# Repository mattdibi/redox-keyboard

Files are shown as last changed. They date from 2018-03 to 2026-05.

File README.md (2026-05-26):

<p align="center">
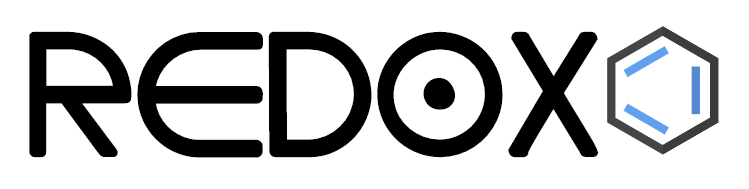
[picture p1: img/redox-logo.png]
Redox logo

QMK

</p>

<h3 align="center">The Redox project repository</h3>

<div align="center">

[]()




</div>

---

The Redox project is an open-source, [QMK (Quantum Mechanical Keyboard Firmware)](https://github.com/qmk/qmk_firmware) powered, ergonomic split mechanical keyboard. This repository will be used to share information about the project and instruction on how to use and assemble the Redox keyboard.

<p align="center">
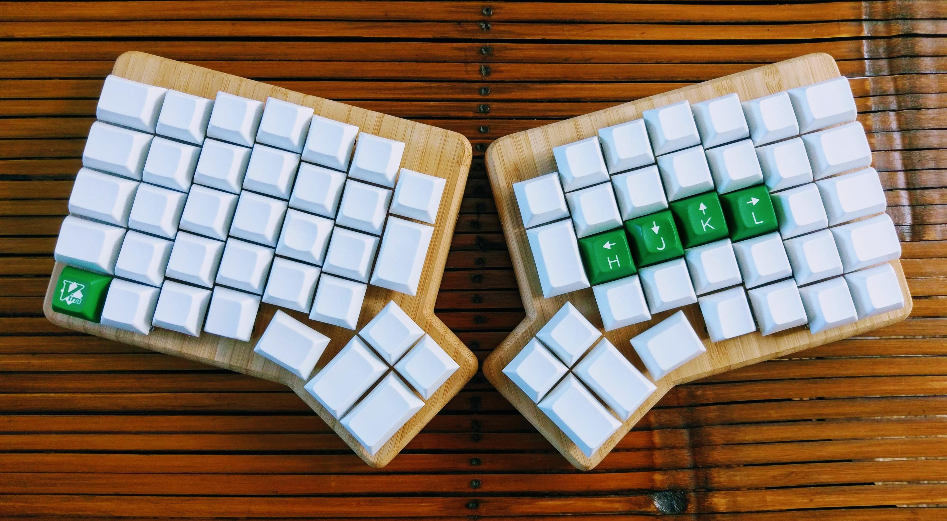
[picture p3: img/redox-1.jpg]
Redox

</p>

**Designer's bio**: [Mattia Dal Ben (aka u/TiaMaT102)](mailto:matthewdibi@gmail.com) obtained a master's degree in Electrical Engineering with a specialization in Computer Science at the University of Udine. Currently works as a Software Engineer in R&D department for a big IoT and Embedded Computers company. Mechanical keyboard enthusiast and maker, the Redox keyboard is the result of all of his passions.

## Rationale

The Redox is a keyboard project designed with ergonomics in mind. It uses Cherry MX style mechanical switches laid out in a 7x5 columnar stagger layout with components that can easily be sourced.

The design was heavily inspired by the [Ergodox keyboard](https://www.ergodox.io/), and its main goal is to reduce the size without sacrificing too many keys, hence the name **Re**duced Ergo**dox**.

As an Ergodox user I couldn't ignore the few flaws of the original design and in a moment of arrogance I tried to fix them, thus the Redox features:
- Easier to reach thumb cluster.
- Additional easy-to-reach rotated 1.25u thumb key.
- Reduced size.
- Reduced costs (the Redox uses Arduino Pro Micro instead of the Teensy 2.0).
- Either half can be plugged in to the PC since each half can act as the master.
- Either half can work as a standalone keyboard to be used as a macropad/gaming keyboard.
- RGB backlighting support.
- 3D-printer friendly case.
- Wireless [see section below](#wireless-implementations)
- [VIA](https://caniusevia.com/) compatible (thanks to [Harshit Goel](https://github.com/harshitgoel96))
- [ZMK firmware](https://zmk.dev/) compatible (thanks to [toddmok](https://github.com/toddmok))
- [KMK firmware](http://kmkfw.io/) compatible

## Related Projects

- [**Redox handwire**](https://www.thingiverse.com/thing:2704567): The first incarnation of the Redox keyboard. It consists of a 3D-printed case and a handwired matrix.
  - [Tilted Redox case](https://www.thingiverse.com/thing:2767216): tilted case for the Redox prototype by jschloer.
    - [Tilted redox case pro micro](https://www.printables.com/model/382413-tilted-redox-case-for-micro-and-usbc): Remix of the tilted case to support pro micro and usb c instead of TRRS. 

  - [couscous-kbd](https://gitlab.com/cschalkwijk/couscous-kbd): Redox-inspired parametric OpenSCAD keyboard design.
  - [Redox tenting kit](https://www.thingiverse.com/make:484843): modified base to support tenting, mini-USB for the interconnect, and a hole for microswitch for reset needed when uploading new firmware by [Lenbok](https://github.com/Lenbok).
  - [Iris-inspired Redox case](https://github.com/Lenbok/scad-redox-case): a case inspired both by the Redox rev1.0 and the Iris designed with OpenSCAD by [Lenbok](https://github.com/Lenbok).
  - [Redodactyl keyboard](https://www.reddit.com/r/MechanicalKeyboards/comments/9j5pw5/enter_the_redodactyl_first_build/): handwired 3D printed Dactyl-inspired Redox variant by u/darknao.
- [**Redox Manuform**](https://www.thingiverse.com/thing:3503380): full rework of the Redox case inspired by the Dactyl Manuform. Designed by [Fosk\_LL](https://www.thingiverse.com/Fosk_LL/about).
- [**Redox rev1.0**](https://github.com/mattdibi/redox-keyboard/tree/master/redox): the Redox rev 1.0 is the first commercially available version of the Redox keyboard.
	- Rev1.0 PCBs: available at [Falbatech's store](https://falbatech.click/products/REDOX-PCB-Electrical-Boards-Set-of-2-p613836203)
    - Firmware sources:
        - [QMK firmware for Redox](https://github.com/mattdibi/qmk_firmware/tree/master/keyboards/redox)
        - [KMK firmware for Redox](https://github.com/KMKfw/kmk_firmware/tree/master/boards/redox)
	- 3D-printable cases:
        - [3D printable case](https://www.thingiverse.com/thing:2886662), freely available.
        - [Redox keyboard case (high profile)](https://www.thingiverse.com/thing:3825752), by [Michele Ferri](https://www.thingiverse.com/sako83/about).
        - [Travel-friendly Redox Keyboard case](https://www.thingiverse.com/thing:3607303), by [Fosk\_LL](https://www.thingiverse.com/Fosk_LL/about).
        - [Redox Neodox case](https://github.com/Pastitas/Redox-neodox-Case), by [Pastitas](https://github.com/Pastitas)
        - [Redox big battery](https://github.com/marco-silvestri/redox-big-battery), by [Marco Silvestri](https://github.com/marco-silvestri).
	- Commercially available cases:
		- [Falbatech's bamboo cases with tilt kit](https://falbatech.click/products/REDOX-Standard-LIFT-Bamboo-Wood-Case-with-oil-finish-p613843480)
		- [Falbatech's fullhand bamboo cases](https://falbatech.click/products/search?keyword=redox%20fullhand%20bamboo)
- [**Redox rev1.0W**](https://github.com/mattdibi/redox-keyboard/tree/master/redox-w): the Redox rev 1.0W is the wireless version of the Redox keyboard.
    - Rev1.0W PCBs: gerbers available in [this repo](https://github.com/mattdibi/redox-keyboard/tree/master/redox-w/rev1.0W).
    - Falbatech's Rev1.0W Hot-swap PCBs: available at [Falbatech's store](https://falbatech.click/products/REDOX-Wireless-PCB-Electrical-Boards-Set-of-2-receiver-PCB-p613839986) (Incompatible with the 3D-printable cases down below)
    - Firmware sources:
        - [QMK firmware for Redox wireless](https://github.com/mattdibi/qmk_firmware/tree/master/keyboards/redox_w)
        - [Nordic MCUs firmware for Redox wireless](https://github.com/mattdibi/redox-w-firmware)
	- 3D-printable cases:
        - [3D printed case](https://github.com/mattdibi/redox-keyboard/tree/master/redox-w/case), freely available.
        - [Redox Neodox case](https://github.com/Pastitas/Redox-neodox-Case), by [Pastitas](https://github.com/Pastitas)
    - Commercially available cases (only compatible with the Falbatech's store PCBs):
        - [Falbatech's bamboo cases with tilt kit](https://falbatech.click/products/REDOX-Wireless-Standard-LIFT-Bamboo-Wood-Case-with-oil-finish-ver-1-p613842405)
		- [Falbatech's fullhand bamboo cases](https://falbatech.click/products/search?keyword=redox%20wireless%20bamboo%20fullhand)
- [**Redox rev2.0WHS**](https://github.com/mattdibi/redox-keyboard/tree/master/redox-w): the Redox rev 2.0WHS is the wireless hot-swappable version of the Redox keyboard.
    - Rev2.0WHS PCBs: gerber files available [here](https://github.com/mattdibi/redox-keyboard/tree/master/redox-w/rev2.0WHS/pcb)
    - Firmware sources:
        - [QMK firmware for Redox wireless](https://github.com/mattdibi/qmk_firmware/tree/master/keyboards/redox_w)
        - [Nordic MCUs firmware for Redox wireless](https://github.com/mattdibi/redox-w-firmware)
	- 3D-printable case:
        - [3D printed case](https://github.com/mattdibi/redox-keyboard/tree/master/redox-w/rev2.0WHS/case), freely available.

## Wireless Implementations

The Redox keyboard uses three different wireless implementations, differentiated by firmware:
 - *QMK based*: Leveraging the [Gazel protocol](https://developer.nordicsemi.com/nRF5_SDK/nRF51_SDK_v5.x.x/doc/5.2.0/html/a00140.html). It needs its own PCB and a receiver dongle (see [Redox Wireless](https://github.com/mattdibi/redox-keyboard/tree/master/redox-w) for details) and needs three YJ-14015 MCUs + a Pro Micro compatible controller.
 - *ZMK based*: Leveraging the Bluetooth protocol. It is based on the [Redox wired PCB](https://github.com/mattdibi/redox-keyboard/tree/master/redox) and the [nice!nano](https://nicekeyboards.com/nice-nano/) controller.
 - *KMK based*: Adding [Bluetooth Split](http://kmkfw.io/docs/split_keyboards#bluetooth-split-aka-no-trrs-currently-in-testing) code to `boards/redox/main.py`. Combined with a [compatible](http://kmkfw.io/docs/Officially_Supported_Microcontrollers) wireless controller completes wireless configuration. Would advice adding [Bluetooth keycodes](http://kmkfw.io/docs/keycodes#bluetooth-keys) in keymap; `keyboard.keymap` element in `main.py`.

 The notable differences for the three implementations are as follows:
 - _Battery life_: QMK Redox Wireless uses two CR2032 coin cell batteries which last [approximately one year (YMMV)](https://github.com/mattdibi/redox-keyboard/tree/master/redox-w#battery-usage), while the nice!nano support LiPo rechargable batteries (you can choose the capacity you want but expect them to last for a [few weeks on a single charge](https://zmk.dev/power-profiler)).
 - _Flexibility_: The receiver dongle limits the flexibility of QMK Redox Wireless.
 - _Cost_: The 3x YJ-14015 + Pro Micro combo is cheaper than two wireless controllers required for ZMK and wireless KMK.
 - _Range_: Bluetooth implementations, of ZMK and KMK, should be more capable than what can be achieved with the QMK Redox Wireless (At this point in time, I lack the evidence to support these claims though).

## Physical Key Layout

<p align="center">
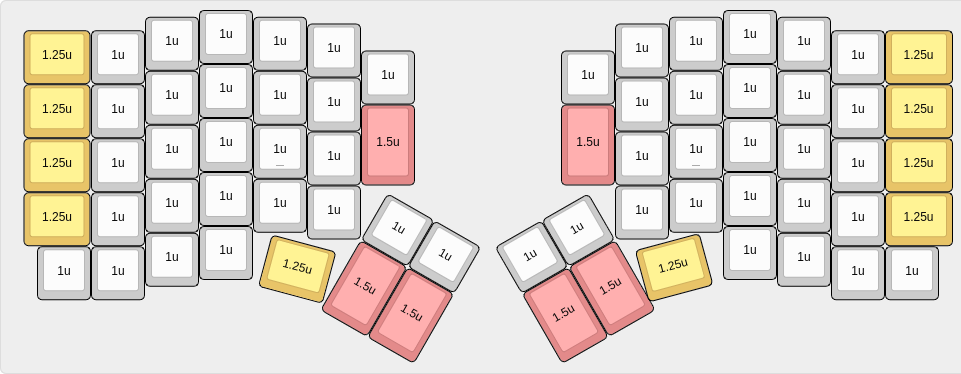
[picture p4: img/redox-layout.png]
Redox layout

</p>

### Keycaps

| Size  | Qty | Notes |
|---|:---:|:---:|
| 1.5u  | 6 | |
| 1.25u |  10 | You can get away with 8 if you use two 1u keycaps for the 1.25u rotated keys |
| 1u |  54 | |

> :information_source: On [pimpmykeyboard.com](https://pimpmykeyboard.com/sa-1976-keyset-two-shot/) site you can find a SA 1976 keyset kit specifically made for the Redox keyboard: the "Ergo Redox kit (12 keys)".

## Affiliations

In partnership with Falbatech you can now use the code "**mattdibi05**" on Falbatech's store for a 5% OFF special discount.

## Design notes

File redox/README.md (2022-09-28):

# Redox rev 1.0

The Redox rev 1.0 is the first commercially available version of the Redox keyboard.

Hardware availability:
  - [Falbatech](https://falba.tech/)

## Summary

  - [Bill of materials](#bill-of-materials)
  - [Other assembly guides](#other-assembly-guides)
  - [Assembly guide](#assembly-guide)
  - [Firmware](#firmware)
  - [Hot swappable mod](#hot-swappable-mod)
  - [RGB Underglow](#rgb-underglow)

## Bill of materials

| Qty | Item | Notes |
|----:|---|---|
|  70 | Cherry MX compatible switches | |
| 2 | Redox PCBs | [Available here](https://falba.tech/product/redox-pcb-electrical-boards-set-of-2/)|
|  70 | 1N4148 diodes | SMD diodes can also be used |
| 2 | PJ-320A 4 poles 3.5 mm TRRS connectors | |
| 2 | 4.7 kOhm resistors | Need to be soldered on one half only |
| 2 | Through hole momentary switch | Dimensions 6mm x 6mm x 4.3mm |
| 2 | Arduino Pro Micro compatible microcontrollers | Beware of the infamous Green Pro Micro, see note below. |
| 1 | TRRS cable | |
| 1 | USB micro cable | |
|  70 | Cherry MX compatible keycaps | 10x 1.25u keycaps, 6x 1.5u keycaps, 54x 1u keycaps  |
|  14 | WS2812/WS2812B leds | Optional RGB-underglow |

> :warning: Pay attention to the Pro Micro you use in this project. Online you can find the infamous **Green Pro Micros** which have the same pinout of the normal Pro Micro but use a different power circuitry. Being the Redox a split keyboard that relies on detecting which side is directly powered to find which side is the master, these clones are not suited for the task. A more detailed explanation [here](http://www.40percent.club/2017/09/green-pro-micro.html). Please note that they can come in different colors, not necessarily green.

> :warning: Before you start, flash the [Firmware](#firmware) to the ProMicros to make sure they are alright.

## Other assembly guides

External links to some other guides to building the Redox keyboard:

- ["*Build your own keyboard*"](https://medium.com/@costask/build-your-own-keyboard-5df65cb68839) by @costask.
- [Imgur build log](https://imgur.com/a/a6ck2Nc) (3D printed case).
- ["*First Homebrew Keyboard -redox Build Log-*"](https://x1.inkenkun.com/archives/6007) by [インケンch](https://www.youtube.com/channel/UCXJZdip7JmW74HQHCtfYzFw) (Japanese only)
- ["*Split Keyboard Build*"](https://kubami.com/articles/split-keyboard-build/) by Kuba Misiorny @kubami.
- [Wooden case build with hand tools](https://www.instructables.com/Redox-Keyboard-With-Wooden-Case/) by Cédric Bosdonnat

### Video guides

Two great video guides by [インケンch](https://www.youtube.com/channel/UCXJZdip7JmW74HQHCtfYzFw) (Japanese only).

<p align="center">
<a href="http://www.youtube.com/watch?v=EVRlU_eR9j4">Redox hardware assembly</a>
<a href="http://www.youtube.com/watch?v=jRIRdfIIa1Q">Redox firmware</a>
</p>

Another great guide by [Antonio Raptors](https://www.youtube.com/channel/UCNYbiq6AH8AdYTKMokKaviQ) (Spanish only).

<p align="center">
<a href="https://www.youtube.com/watch?v=wRvfs1tUpZ4">Como hacer un teclado mecánico para diseño / gaming - REDOX ESPAÑOL</a>
</p>

## Assembly guide

<p align="center">
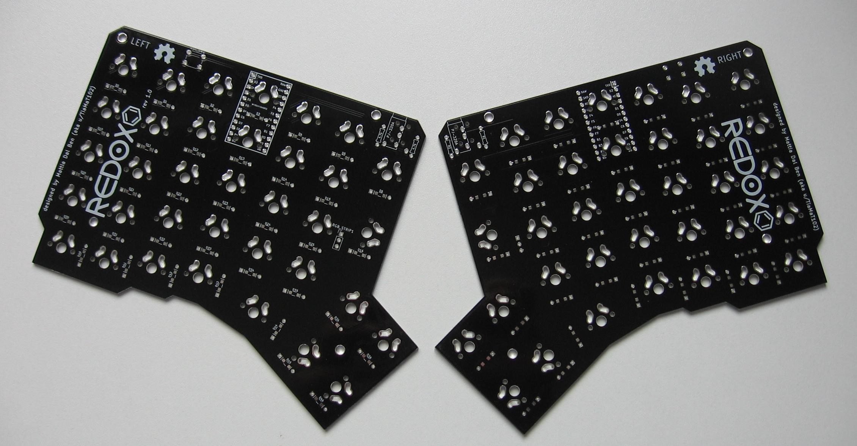
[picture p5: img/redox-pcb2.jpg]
Redox PCBs

</p>

Installation steps:

- Solder components:
  1. Solder 1N4148 diodes. Keep the diode legs for the right hand controller installation.
  2. Solder PJ-320A connectors.
  3. Solder momentary switches.
  4. Solder 4.7k Ohm resistors **on one half only**. If you are going for the RGB-underglow ignore this step.
  5. Solder the Pro Micro header pins (**do not solder the Pro Micro controllers yet**). This step may differ depending on which case you're using. Refer to the following:
    * See 3D-Printed case [right hand controller installation detail](#3d-printed-case-assembly).
    * See Falbatech's [bamboo case](#falbatechs-bamboo-case-assembly).
    * See [socketed Pro Micro installation guide](#pro-micro-sockets).
  6. Optional see [RGB-underglow instructions](#rgb-underglow).
- Flip the PCBs.
- Solder switches to the PCB.
  * If you want hot swappable switches, see
    [the hot swappable switch instructions](#hot-swappable-switches).
- Flip the PCBs again.
- Solder Pro Micros to the header pins **following the PCB labeling**. The Pro Micro on the right half should be installed with the bottom facing the Redox PCB, the Pro Micro on the left half should be installed with the bottom facing away from the PCB. See [pictures](#left-hand-back-side-1) for details.

##### Right hand back side:
<p align="center">
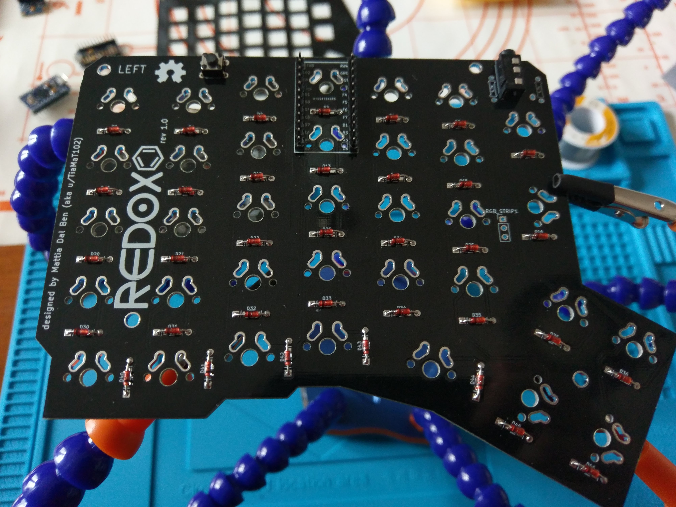
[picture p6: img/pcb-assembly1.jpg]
Right hand back side

</p>

##### Left hand back side:
<p align="center">
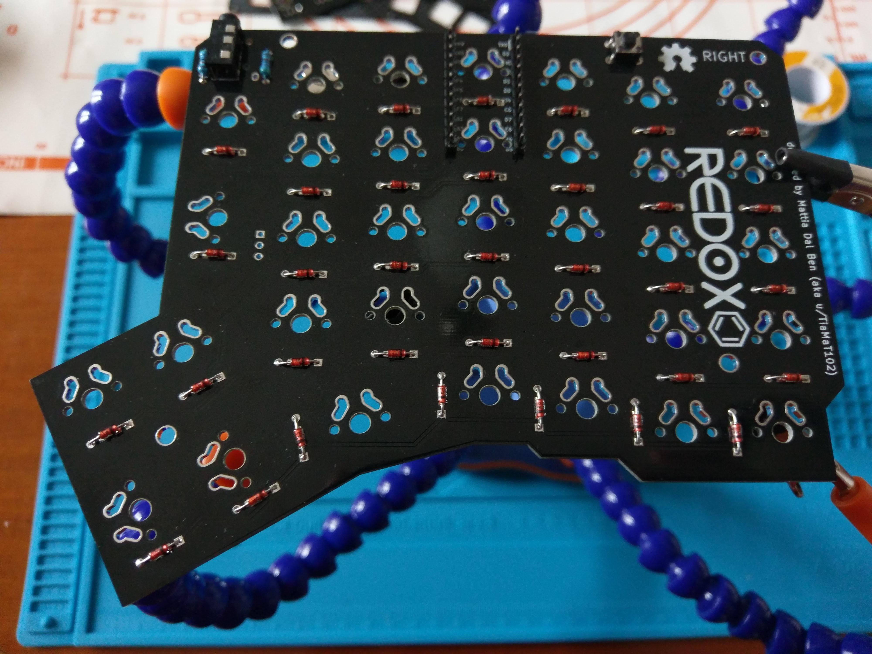
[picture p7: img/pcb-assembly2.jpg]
Left hand back side

</p>

##### Diode installation detail:
<p align="center">
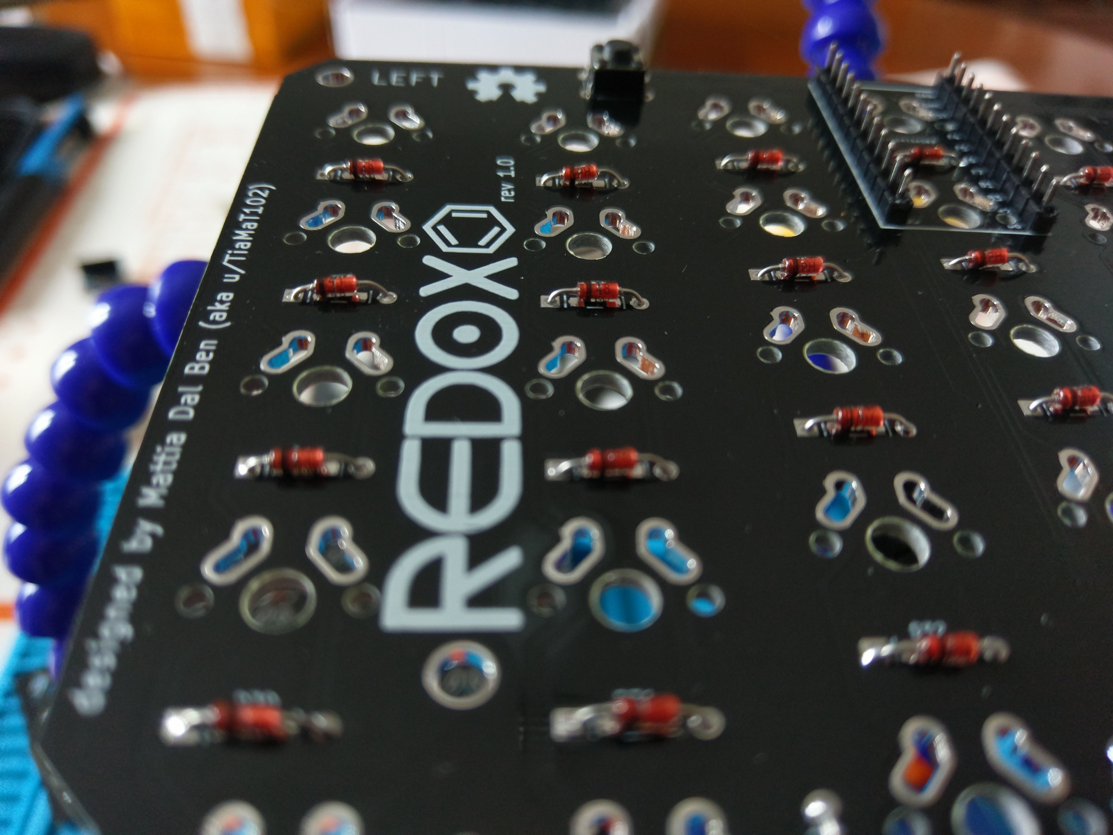
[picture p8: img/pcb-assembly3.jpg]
Diode installation detail

</p>

### 3D Printed case assembly

To lower the build costs I designed a 3D printable case which you can find in this repository or on [thingiverse](https://www.thingiverse.com/thing:2886662), feel free to modify it to best suit your needs.

<p align="center">
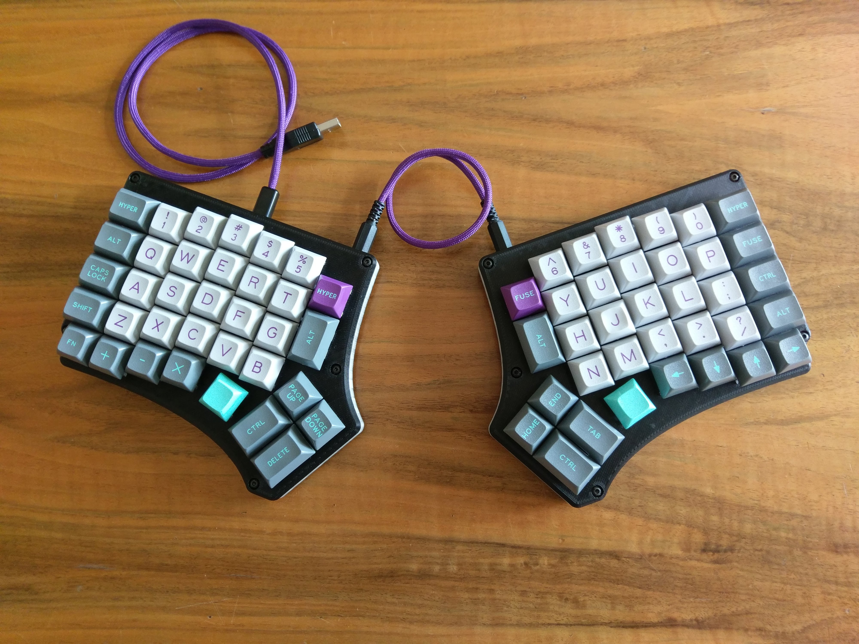
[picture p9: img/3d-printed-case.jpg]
3D printed case

</p>

Parts:

| Qty | Item | Notes |
|----:|---|---|
| 1 | Left top plate | [RedoxRev1TopLeft.STL](https://github.com/mattdibi/redox-keyboard/blob/master/redox/case/RedoxRev1TopLeft.STL)|
| 1 | Left bottom | [RedoxRev1BottomLeft.STL](https://github.com/mattdibi/redox-keyboard/blob/master/redox/case/RedoxRev1BottomLeft.STL)|
| 1 | Right top plate | [RedoxRev1TopRight.STL](https://github.com/mattdibi/redox-keyboard/blob/master/redox/case/RedoxRev1TopRight.STL)|
| 1 | Right bottom | [RedoxRev1BottomRight.STL](https://github.com/mattdibi/redox-keyboard/blob/master/redox/case/RedoxRev1BottomRight.STL)|
|  10 | M3 x 8mm (or 5mm) screws | |

For the Pro Micro installation on the right hand use the diodes legs leftover from previous steps as this will make the controller's USB port much closer to the PCB, this is needed for the USB connector to fit in the 3D printed case. If you're using Falbatech's bamboo case this is not needed and you can use standard header pins. Right hand controller installation detail:

1. Use a breadboard to keep the diode's legs from falling.
2. Solder the diode's legs in place. You want to have the Pro Micro as close to the Redox's PCB as possible.
3. Cut the excess.
4. Apply some electrical tape under the controller to prevent shorts.
5. Install your preferred switches (**remember: the controller installation is the last step**).
6. Solder the controllers in place.

<p align="center">
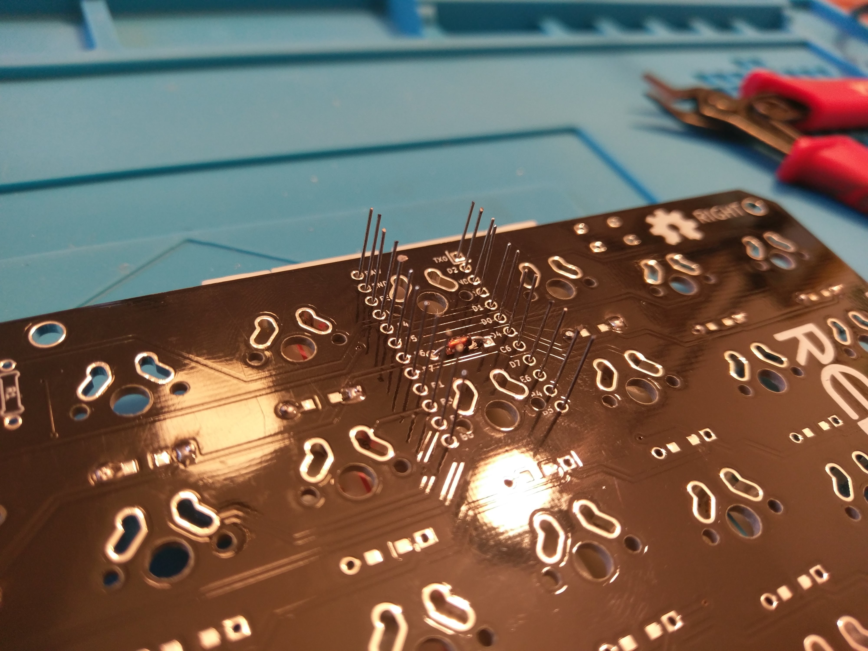
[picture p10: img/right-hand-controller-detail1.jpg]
Right hand controller installation detail

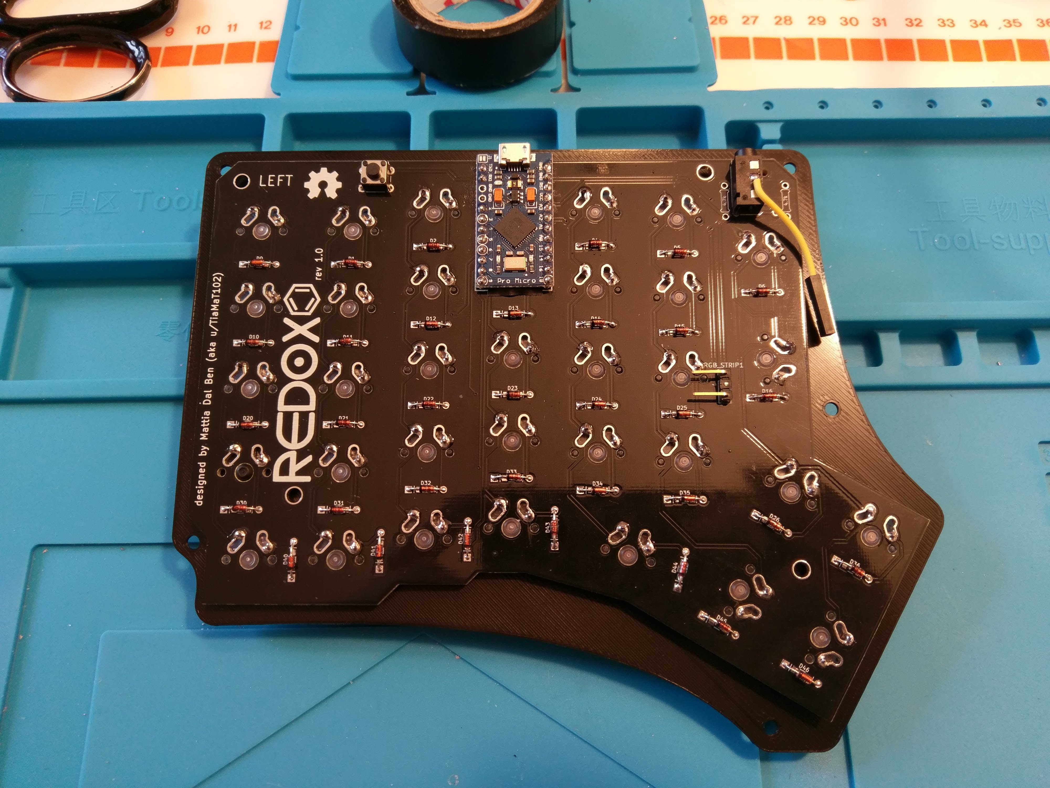
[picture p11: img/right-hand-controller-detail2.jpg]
Right hand controller installation detail

</p>

Here's some measurements of the Pro Micro installation:

<p align="center">
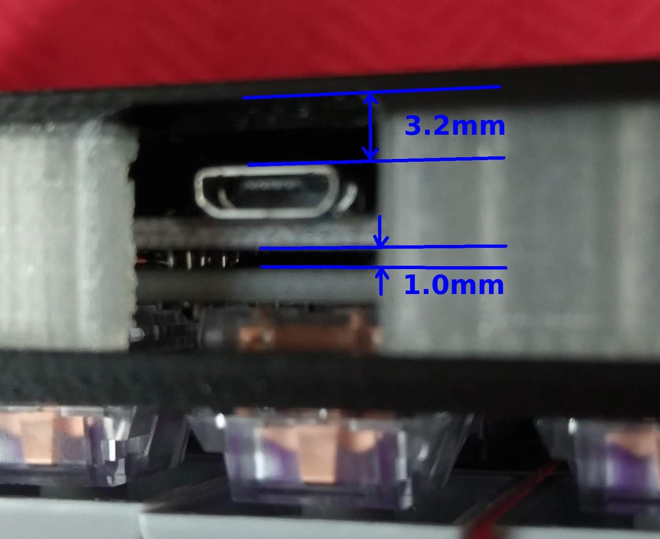
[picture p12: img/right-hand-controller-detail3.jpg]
Right hand controller installation detail

</p>

### Falbatech's bamboo case assembly

If you're using Falbatech's bamboo case the use of the diode's legs is not needed and you can use standard header pins

<p align="center">
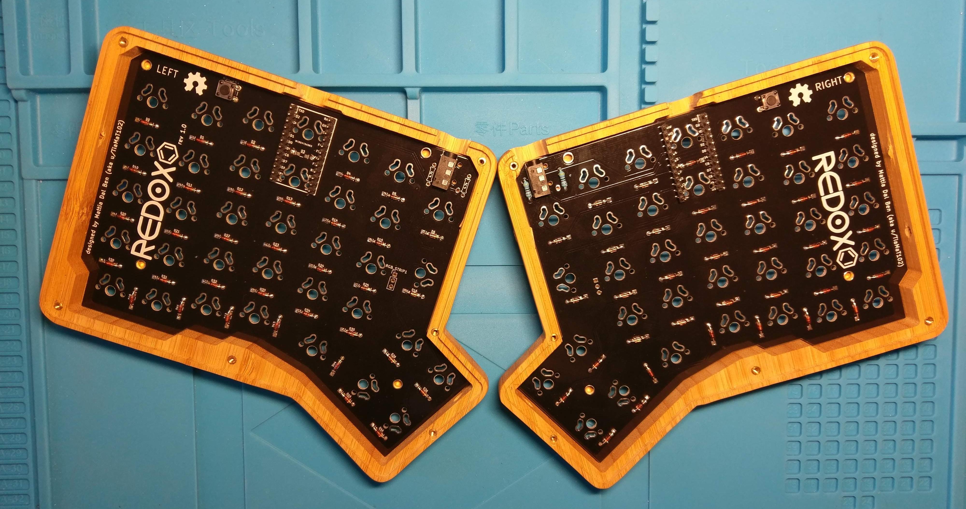
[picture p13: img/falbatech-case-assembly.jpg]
Falbatech's case assembly

</p>

## Firmware

> :warning: If you have a Redox with RGB backlight installed you **MUST** use the serial connection. For details see [the RGB underglow firmware instructions.](#rgb-underglow)

The Redox uses QMK for its firmware, follow the QMK installation instructions [here](https://docs.qmk.fm/#/getting_started_build_tools), then compile and burn the firmware on both halves as follows:

```sh
$ cd path/to/qmk_firmware
$ make redox/rev1:default:avrdude
```

After issuing this command you should see the following output:

```sh
Detecting USB port, reset your controller now.....
```

Now you should reset the Pro Micros using the reset button as seen in the following picture:

<p align="center">
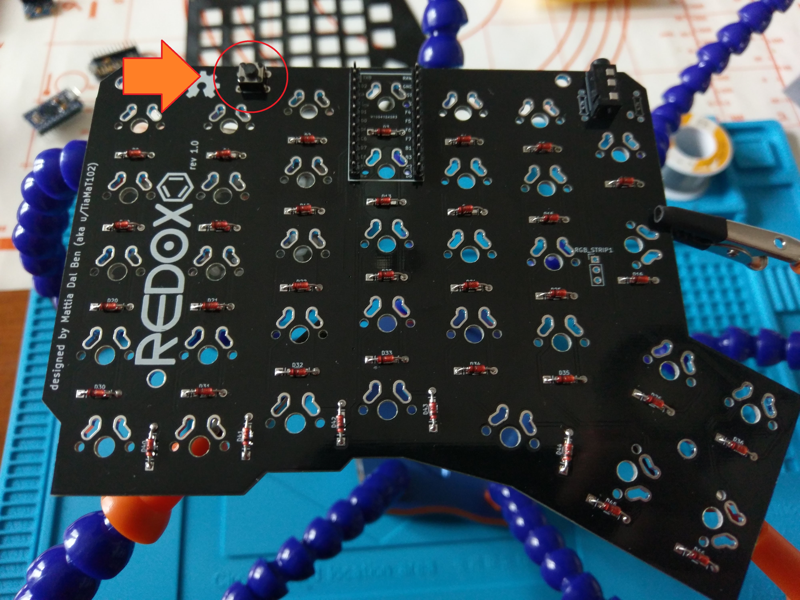
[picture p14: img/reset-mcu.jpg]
Reset button

</p>

> :warning: You always need to burn the firmware on **BOTH** halves of the keyboard.

> :warning: Failing to upload Redox Firmware on Linux. Please refer to [issue #8060](https://github.com/qmk/qmk_firmware/issues/8060) of QMK firmware.

You can find the code for the Redox here: [QMK - Redox keyboard](https://github.com/qmk/qmk_firmware/tree/master/keyboards/redox).

In the [firmware/](https://github.com/mattdibi/redox-keyboard/tree/master/redox/firmware) folder I added some pre-built hex files with the default keymap for testing purpose. You can upload the firmware binaries directly using the command below:

```sh
avrdude -p atmega32u4 -P $(COM_PORT) -c avr109 -U flash:w:redox_rev1_default.hex
```

### Setting EE_hands to use either hands as master
If you define `EE_HANDS` in your `config.h`, you will need to set the EEPROM for the left and right halves.

The EEPROM is used to store whether the half is left handed or right handed. This makes it so that the same firmware file will run on both hands instead of having to flash left and right handed versions of the firmware to each half. To flash the EEPROM file for the left half run:
```
$ cd path/to/qmk/folder
avrdude -p atmega32u4 -P $(COM_PORT) -c avr109 -U eeprom:w:"./quantum/split_common/eeprom-lefthand.eep"
// or the equivalent in dfu-programmer
```
and similarly for right half
```
avrdude -p atmega32u4 -P $(COM_PORT) -c avr109 -U eeprom:w:"./quantum/split_common/eeprom-righthand.eep"
// or the equivalent in dfu-programmer
```

> :warning: Replace `$(COM_PORT)` with the port of your device (e.g. `/dev/ttyACM0`)

After you have flashed the EEPROM, you then need to set `EE_HANDS` in `keyboard/redox/keymaps/default/config.h` like so:

```c++
// ...
/* Use I2C or Serial, not both */

// #define USE_SERIAL
#define USE_I2C

/* Select hand configuration */

// #define MASTER_LEFT
// #define MASTER_RIGHT
#define EE_HANDS

#undef RGBLED_NUM
#define RGBLIGHT_ANIMATIONS
// ...
```

Then rebuild the hex files and reflash.

Note that you need to program both halves, but you have the option of using different keymaps for each half. You could program the left half with a QWERTY layout and the right half with a Colemak layout using bootmagic's default layout option. Then if you connect the left half to a computer by USB the keyboard will use QWERTY and Colemak when the right half is connected.

## Hot swappable mod

With a few modifications to the original design, it is possible to make a
Redox with hot swappable switches and socketed Pro Micros. This was tested
with Falbatech's PCBs and PVC cases. The switch hotswap mod should work with
any case with a top plate that the switches snap into, with about a millimeter
of extra clearance between the top plate and the PCB, and another extra half
millimeter or so between the PCB and case bottom. If your (non-Falba) PCBs
have particularly small diameter thru-holes for switch pins, check the
Mill-Max 7305 spec sheet to ensure the receptacles will fit.

### Extended bill of materials

| Qty | Item | Notes |
|----:|---|---|
| 1 | Peel-A-Way Sockets (82 pin strip) | Available from [keeb.io](https://keeb.io/collections/frontpage/products/peel-a-way-sockets-for-pro-micros?variant=12972145344606)|
| 140 | Mill-Max 7305 Pin Receptacles | Available from [Digi-Key](https://www.digikey.com/product-detail/en/mill-max-manufacturing-corp/7305-0-15-15-47-27-10-0/ED1039-ND/1765737) or [Mouser](https://www.mouser.com/ProductDetail/Mill-Max/7305-0-15-15-47-27-10-0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)|
| 1 | Roll of Kapton tape | |

Some extra Mill-Max receptacles may come in handy, in case of soldering
mistakes or manufacturing defects.

### Pro Micro Sockets

<p align="center">
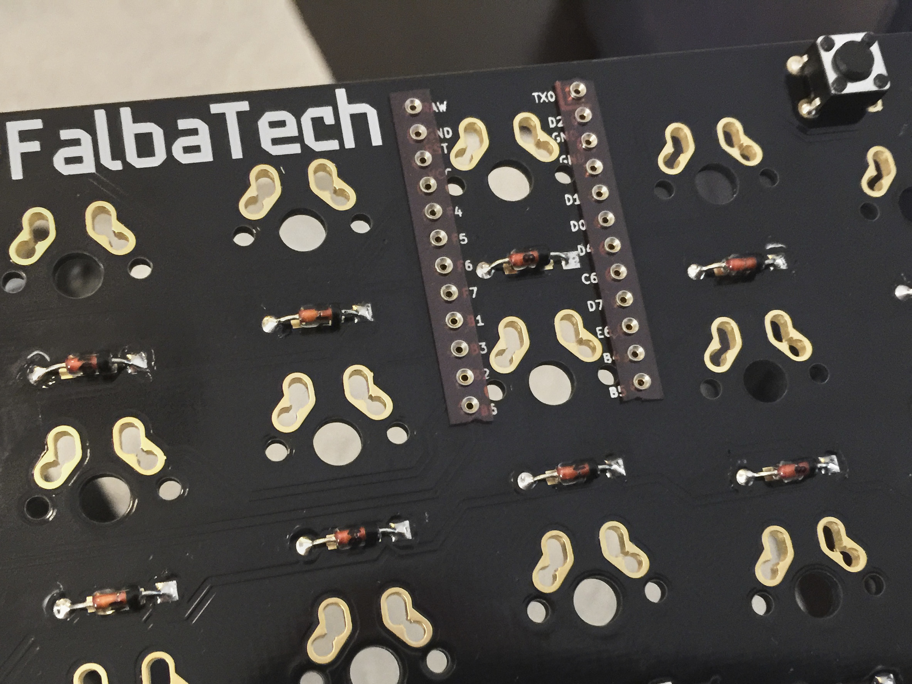
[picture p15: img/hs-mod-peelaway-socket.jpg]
Pro Micro Peel-A-Way socket top detail

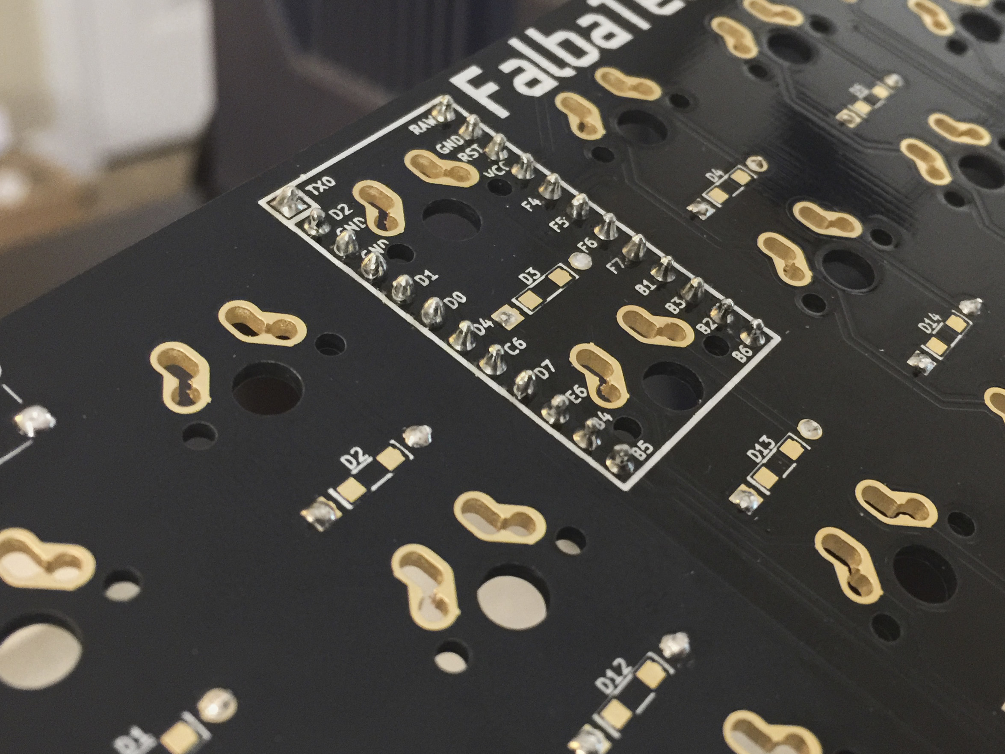
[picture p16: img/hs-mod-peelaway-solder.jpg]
Pro Micro Peel-A-Way socket solder detail

</p>

Socketing your microcontrollers will allow you to swap out broken Pro Micros,
or swap any Pro Micro pin-compatible microcontroller (with, for example, USB-C)
into a finished build. Before you begin, you'll want to follow the
[standard assembly guide steps](#assembly-guide)
for soldering 1N4148 diodes, PJ-320A connectors,
momentary switches, and any resistors you'll be using. Remember to
**trim the legs off your diodes and keep them**, as we'll be using the legs to
make pins for each Pro Micro.

Installation steps, after initial soldering:

1. Using scissors or flush cutters, cut out two 12-pin strips of Peel-A-Way
   sockets.
2. With the bottom side of the PCB (the side with the diodes, momentary
   switch, and TRRS connector visible) facing up, place the cut Peel-A-Way
   socket strips into the thru-holes where the Pro Micro headers would
   usually go.
3. Temporarily fasten the Peel-A-Way sockets to the PCB with Kapton tape.
4. Flip over the PCB.
5. Solder the sockets into the thru-holes.
6. Install your switches. This step differs depending on whether you plan
   on making your switches hotswappable:
   * For fixed, non-hotswap switches, follow [the standard assembly guide](#assembly-guide).
   * Hotswap switch builds should follow [the hot swappable switch install guide](#hot-swappable-switches).
7. Flip and orient your Pro Micro so that its labels match the labels on your
   PCB, then cover the bottom of the Pro Micro in electrical or Kapton tape
   to prevent shorts.
8. Thread the least bent of your trimmed diode legs through the thru-holes
   in your Pro Micro and into the corresponding sockets on the PCB.
9. Keeping the Pro Micro as level as possible, solder the diode legs to the
   Pro Micro. It may help to keep a USB cable attached to the Pro Micro, to
   help ensure the port ends up in a usable orientation.
10. Trim the excess length of the diode legs off of the top of the Pro Micro.
11. Repeat these steps for the other half of your Redox.

### Hot Swappable Switches

> :warning: A few things to keep in mind:
> - Some switch pins (so far, Kailh Box Royals) may be slighly too wide to
>   fit the Mill-Max receptacle. When in doubt, try it with spare receptacles.
> - The only thing keeping the PCB attached to the top plate is the switches;
>   if you remove too many (more than half per side), the PCB will detach and
>   fall into the case. Try to swap only a few switches at once.

<p align="center">
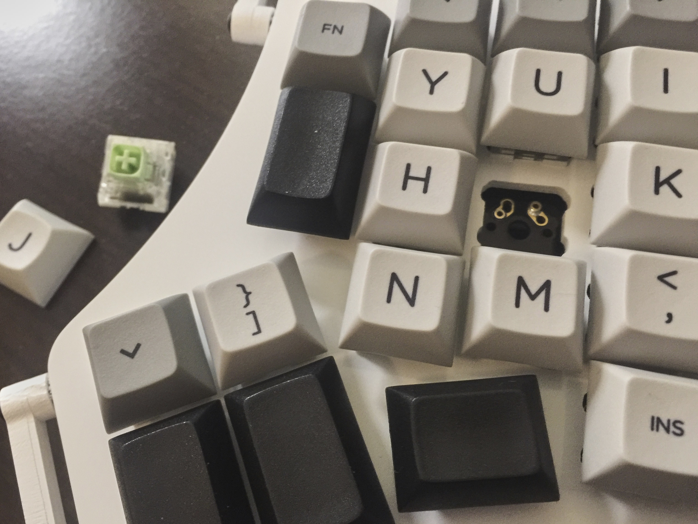
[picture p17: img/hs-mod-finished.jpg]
Finished Redox with hotswap switches

</p>

To build a Redox with hot swappable switches, follow these steps instead of
the switch installation instructions in the standard build guide. Soldering
Mill-Max receptacles is trickier than soldering bare switch pins; a small
iron tip, small diameter solder, and relatively low temperatures are
recommended.

1. Take each of your switches and push a Mill-Max receptacle fully onto each
   pin. One end of the receptacle has a small ring around it that makes it
   wider than the other end; the receptacle should be oriented so that the
   wide end is touching the switch housing (and will end up on the top,
   plate-facing side of the PCB in the assembled keyboard).
2. Snap switches into each of the four corners of your top plate, and two
   more into the mounting holes that will be directly above the Pro Micro
   in the assembled keyboard.
3. Flip over the top plate and install the PCB.
   - The receptacles might be a tight fit for the PCB thru-holes; if so,
     press the PCB into the switches to make sure the PCB is fully mounted
     and level.
4. Install the rest of the switches, starting from the outside edges of the
   plate and moving inward.
   - Initially, installing switches will likely shift the surrounding unsoldered
     switches and the PCB out of position, so pinch any jostled switches and
     the PCB back together as you go.
   - Be careful not to apply too much pressure to the stem of the switch, as
     this could damage it.
5. Solder your switches, starting from the corners then going from the outside
   edges to the inner switches in roughly the same order as the previous step.
   - Before soldering each switch, apply pressure to the top of the switch
     and the bottom of the PCB a final time to ensure the switch, plate, and
     PCB are all properly seated.
   - Apply heat to the pin receptacle and pad, then melt your solder onto
     the pad. You will want a "volcano" shaped solder joint which fully
     encircles the bottom of the receptacle, but doesn't fill its inner
     surface.
   - If you need to test that you haven't accidentally soldered a pin
     permanently into its receptacle by allowing solder to spill into the
     inner surface of the receptacle, you can try and temporarily remove
     the switch as you would during a hot swap. Use a switch puller to depress
     the tabs on the top and bottom of the switch (or the left and right for
     the flipped 1.5u key switches), and gently pull up on the switch until
     it is free of the keyboard. Note that if the switch and receptacles are
     still hot, it might take some extra effort to pull out the switch.
     Next, snap the switch back into its socket, and fix any unsoldered
     switches that were knocked out of place during this process.
6. Repeat these steps for the other side of the keyboard.

##### Installing Mill-Max receptacles onto switch pins:
<p align="center">
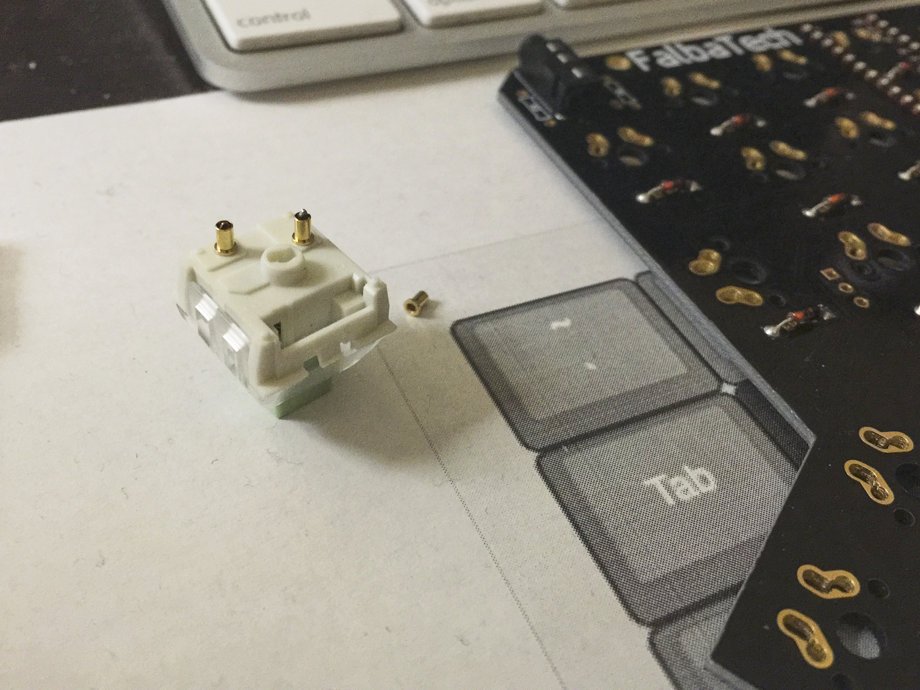
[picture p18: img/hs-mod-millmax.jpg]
Mill-Max receptacle installation

</p>

##### Pins, receptacles, and PCB in proper alignment:
<p align="center">
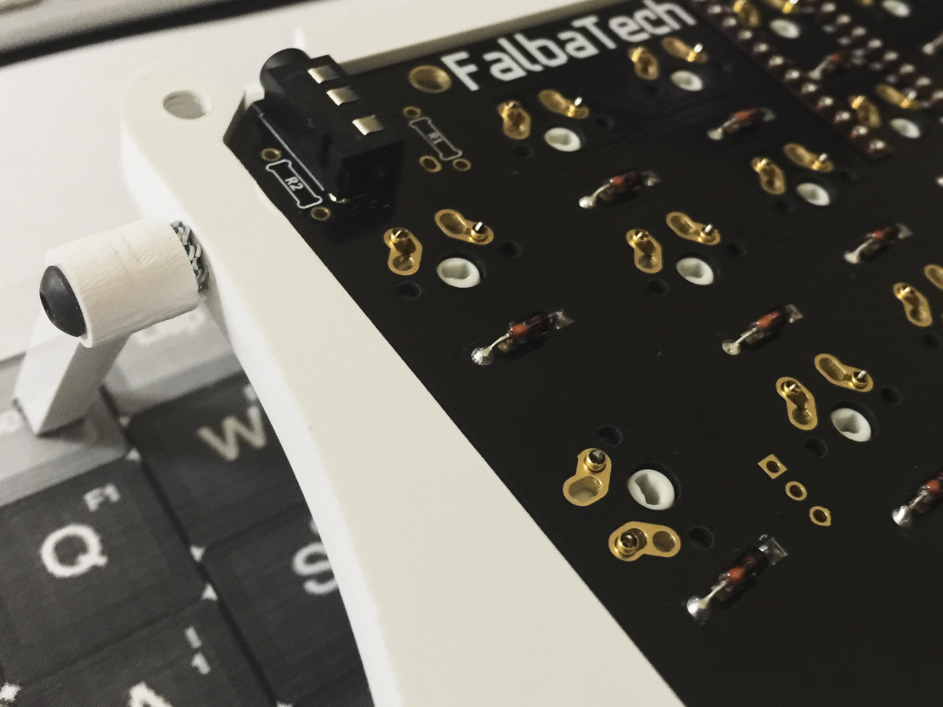
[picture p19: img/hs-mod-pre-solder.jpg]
Proper alignment of receptacles, pins, and PCB

</p>

##### Soldered hot swap receptacles:
<p align="center">
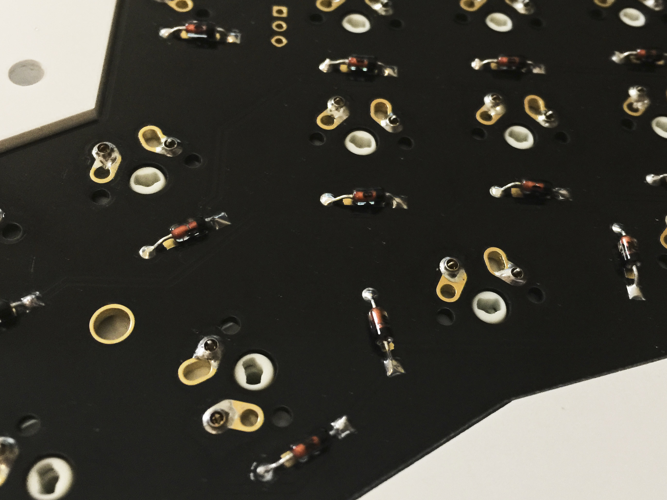
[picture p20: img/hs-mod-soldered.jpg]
Soldered hot swap receptacles

</p>

## RGB Underglow

> :warning: With this configuration:
> - You don't need to solder the 4.7k resistors since the I2C connection won't be used.
> - You can use only one hand as master.

Parts:
- [ ] WS2812/WS2812B LED strip
- [ ] 24 AWG (or smaller) stranded wire (white, red, black are good choices)

Data connection:

```
Led strip Headers -> DIN -> DO -> TRRS pad -> (TRRS to other side) -> TRRS pad -> DIN
```

### Assembly: LEFT hand as master (usually plugged in to the PC)
- On the LEFT hand:
  1. Solder the LED Strip headers as seen in the pictures below.
  2. Solder the DO Pin of the RGB strip to the TRRS pad as seen in the figures below.
- On the RIGHT hand:
  1. Solder VCC and GND of the RGB strip to the LED Strip headers.
  2. Solder the DIN Pin of the RGB strip to the TRRS pad as seen in the figures below.
- Flash the firmware with the serial and RGB Backlight options on, specifying the number of LEDs installed (see instruction [here](#rgb-underglow-firmware)).

##### Left hand back side:
<p align="center">
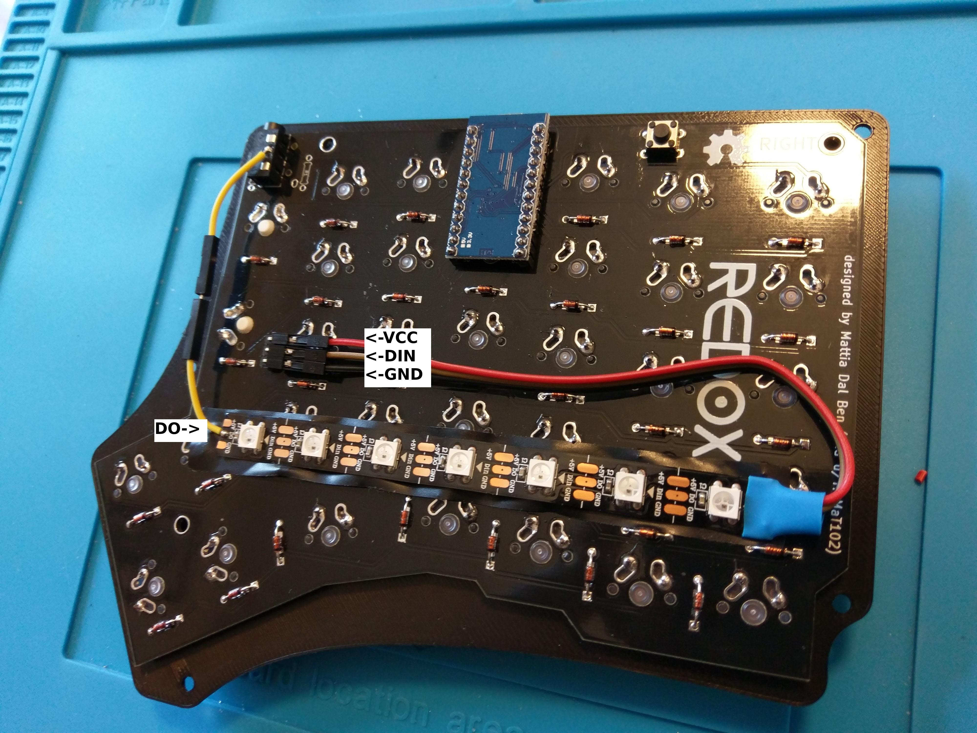
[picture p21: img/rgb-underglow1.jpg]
RGB underglow left hand backside

</p>

##### Right hand back side:

<p align="center">
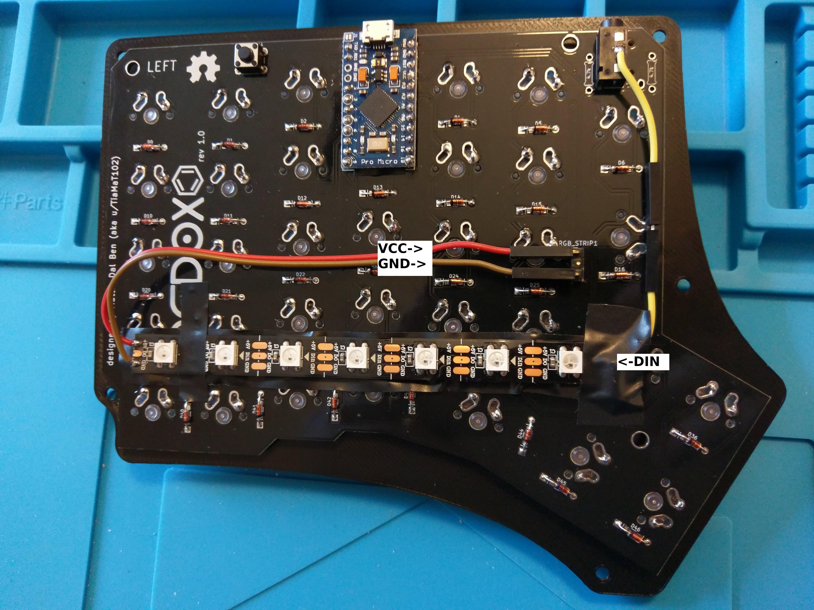
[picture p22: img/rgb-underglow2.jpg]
RGB underglow left hand backside

</p>

### Assembly: RIGHT hand as master
- On the RIGHT hand:
  1. Solder the LED Strip headers to the RGB strip.
  2. Solder the DO Pin of the RGB strip to the TRRS pad.
- On the LEFT hand:
  1. Solder VCC and GND of the RGB strip to the LED Strip headers.
  2. Solder the DIN Pin of the RGB strip to the TRRS pad.

### RGB Underglow firmware

To enable RGB backlighting you need to modify the default firmware as follows:
- Use serial communication instead of I2C.
- Set the master hand.
- Set the number of LED you installed.

To do this, modify `qmk_firmware/keyboards/redox/keymaps/default/config.h` as follows:

```c++
// ...

/* You need to use the sarial communication since we
used a cable to carry the data signal for the LED strip */
#define USE_SERIAL

/* Select hand configuration: you need to use as master
the hand that drives the LED strip */
#define MASTER_LEFT
// #define MASTER_RIGHT

/* Put the total number of led used here */
#undef RGBLED_NUM
#define RGBLIGHT_ANIMATIONS
#define RGBLED_NUM 14
#define RGBLIGHT_HUE_STEP 8
#define RGBLIGHT_SAT_STEP 8
#define RGBLIGHT_VAL_STEP 8

// ...
```

Then compile and burn the firmware on both controllers:

```sh
$ cd path/to/qmk_firmware
$ make redox/rev1:default:avrdude
```

## Layout

<p align="center">
Redox rev1.0 layout
</p>

[KLE Layout permalink](http://www.keyboard-layout-editor.com/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(%0A9%3B&@_y:-0.875&x:5.5%3B&=%25%0A5&_x:6.5%3B&=%5E%0A6%3B&@_y:-0.875&x:0.25&a:5&w:1.25%3B&=%60%0A%0A%0A%0A%0A%0ALayer%202&_a:4%3B&=!%0A1&_x:14.5%3B&=)%0A0&_a:5&w:1.25%3B&=-%0A%0A%0A%0A%0A%0ALayer%202%3B&@_y:-0.625&x:6.5%3B&=Layer%201&_x:4.5%3B&=Layer%201%3B&@_y:-0.75&x:3.5&a:4%3B&=E&_x:10.5%3B&=I%3B&@_y:-0.875&x:2.5%3B&=W&_x:1%3B&=R&_x:8.5%3B&=U&_x:1%3B&=O%3B&@_y:-0.875&x:5.5%3B&=T&_x:6.5%3B&=Y%3B&@_y:-0.875&x:0.25&a:5&w:1.25%3B&=TAB&_a:4%3B&=Q&_x:14.5%3B&=P&_a:5&w:1.25%3B&=%2F=%3B&@_y:-0.625&x:6.5&a:7&h:1.5%3B&=%5B&_x:4.5&h:1.5%3B&=%5D%3B&@_y:-0.75&x:3.5&a:4%3B&=D&_x:10.5%3B&=K%3B&@_y:-0.875&x:2.5%3B&=S&_x:1&n:true%3B&=F&_x:8.5&n:true%3B&=J&_x:1%3B&=L%3B&@_y:-0.875&x:5.5%3B&=G&_x:6.5%3B&=H%3B&@_y:-0.875&x:0.25&a:5&w:1.25%3B&=ESC&_a:4%3B&=A&_x:14.5%3B&=%2F:%0A%2F%3B&_a:5&w:1.25%3B&='%3B&@_y:-0.375&x:3.5&a:4%3B&=C&_x:10.5%3B&=%3C%0A,%3B&@_y:-0.875&x:2.5%3B&=X&_x:1%3B&=V&_x:8.5%3B&=M&_x:1%3B&=%3E%0A.%3B&@_y:-0.875&x:5.5%3B&=B&_x:6.5%3B&=N%3B&@_y:-0.875&x:0.25&a:5&w:1.25%3B&=SHIFT&_a:4%3B&=Z&_x:14.5%3B&=%3F%0A%2F%2F&_a:5&w:1.25%3B&=SHIFT%3B&@_y:-0.375&x:3.5%3B&=*%0A%0A%0A%0A%0A%0AALT&_x:10.5%3B&=Left%3B&@_y:-0.875&x:2.5%3B&=-&_x:12.5%3B&=Down%3B&@_y:-0.75&x:0.5%3B&=GUI&=+&_x:14.5%3B&=Up&=Right%3B&@_r:15&y:-2.625&x:5.75&w:1.25%3B&=%5C%0A%0A%0A%0A%0A%0ACTRL%3B&@_r:30&rx:6.5&ry:4.25&y:-1%3B&=PgUp&=PgDn%3B&@_h:1.5%3B&=Back%0A%0A%0A%0A%0A%0Aspace&_h:1.5%3B&=Del%3B&@_r:-30&rx:13&y:-1&x:-2%3B&=Home&=End%3B&@_x:-2&h:1.5%3B&=Enter&_h:1.5%3B&=Space%3B&@_r:-15&rx:0&ry:0&y:7.75&x:11.75&w:1.25%3B&=ALT)

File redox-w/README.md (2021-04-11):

## Redox-W (Wireless)

The Redox-W is the wireless version of the Redox keyboard, it comes in two flavours:

- **Rev 1.0W**: The first revision of the Redox Wireless.
- **Rev 2.0WHS**: Hot-swappable version of the Redox Wireless. It comes with some range improvements and limited compatibility with Rev1.0W cases (more on that in the [dedicated section](#case-compatibility)).

The two hardware revision share the firmware and the receiver dongle. In this page you'll find assembly instructions for both versions of the keyboard.

## Summary

  - [Bill of materials](#bill-of-materials)
  - [Receiver Assembly](#receiver-assembly)
  - [Transmitters Assembly](#transmitters-assembly)
    - [Rev 1.0W transmitters assembly](#rev-10w-transmitters-assembly)
    - [Rev 2.0WHS transmitters assembly](#rev-20whs-transmitters-assembly)
  - [Firmware](#firmware)
  - [Battery usage](#battery-usage)
  - [Case compatibility](#case-compatibility)

## Bill of materials

#### Transmitters

| Qty | Item | Notes |
|----:|---|---|
| 2 | Redox Wireless Transmitters PCB | Available versions: [Rev.1.0W](https://falba.tech/), [Rev.2.0WHS](https://www.pcbway.com/project/shareproject/Redox_Wireless_rev2_0WHS.html) |
|  70 | Cherry MX compatible switches | |
|  70 | Kailh PCB sockets CPG151101S11 | Rev.2.0WHS **only** |
| 2 | YJ-14015 modules (Core51822B clones) | [aliexpress](https://www.aliexpress.com/item/NRF51822-Core51822-BLE-4-0-Bluetooth-2-4G-Wireless-Module-Antenna-Board-For-ULP-SPI-I2C/32842154172.html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,searchweb201602_1_10065_10068_10843_10059_10884_10887_10696_100031_10084_10083_10103_10618_10304_10307_10820_10821_10302,searchweb201603_60,ppcSwitch_5&algo_expid=1dded059-5054-4890-bcc4-6face1150a21-1&algo_pvid=1dded059-5054-4890-bcc4-6face1150a21&priceBeautifyAB=0)
|  70 | SOD-123 1N4148/1N4148W diodes | 1N4148 THT diodes can also be used |
| 2 | Keystone 3034 SMT battery holders | [digikey](https://www.digikey.com/product-detail/en/keystone-electronics/3034/36-3034-ND/4499289)|
| 2 | JS102011SAQN SMT slide switch | [digikey](https://www.digikey.com/product-detail/en/c-k/JS102011SAQN/401-1999-1-ND/1640114)|
| 2 | Right angle 0.1" header (1x4pin) | |

#### Receiver

| Qty | Item | Notes |
|----:|---|---|
| 1 | Redox receiver PCB | [PCB manufacturing link](https://www.pcbway.com/project/shareproject/Redox_Wireless_Receiver.html) |
| 1 | YJ-14015 module (Core51822B clone) | [aliexpress](https://www.aliexpress.com/item/NRF51822-Core51822-BLE-4-0-Bluetooth-2-4G-Wireless-Module-Antenna-Board-For-ULP-SPI-I2C/32842154172.html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,searchweb201602_1_10065_10068_10843_10059_10884_10887_10696_100031_10084_10083_10103_10618_10304_10307_10820_10821_10302,searchweb201603_60,ppcSwitch_5&algo_expid=1dded059-5054-4890-bcc4-6face1150a21-1&algo_pvid=1dded059-5054-4890-bcc4-6face1150a21&priceBeautifyAB=0) |
| 1 | Arduino Pro Micro compatible microcontroller  | |
| 1 | 1117 3.3v regulator in SOT223 | [digikey](https://www.digikey.com/product-detail/en/diodes-incorporated/AZ1117IH-3.3TRG1/AZ1117IH-3.3TRG1DICT-ND/5699682)|
| 2 | 330 Ohm 0805(2012 metric) SMD resistors | Default configuration. Values depends on LED color, see [below](#resistor-values)|
| 2 | 220 Ohm 0805(2012 metric) SMD resistors | Default configuration. Values depends on LED color, see [below](#resistor-values)|
| 3 | 1.5k Ohm 0805(2012 metric) SMD resistors | Default configuration. See [below](#resistor-values)|
| 1 | Red 0805(2012 metric) SMD standard LED | Default configuration. |
| 1 | Blue 0805(2012 metric) SMD standard LED | Default configuration. |
| 1 | Green 0805(2012 metric) SMD standard LED | Default configuration. |
| 1 | White 0805(2012 metric) SMD standard LED | Default configuration. |
| 1 | Through hole momentary switch | Dimensions 6mm x 6mm x 4.3mm |
| 1 | Right angle 0.1" header (1x4pin) | |
| 2 | Straight 0.1" header (1x6pin) | |

> :information_source: You can also use the [Mitosis receiver](https://github.com/reversebias/mitosis-hardware/blob/master/bom/README.md) since it's almost identical, or you can build a receiver on your own.

> :warning: To program the YJ-14015 MCUs you need an ST-Link v2 programmer, these can be found on eBay or Aliexpress for as little as 2$ shipped. See [picture below](#nordic-mcus-firmware).

##### Resistor values

If you want to customize your LEDs color or save a few bucks by ordering the LED all the same color you can refer to this section for choosing the correct resistor values. Otherwise you can refer to the [default configuration](#default-configuration).

There are two sets of resistor that you need for the receiver.

- The voltage divider resistors (`R1`, `R2` and `R3`): anything between 1.5k Ohm and 4.7k Ohm is good.
- The LEDs resistors (`R4`,`R6`,`R7` and `R8`): see the following table.

| LED color | Vf | Suggested resistor value |
|---|---|---|
| Red | 1.7V | 330 Ohm |
| Yellow | 2.1V | 330 Ohm |
| Blue | 3.2V | 220 Ohm |
| Green | 2.2V | 330 Ohm |
| White | 3.6V | 220 Ohm |

Depending on the color you choose to use you should use the resistor listed above.

#### Default configuration

Here you can find the default configuration for the receiver assembly.

| Label | Component |
|---|---|
| D1 | Red LED |
| D2 | Blue LED |
| D3 | Green LED |
| D4 | White LED |
| R4 |  330 Ohm resistor |
| R6 |  220 Ohm resistor |
| R7 |  330 Ohm resistor |
| R8 |  220 Ohm resistor |
| R1 | 1.5k Ohm resistor |
| R2 | 1.5k Ohm resistor |
| R3 | 1.5k Ohm resistor |

## Receiver Assembly

The receiver assembly is pretty straightforward, you can install the components in any order you like with the exception of the YJ-14015: it should be installed **after** the right angled header (PROGR_HEADER1). Suggested assembly order:

1. Solder D1, D2, D3 and D4 LEDs. See [image](#leds-installation-detail) for orientation.
2. Solder R4, R6, R7 and R8 resistors.
3. Solder R1, R2 and R3 resistors.
4. Solder the AMS1117.
5. Solder the Arduino Pro Micro headers.
6. Solder the programming headers. I suggest you to cut the excess of the header **before** soldering the headers. You should stay as flush to the PCB surface as possible since the controller will be soldered above the headers. Use some masking tape to help you keep the header in place while soldering.
7. Solder the YJ-14015. I suggest you to glue it in place or use some masking tape to help you during soldering.
8. Upload the firmware and you're done.

##### Assembled PCB, front

<p align="center">
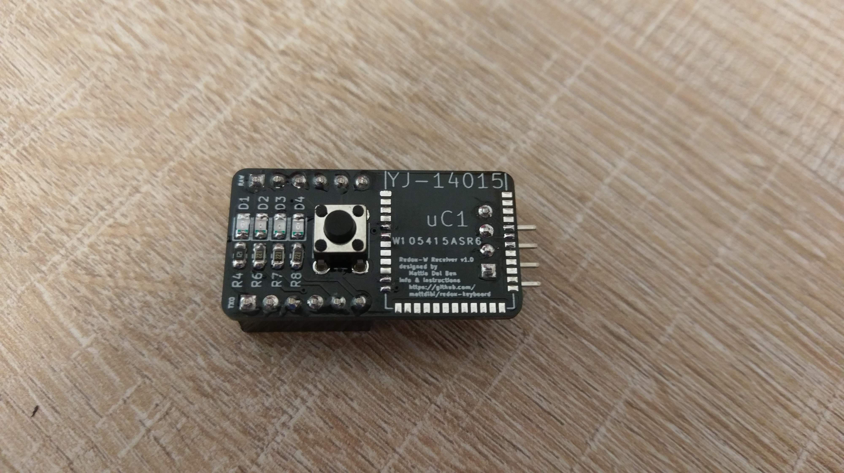
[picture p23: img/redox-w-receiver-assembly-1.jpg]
Assembled receiver PCB, front.

</p>

##### Assembled PCB, back

<p align="center">
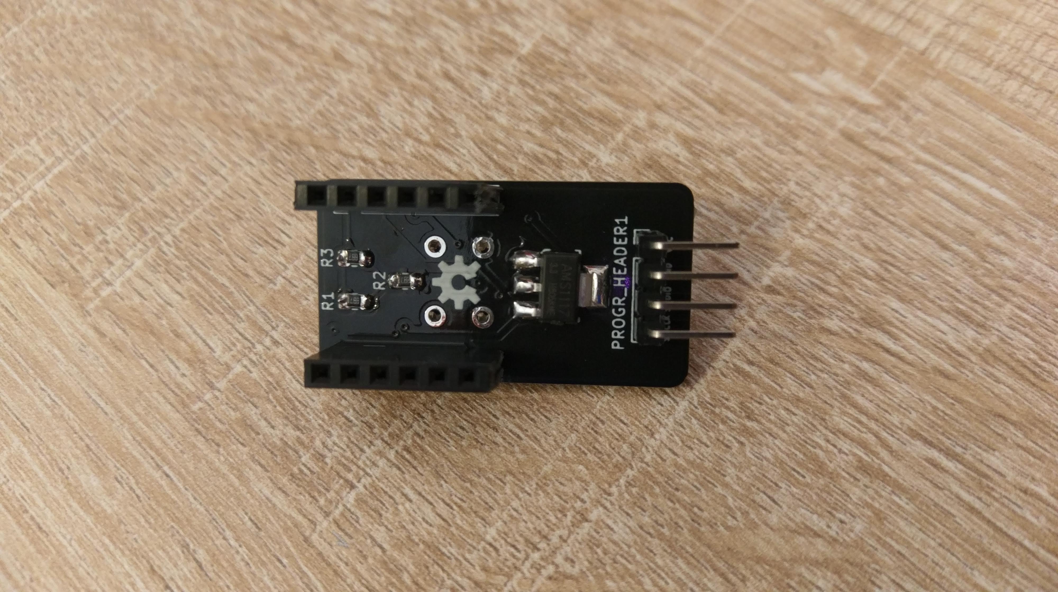
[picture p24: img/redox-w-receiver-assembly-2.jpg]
Assembled receiver PCB, back.

</p>

##### LEDs installation detail

<p align="center">
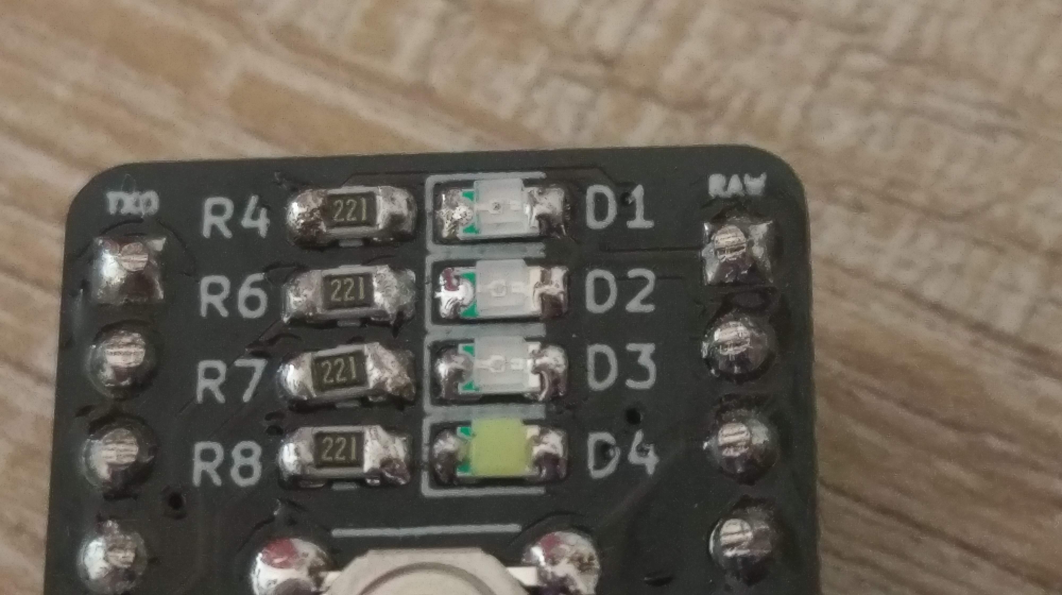
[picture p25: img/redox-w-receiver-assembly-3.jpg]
Assembled receiver PCB, LEDs installation detail.

</p>

> :information_source: Please note that here I installed 220 Ohm resistors because I used only blue and white LEDs as I only had those laying around. You should use the resistor values suggested [here](#resistor-values) or follow the [default configuration](#default-configuration).

## Transmitters Assembly

### Rev 1.0W transmitters assembly

<p align="center">
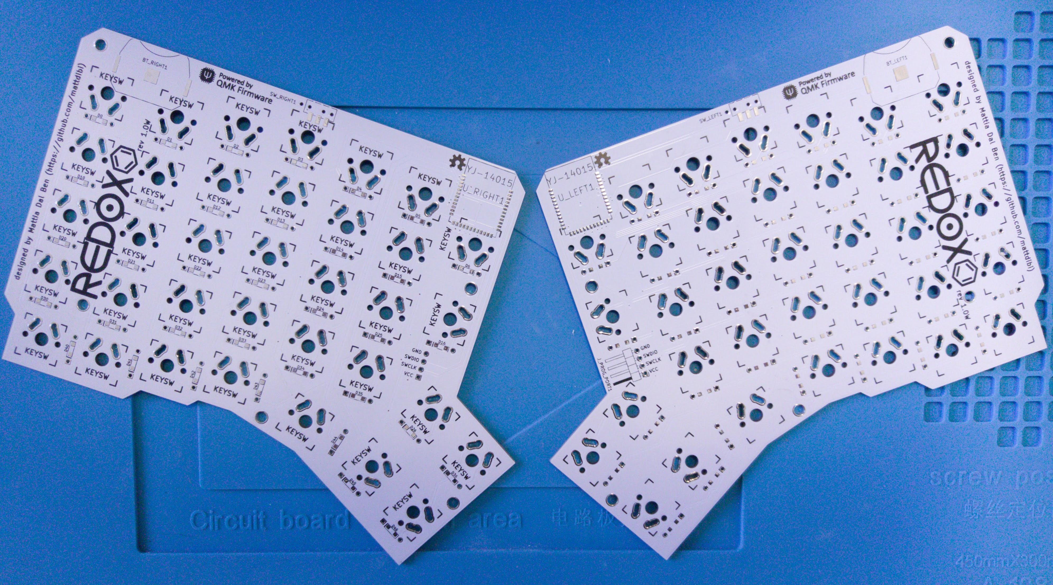
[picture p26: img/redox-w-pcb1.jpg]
Wireless redox PCBs

</p>

Assembly steps:

- Solder components to PCBs (you can proceed in no particular order):
  1. Solder the YJ-14015.
  2. Solder 1N4148 diodes.
  3. Solder slider switches.
  4. Solder the battery holders. *Note*: Some solder is needed on the ground pad to contact properly with the battery. See [picture below](#battery-holder-installation-detail).
  5. Solder the programming headers.
- Fit the PCBs inside their cases.
- Add the switches to the plate.
- Solder switches to the PCB.
- Add the CR2032 batteries.
- Program the MCUs.
- Close the case.

##### Programming headers detail

<p align="center">
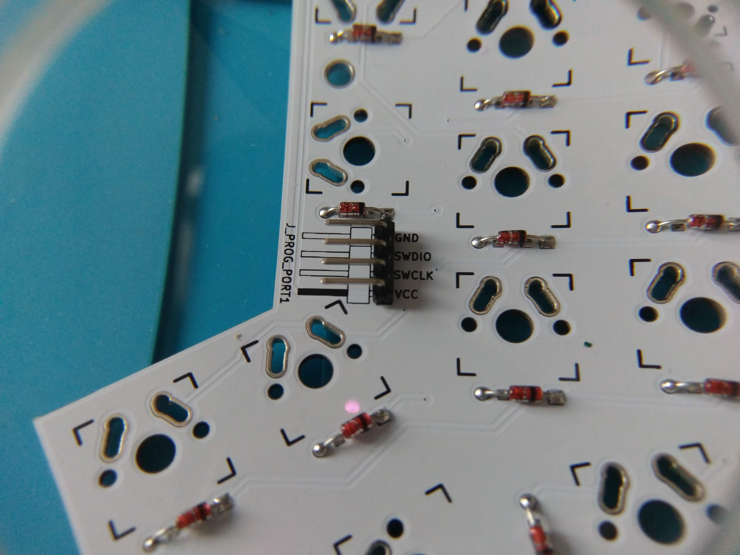
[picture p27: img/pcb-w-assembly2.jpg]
Programming headers detail

</p>

##### MCUs detail

<p align="center">
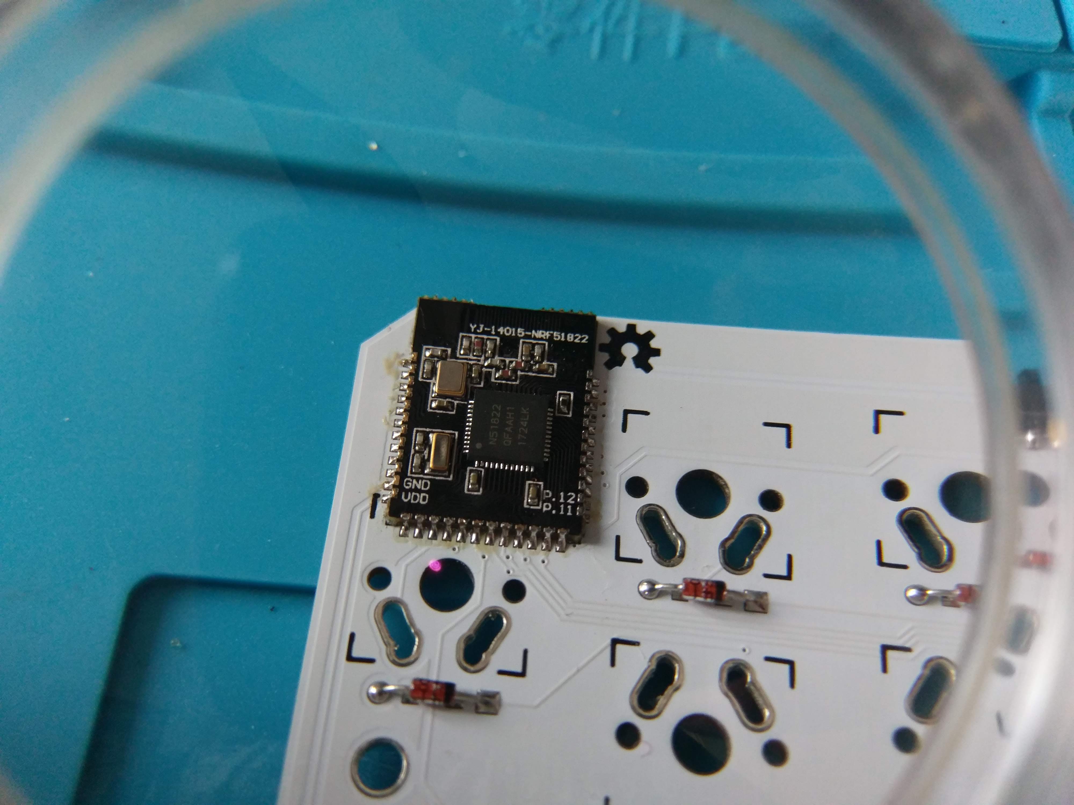
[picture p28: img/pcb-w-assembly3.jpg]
MCUs detail

</p>

##### Slider switch detail

<p align="center">
Slider switch detail
</p>

##### Diodes installation detail

<p align="center">
Diode installation detail
</p>

##### Battery holder installation detail

<p align="center">
Battery holder installation detail. Ground pad.
Battery holder installation detail. Assembled.
</p>

##### Left and right hand completed assembly

<p align="center">
Left and right hand completed assembly
</p>

##### Assembled PCB

<p align="center">
Wireless Redox assembled PCB
</p>

### Rev 2.0WHS transmitters assembly

<p align="center">
Redox 2.0WHS PCBs, unassembled.
</p>

Suggested assembly order (there's no wrong way of doing this because all parts can be soldered in any order):
1. Solder the YJ-14015.
2. Solder the right angle 0.1" header. To test the solder job try uploading the firmware as described in the dedicated section.
3. Solder the diodes taking into account the right orientation. The cathode side (denoted by the vertical line on the packaging) should face the squared hole on the PCB. See the [pictures](#diodes-and-hot-swap-socket-detail) for reference. If you have already assembled the Redox receiver, you can now test if the PCB is working properly by connecting the STLinkV2 debugger for supplying power to the transmitter and using a pair of pliers to short the Kailh socket pins.
4. Solder the Kailh hot-swap sockets.
5. Solder the battery holders.
6. Solder the slide switch.

##### MCUs detail

<p align="center">
MCUs detail 1
MCUs detail 2
</p>

##### Diodes and hot-swap socket detail

<p align="center">
Diode and hot-swap socket detail 1
Diode and hot-swap socket detail 2
</p>

##### Assembled PCB

<p align="center">
Wireless Redox assembled PCB
</p>

##### Rev 2.0WHS 3D printed case

<p align="center">
3D printed case
</p>

[Here](https://github.com/mattdibi/redox-keyboard/tree/master/redox-w/rev2.0WHS/case) you can find the newly designed case for the Redox 2.0 WHS. Features:
- Easy to print
- Sturdy feeling
- Minimal footprint
- Integrated sound dampening

I printed it with my Prusa Mini with 0.2 mm layer height. The STLs are for the left hand keyboard only, you'll need to mirror them along the X axis in your slicer for the right hand keyboard.

Hardware required for assembly:
- 10x M3 8 mm screws
- 10x M3 nuts

> :warning: The 3D printed case requires the use of SMD diodes. Through hole diodes will interfer witht the front plate.

> :warning: The closed back design (file: `BackplateL.stl`) was not tested at the time of this writing.

## Firmware

**Basics**: The Redox keyboard works similarly to the [Mitosis keyboard](https://github.com/qmk/qmk_firmware/tree/master/keyboards/mitosis): we have two transmitters responsible for scanning the two matrices, which then transmit the matrix status through the [Gazel protocol](https://developer.nordicsemi.com/nRF5_SDK/nRF51_SDK_v5.x.x/doc/5.2.0/html/a00140.html) to the receiver. The receiver is another YJ-14015 which receives the two matrix scans and send it through serial to the Arduino Pro Micro. The Pro Micro is responsible for running QMK and converting the bytes received by the YJ-14015 into actual keystrokes.

Firmware sources available here: [https://github.com/mattdibi/redox-w-firmware](https://github.com/mattdibi/redox-w-firmware).

You'll need to upload the firmware to the corresponding MCUs as per the following diagram:

<p align="center">
Redox-W firmware diagram.
</p>

Note that you'll need to upload the firmware for the YJ-14015 only once. Everything related to the keymap is handled by the Arduino Pro Micro and QMK Firmware, that's what you will need to modify to update the keymap.

### Step-by-step firmware upload guide

#### Arduino Pro Micro Firmware upload

Let's start by uploading the QMK firmware on the Arduino, this will help us in diagnosing problems early on. The Redox Wireless uses QMK for its firmware, follow the QMK installation instructions [here](https://docs.qmk.fm/#/getting_started_build_tools), then compile and burn the firmware as follows:

```sh
$ cd path/to/qmk_firmware
$ make redox_w:default:avrdude
```

You can find the code for the Redox here: [QMK - Redox Wireless keyboard](https://github.com/mattdibi/qmk_firmware/tree/redox_wireless/keyboards/redox_w).

In the [Redox Wireless Keyboard firmware repository](https://github.com/mattdibi/redox-w-firmware/tree/master/precompiled) I added some pre-built hex files with the default keymap for testing purposes.

#### Nordic MCUs Firmware upload using Docker

To flash the firmware files to the corresponding MCUs, you'll need an STLinkV2 debugger.

<p align="center">
ST-Link v2 programmer
</p>

##### Setup

###### Requirements

- Linux-based distro (macOS should work too but wasn't tested)
- [Docker](https://docs.docker.com/get-docker/)
- [Docker-compose](https://docs.docker.com/compose/install/)
- Download the [redox-w-firmware](https://github.com/mattdibi/redox-w-firmware) repository.

###### Download the repository

Open a terminal and download the Redox Wireless firmware repository wherever you want.

```
$ git clone https://github.com/mattdibi/redox-w-firmware.git
```

or

```
$ wget https://github.com/mattdibi/redox-w-firmware/archive/refs/heads/master.zip
```

###### Install the udev rules

Install the udev rules for the STLinkV2 programmer contained inside the repository.

```
$ cd path/to/repository/redox-w-firmare/
$ sudo cp 49-stlinkv2.rules /etc/udev/rules.d/
$ udevadm control --reload-rules && udevadm trigger
```

Plug in, or replug in the programmer after this.

###### Build the two container images

From inside the `redox-w-firmware` folder run:

```
$ docker-compose build
```

After the process completes you should see three new images:

```
$ docker images
REPOSITORY           TAG       IMAGE ID       CREATED          SIZE
redox-fw-toolchain   latest    810de995238e   16 minutes ago   896MB
redox-fw-openocd     latest    173d86d1409c   18 minutes ago   168MB
ubuntu               16.04     8185511cd5ad   4 weeks ago      132MB
```

##### Programming the receiver

###### Hook up the receiver

Hook up the ST-Link debugger to the receiver board you assembled without the Arduino. You need to connect only the `VCC`, `GND`, `SWDIO` and `SWCLK` pins of the receiver board like this:

| ST-Link Debugger | Receiver board |
|---|---|
| 3.3V | VCC |
| GND | GND |
| SWCLK | SWCLK |
| SWDIO | SWDIO |

<p align="center">
ST-Link debugger wiring.
</p>

Then plug in the ST-Link debugger into your PC.

###### Run the two images using docker compose

After connecting the STLinkV2 debugger, from inside the `redox-w-firmware` folder run:

```
$ docker-compose up
Creating redox-w-firmware_openocd_1 ... done
Creating redox-w-firmware_toolchain_1 ... done
Attaching to redox-w-firmware_openocd_1, redox-w-firmware_toolchain_1
openocd_1    | Open On-Chip Debugger 0.9.0 (2018-01-24-01:05)
openocd_1    | Licensed under GNU GPL v2
openocd_1    | For bug reports, read
openocd_1    | 	http://openocd.org/doc/doxygen/bugs.html
openocd_1    | WARNING: target/nrf51_stlink.cfg is deprecated, please switch to target/nrf51.cfg
openocd_1    | Info : auto-selecting first available session transport "hla_swd". To override use 'transport select <transport>'.
openocd_1    | Info : The selected transport took over low-level target control. The results might differ compared to plain JTAG/SWD
openocd_1    | adapter speed: 1000 kHz
openocd_1    | Info : Unable to match requested speed 1000 kHz, using 950 kHz
openocd_1    | Info : Unable to match requested speed 1000 kHz, using 950 kHz
openocd_1    | Info : clock speed 950 kHz
openocd_1    | Info : STLINK v2 JTAG v17 API v2 SWIM v4 VID 0x0483 PID 0x3748
openocd_1    | Info : using stlink api v2
openocd_1    | Info : Target voltage: 3.274320
openocd_1    | Info : nrf51.cpu: hardware has 4 breakpoints, 2 watchpoints
```

From another terminal window, you should see the two containers running with the following command:

```
$ docker ps
CONTAINER ID   IMAGE                       COMMAND                  CREATED         STATUS         PORTS     NAMES
84f606ad7e25   redox-fw-toolchain:latest   "tail -f /dev/null"      4 seconds ago   Up 3 seconds             redox-w-firmware_toolchain_1
8d0d6b5da95a   redox-fw-openocd:latest     "/bin/sh -c 'openocd…"   4 seconds ago   Up 3 seconds             redox-w-firmware_openocd_1
```

###### Build and upload the firmware

We can now build and upload the firmware by issuing the following from the `redox-w-firmware` root directory:

```
$ docker exec -it redox-w-firmware_toolchain_1 ./redox-w-firmware/redox-w-receiver-basic/program.sh
```

if everything goes well we should see the following output:

```
============================= PROGRAMMING =============================
Trying 127.0.0.1...
Connected to localhost.
Escape character is '^]'.
Open On-Chip Debugger
> reset halt
target state: halted
target halted due to debug-request, current mode: Thread 
xPSR: 0xc1000000 pc: 0x00000ba8 msp: 0x20004000
> flash write_image erase /usr/src/nRF5_SDK_11/redox-w-firmware/redox-w-receiver-basic/custom/armgcc/_build/nrf51822_xxac-receiver.hex
auto erase enabled
Unknown device (HWID 0x000000d1)
using fast async flash loader. This is currently supported
only with ST-Link and CMSIS-DAP. If you have issues, add
"set WORKAREASIZE 0" before sourcing nrf51.cfg to disable it
target state: halted
target halted due to breakpoint, current mode: Thread 
xPSR: 0x61000000 pc: 0x2000001e msp: 0x20004000
wrote 16384 bytes from file /usr/src/nRF5_SDK_11/redox-w-firmware/redox-w-keyboard-basic/custom/armgcc/_build/nrf51822_xxac-receiver.hex in 0.782274s (20.453 KiB/s)
> reset
> Connection closed by foreign host.

============================== FINISHED ===============================
```

while in the docker compose terminal we should see the following:

```
openocd_1    | Info : accepting 'telnet' connection on tcp/4444
openocd_1    | target state: halted
openocd_1    | target halted due to debug-request, current mode: Thread 
openocd_1    | xPSR: 0xc1000000 pc: 0x00000ba8 msp: 0x20004000
openocd_1    | auto erase enabled
openocd_1    | Warn : Unknown device (HWID 0x000000d1)
openocd_1    | Warn : using fast async flash loader. This is currently supported
openocd_1    | Warn : only with ST-Link and CMSIS-DAP. If you have issues, add
openocd_1    | Warn : "set WORKAREASIZE 0" before sourcing nrf51.cfg to disable it
openocd_1    | target state: halted
openocd_1    | target halted due to breakpoint, current mode: Thread 
openocd_1    | xPSR: 0x61000000 pc: 0x2000001e msp: 0x20004000
openocd_1    | wrote 16384 bytes from file /usr/src/nRF5_SDK_11/redox-w-firmware/redox-w-keyboard-basic/custom/armgcc/_build/nrf51822_xxac-receiver.hex in 0.782274s (20.453 KiB/s)
openocd_1    | Info : dropped 'telnet' connection
```

###### Shutdown the container and disconnect the programmer

We can now shutdown the containers by issuing a `Ctrl-C` inside the docker-compose terminal. After the command completes we can disconnect the STLinkV2 programmer and proceed to program the rest of the MCUs.

```
^CGracefully stopping... (press Ctrl+C again to force)
Stopping redox-w-firmware_toolchain_1 ... done
Stopping redox-w-firmware_openocd_1   ... done
```

##### Programming the two halves

###### Hook up the transmitter

Hook up the ST-Link programmer with the transmitters using the programming pins, and plug the debugger in you PC.

<p align="center">
Transmitters programming pins.
</p>

Start a OpenOCD session as seen [above](#run-the-two-images-using-docker-compose) using docker-compose and start flashing the firmware.

###### Left hand firmware flashing

From another terminal window issue the following command:

```
$ docker exec -it redox-w-firmware_toolchain_1 ./redox-w-firmware/redox-w-keyboard-basic/program_left.sh
```

You should see a similar output as above. You can now shutdown the two containers, disconnect the programmer and proceed with the next MCU.

###### Right hand firmware flashing

After having hooked up the right hand to the ST-Link debugger and started a new OpenOCD session we can upload the right hand firmware.

```
$ docker exec -it redox-w-firmware_toolchain_1 ./redox-w-firmware/redox-w-keyboard-basic/program_right.sh
```

Congratulations! You flashed the Redox-W firmware.

## Battery usage

I got the current consumption for the transmitters using a shunt resistor (10 Ohm) and an oscilloscope during transmission.

<p align="center">
Current draw for Redox-W transmitters
</p>

Data:
- Current peak of 5mA (I<sub>run</sub>) and 50us duration (t<sub>run</sub>)
- Idle consumption of 2.7uA (I<sub>idle</sub>) between peaks, that is 950us duration (t<sub>idle</sub>).

We can then calculate the average current consumption during typing (I<sub>avg</sub>) using the following:

<a href="https://www.codecogs.com/eqnedit.php?latex=I_{avg}&space;=&space;\frac{I_{run}t_{run}&plus;&space;I_{idle}t_{idle}}{t_{run}&plus;t_{idle}}&space;=&space;\frac{5{mA}*50{\mu&space;A}&plus;2.7{\mu&space;A}*950{\mu&space;s}}{1ms}&space;\simeq&space;250&space;\mu&space;A" target="_blank">I_{avg} = \frac{I_{run}t_{run}+ I_{idle}t_{idle}}{t_{run}+t_{idle}} = \frac{5{mA}*50{\mu s}+2.7{\mu A}*950{\mu s}}{1ms} \simeq 250 \mu A</a>

Knowing that the CR2032 battery is rated for 220mAh we get:

<a href="https://www.codecogs.com/eqnedit.php?latex=t_{batt}&space;=&space;\frac{C_{batt}}{I_{avg}}&space;=&space;\frac{220{mAh}}{250{\mu&space;A}}&space;\simeq&space;880h" target="_blank">t_{batt} = \frac{C_{batt}}{I_{avg}} = \frac{220{mAh}}{250{\mu A}} \simeq 880h</a>

**TLDR**: We can expect **at least 880 hours** of continuous typing on the keyboard before needing to change the batteries. Keep in mind that when you're not typing (500ms without key presses is the time interval needed for the keyboard) the transmitters go into deep sleep mode and draw only 2.7uA. So for an everyday use (4 hours a day of continuous typing) you can expect a battery life of at least a year. Obviously your mileage may vary.

> :information_source: After using my keyboard for a few years I can confirm that battery usage matches the above computations. Please note that a metallic case can greatly impact user experience and battery usage.

## Case compatibility

Revision 1.0W and 2.0WHS share a lot of similarities with the exception of a single mounting hole.

<p align="center">
Redox-W revisions compatibility.
</p>

As you can see from the above image, the mounting hole was moved a little lower in the rev 2.0WHS. This shouldn't compromise usability and fitment but take this into account if you want to fit a 2.0WHS PCB into a 1.0W case or vice-versa.

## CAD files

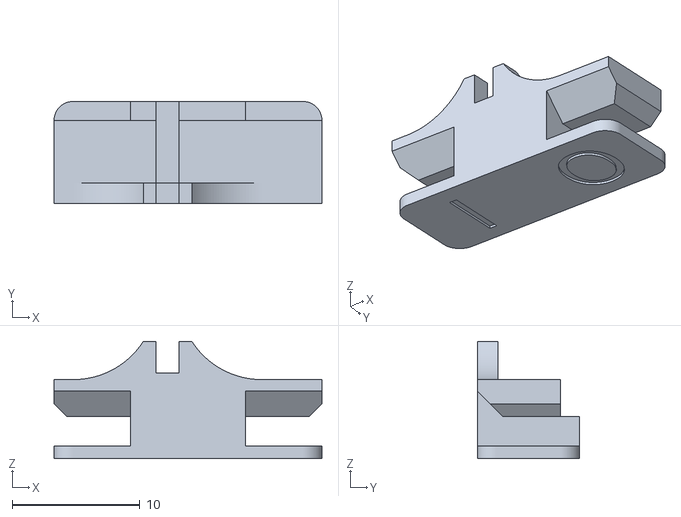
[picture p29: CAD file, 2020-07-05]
redox-w/rev1.0W/case/RedoxWirelessSwitch.stl
21.0 x 8.00 x 9.20

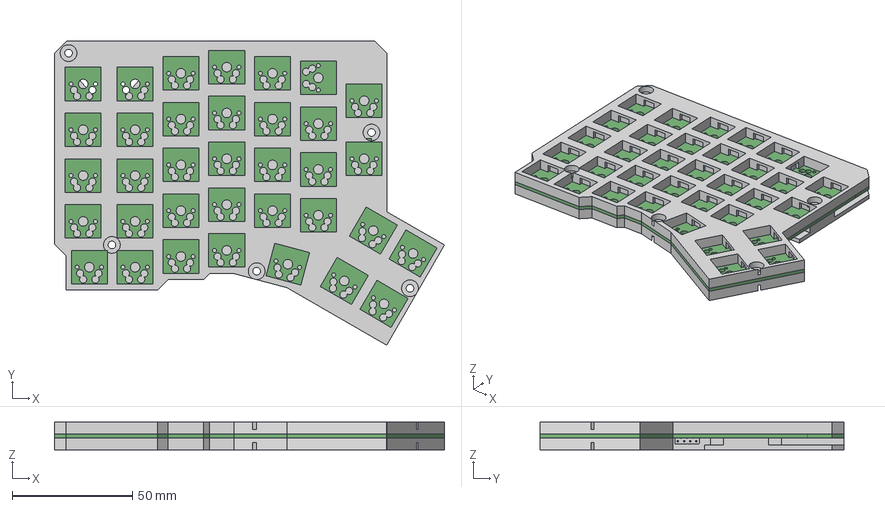
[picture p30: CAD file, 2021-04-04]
redox-w/rev2.0WHS/case/RedoxRev2.0WHSCasev15.step
162.2 x 126.5 x 11.6 mm
Backplate
Frontplate

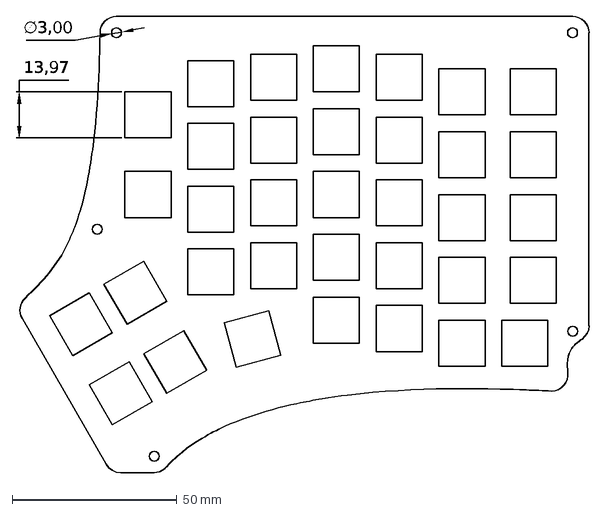
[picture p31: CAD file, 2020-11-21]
redox/case/RedoxRev2Top_2d.dxf
13,97
∅3,00

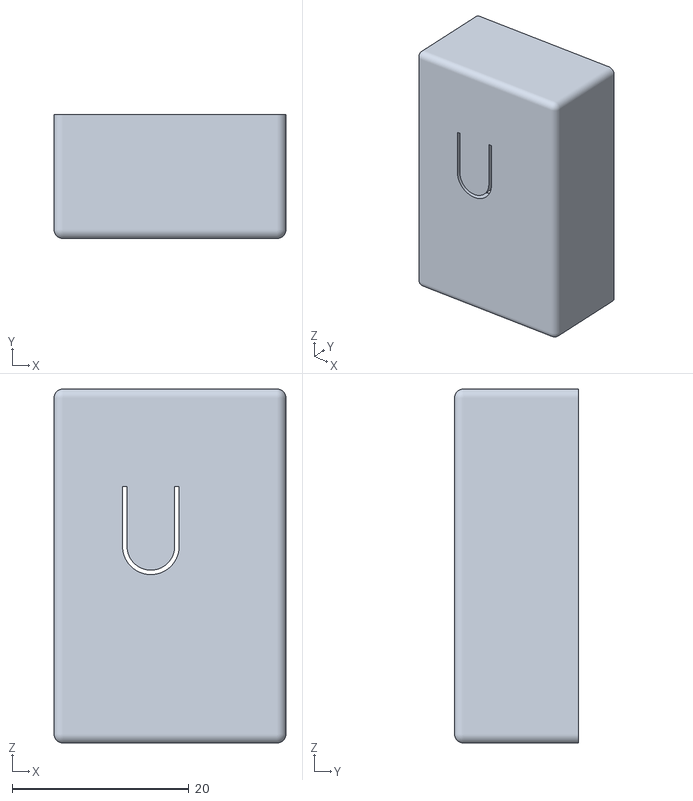
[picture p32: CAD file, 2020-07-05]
redox-w/rev1.0W/case/RedoxWirelessRev1ReceiverBottom.stl
26.2 x 14.0 x 40.0

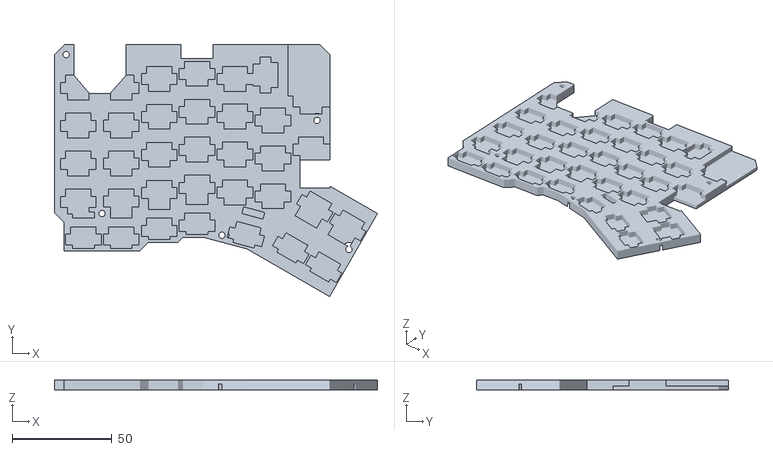
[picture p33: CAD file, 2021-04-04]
redox-w/rev2.0WHS/case/BackplateL.stl
162.2 x 126.5 x 5.00

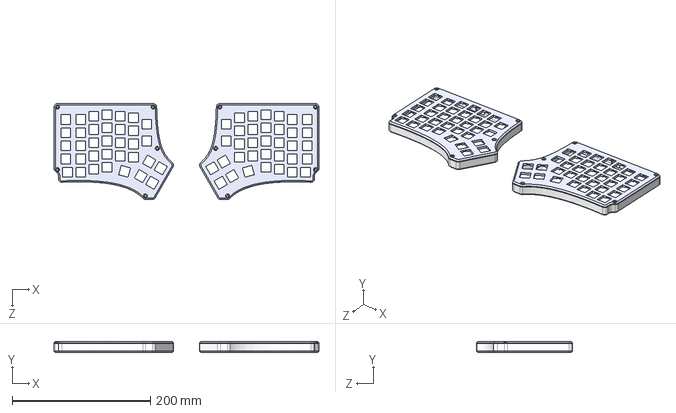
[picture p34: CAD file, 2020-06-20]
redox/case/RedoxRev2.step
382.8 x 16.0 x 138.4 mm

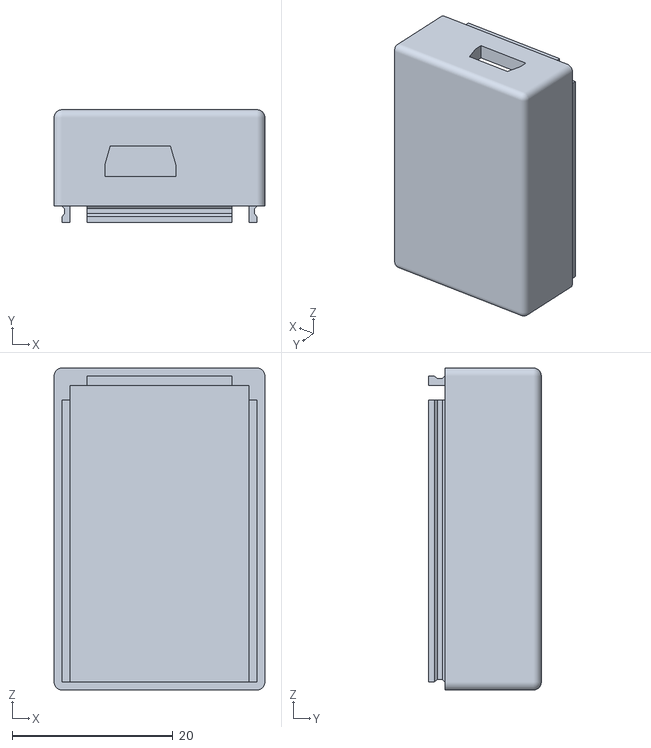
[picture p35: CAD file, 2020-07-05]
redox-w/rev1.0W/case/RedoxWirelessRev1ReceiverTop.stl
26.2 x 14.0 x 40.0

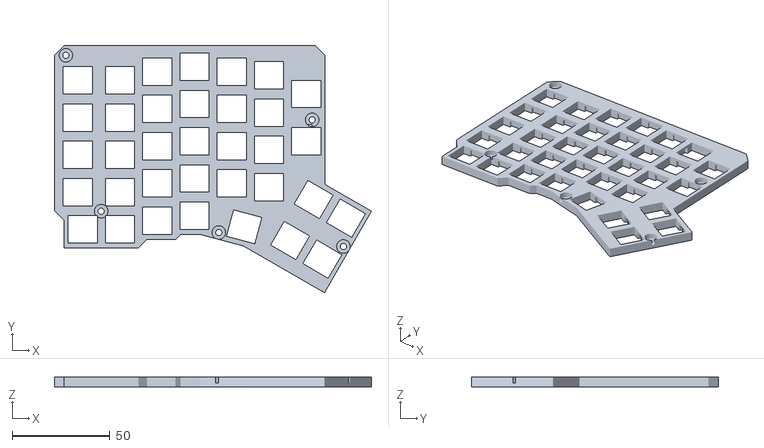
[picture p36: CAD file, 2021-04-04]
redox-w/rev2.0WHS/case/FrontplateL.stl
162.2 x 126.5 x 5.00

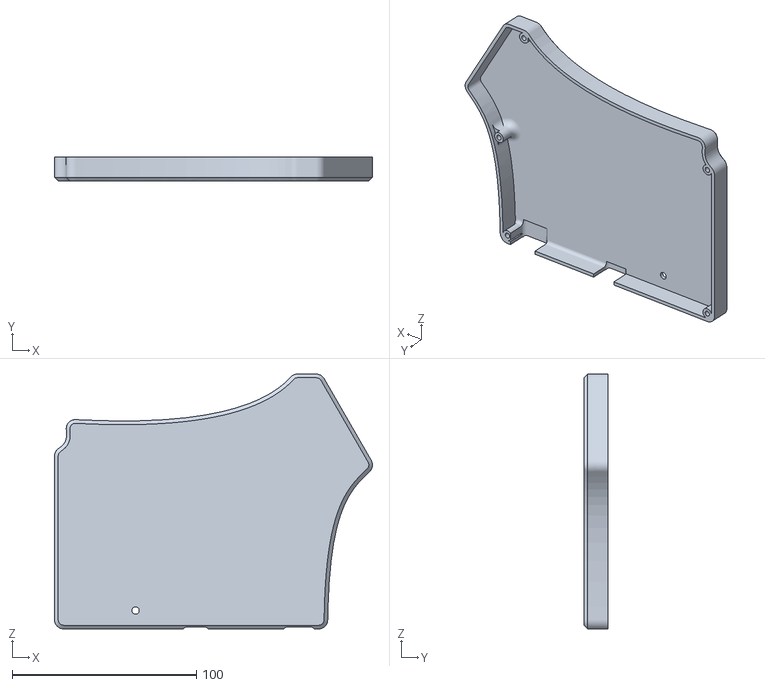
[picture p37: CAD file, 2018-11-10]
redox/case/RedoxRev1BottomLeft.STL
172.6 x 13.0 x 138.4

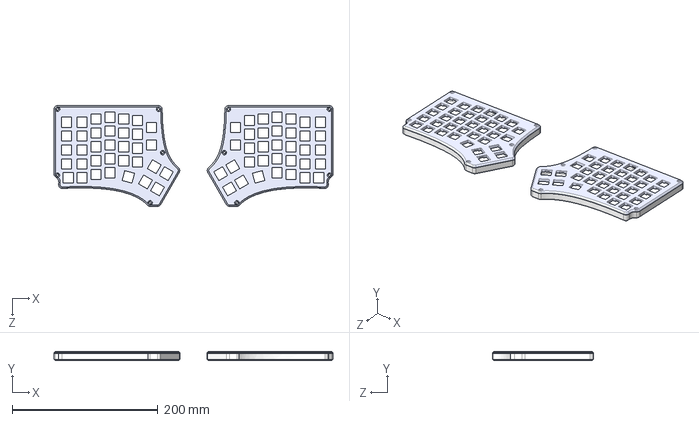
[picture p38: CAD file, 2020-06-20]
redox-w/rev1.0W/case/RedoxWirelessRev1.0Test.step
382.8 x 13.0 x 138.4 mm

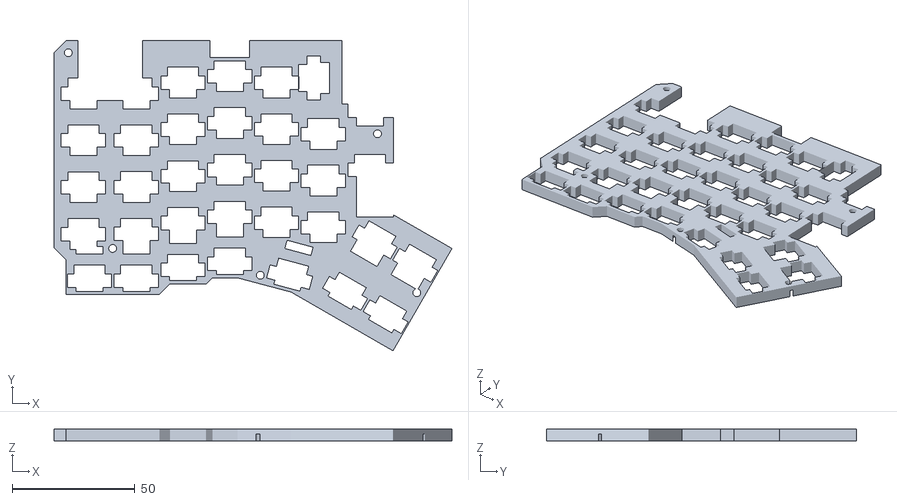
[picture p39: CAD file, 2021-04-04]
redox-w/rev2.0WHS/case/OpenBackplateL.stl
162.2 x 126.5 x 5.00

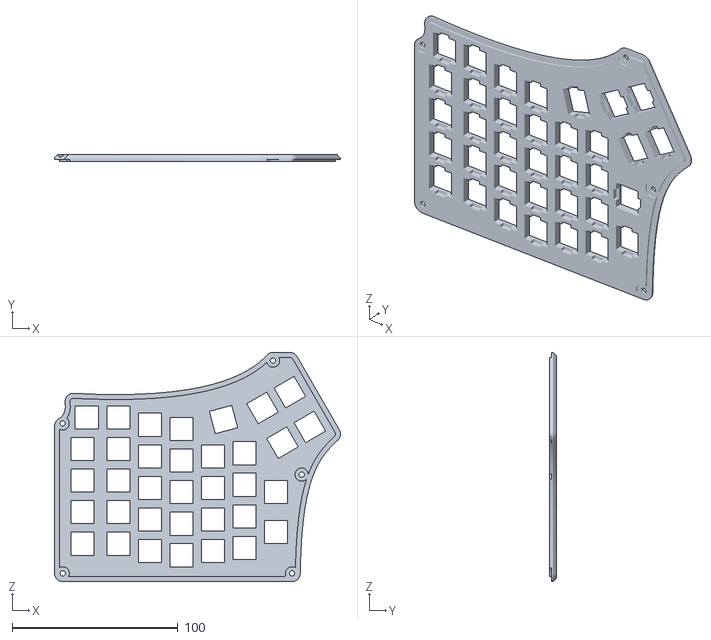
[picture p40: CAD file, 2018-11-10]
redox-w/rev1.0W/case/RedoxWirelessRev1TopLeft.STL
172.6 x 4.00 x 138.4

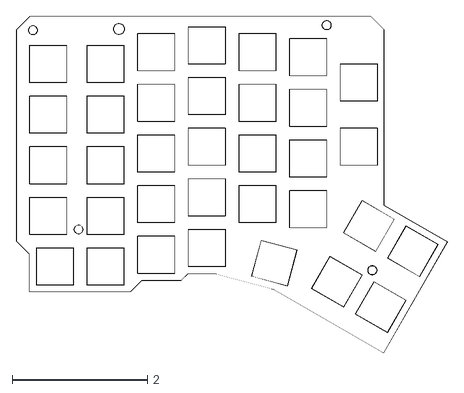
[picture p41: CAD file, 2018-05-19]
redox/case/redox_rev1-brd.dxf
6.39 x 4.98

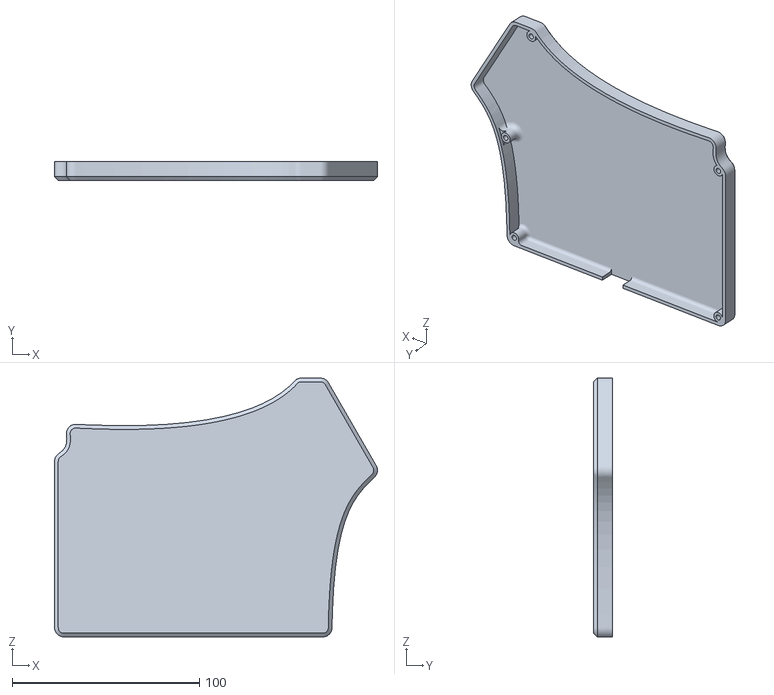
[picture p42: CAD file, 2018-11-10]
redox-w/rev1.0W/case/RedoxWirelessRev1BottomLeft.STL
172.6 x 10.0 x 138.4

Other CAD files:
redox/case/RedoxRev1BottomRight.STL
redox-w/rev1.0W/case/RedoxWirelessRev1TopRight.STL
redox-w/rev1.0W/case/RedoxWirelessRev1BottomRight.STL
redox-w/rev2.0WHS/case/RedoxRev2.0WHSCasev15.f3d

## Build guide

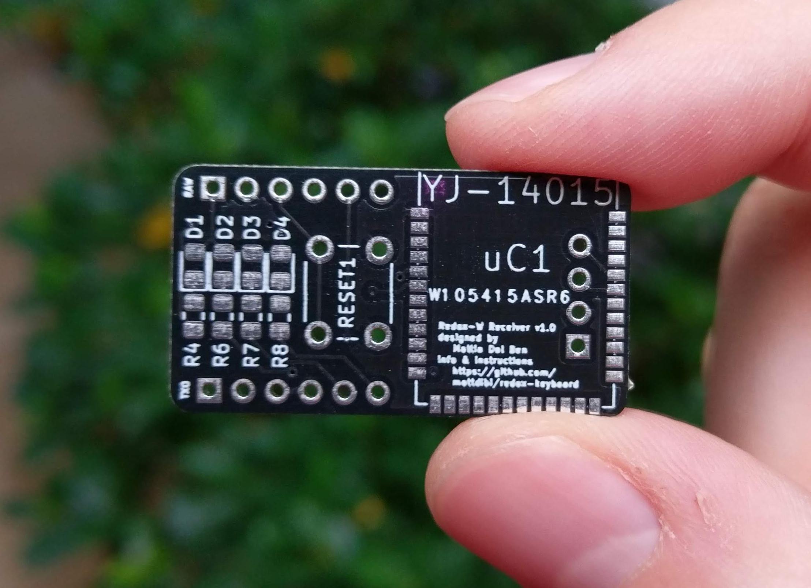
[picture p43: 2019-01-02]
img/receiver-assembly-1.jpg

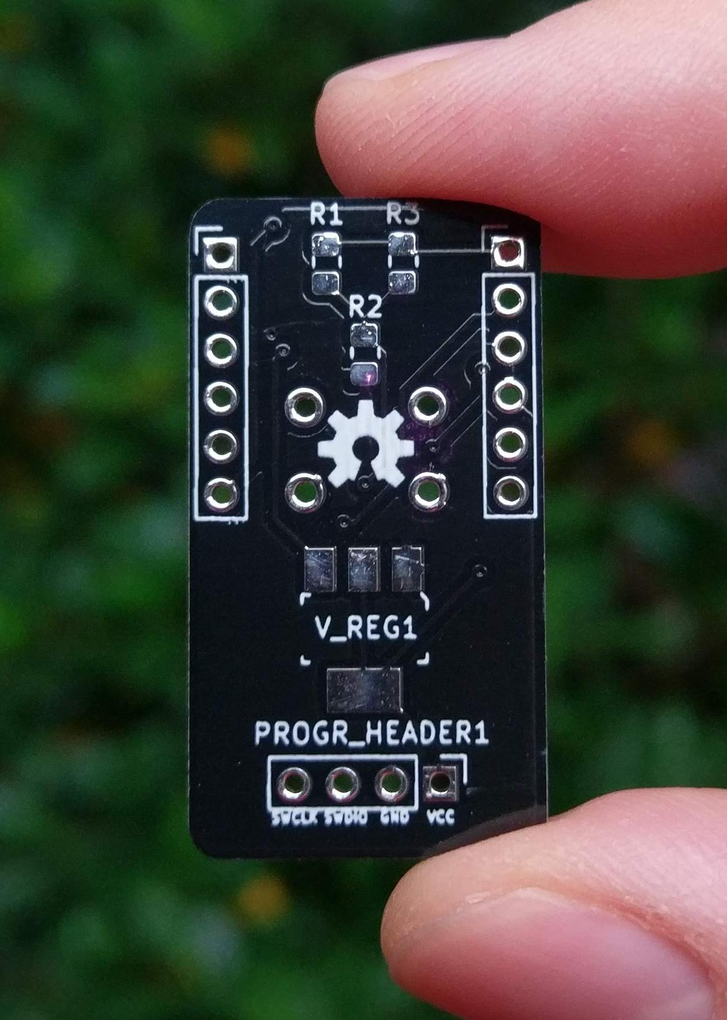
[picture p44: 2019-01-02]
img/receiver-assembly-2.jpg

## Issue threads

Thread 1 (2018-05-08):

Could this design be modified to allow swapable switches?

dmgm, 2018-05-08:
I have another keyboard (an Input Club K-Type) which allows you to replace switches. As a result I have a couple of sets of plate mounted rather than pcb mount switches. I'd like to try making my own keyboard, but this feature is missing from all current kit designs. I note the Ergodox EZ has this feature.

https://ergodox-ez.com/pages/change-it-yourself

mattdibi, 2018-05-08:
Hi,
it is possible. The current switch footprints must be replaced with a footprint that supports Kailh PCB sockets and is dual-sided. Save for mechanical interferences it might work.
I could consider it for a future revision.

tstumm, 2018-08-20:
Is there any update on this? Especially if it is possible to use the Kailh sockets with the cases from Falbatech!

mattdibi, 2018-08-20:
No update. The current PCB revision doesn't support Kalih sockets.

Closed 2018-05-08.

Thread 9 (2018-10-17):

Redox Wireless info

matthewsimo, 2018-10-17:
Hi, planning on a build soon. Entertaining the idea of the wireless but had a few questions. Where'd you source the wireless pcb? How's the battery life so far? Thanks!

Closed 2018-10-17.

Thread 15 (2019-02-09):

Add Mill-Max and Peel-A-Way hotswap details to rev 1 README.md

unjordy, 2019-02-09:
I've successfully assembled a fully hot-swappable Redox with Falba's PCBs and cases, Mill-Max 7305 sockets for the switches, and Peel-A-Way sockets for each microcontroller. The process is fairly simple, but it involves a couple of changes to how one would normally assemble the keyboard. I've taken several photos detailing how the sockets should fit. If you're interested adding the steps to the Redox rev 1 README, would you prefer a pull request, or a separate document you could edit into the existing README?

mattdibi, 2019-02-09:
That's awesome! I would be really happy to add your instructions to the repo.

I think a pull request would be great, this way you will be credited for your work. :D

You can add your instructions in the rev1 README adding a new section under the name of "Hot swappable mod". At the start of the section add the bill of materials for the mod with a link to a store. Put all the images in the `img/` folder with a recognizable prefix (like `hs-mod-blablabla.png`).

I think that's all. :)

unjordy, 2019-02-18:
All set! Check out PR #17 and let me know how it looks. And thank you by the way for the excellent keyboard design! This was my first build, and it's been excellent so far. Next up, I want to figure out how to adhere the RGB underglow strips to the PCB in such a way that they won't interfere with the hot swap sockets.

mattdibi, 2019-02-18:
Merged.

Thank you for your contribution. It looks great! :)

unjordy, 2019-02-22:
Glad to help! Writing this commit was an excellent excuse to use my Redox and tune in its layout. I'm always a bit surprised how quick I can already type on it.

ArunJ98, 2021-03-15:
@unjordy Hey! I was just wondering if you were able to figure out a way to make the RGB underglow work with the hot swappable setup? Thanks!

unjordy, 2021-03-15:
@ArunJ98 Hey! I haven’t had the chance to try yet — my Redox became my daily driver, so there’s been no opportunity to open it up since I assembled it. Zero downtime is definitely good news for the longevity of Falba’s parts and the hot swap mod though!

Closed 2019-02-22.

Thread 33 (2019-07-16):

How to check TRSSS continuity ?

toindev, 2019-07-16:
Hello,

First of all, thanks for this project, even if my keyboard isn't fully functional yet, it is still looking good (Falba bamboo) :)

Now, my issue is very similar to #25, but I can't seem to find where the problem is from:
- I've flashed the QMK redox default (use serial, master left) on both sides, using QMK Toolbox
- Both sides work when plugged (although with left hand mapping)
- The leds on both sides light up in purple when everything is plugged, but the slave half keys don't work.
- I've tried several TRRS cables, and checked the cables themselves (they're OK)
- I've not soldered the resistors, as instructed in your build guide

I'm OK with code, but only so-so with electronics. Could you maybe make some kind of checklist on what to check to find what's wrong ? I'd be happy to contribute to the troubleshooting guide :D

mattdibi, 2019-07-16:
Hi,

thank you :D

If you have a multimeter around you should check the continuity between the two halves while the TRRS cable is plugged in. There are 4 contacts inside the TRRS connector, check that the four pads on the left side connects to the 4 pads to the right side.

If everything is in order you can check if there's continuity between the two pro micros D0 pins. Then if they receive power.

toindev, 2019-07-23:
Hi,

Here is the followup:

- TRRS continuity seems OK (I used the ground pin of the resistors next to the jack to check for ground continuity)
- Power is OK everywhere (when fully connected, controller and led strips light up)
- **D0 continuity does not seem OK**

Just to make sure, I checked for the top left pin of the controller on the right hand backside, et top right pin on the left hand backside.

So, some more questions:

- Is there a way to check for continuity from D0 to the board, to identify which side has a problem?
- I have just noticed that on your build picture of the right backside, not all ground pins are soldered. Could that be a problem?
- What should I check next? 😄

mattdibi, 2019-07-23:
Hi,
ok if D0 is not connected the two halves cannot talk to each other. This is the issue you're experiencing.

> Is there a way to check for continuity from D0 to the board, to identify which side has a problem?

The D0 is connected directly to the TRRS connector. Check the pads, at least one of the TRRS connector pad should be connected to D0 (I can't remember which one of them).

> I have just noticed that on your build picture of the right backside, not all ground pins are soldered. Could that be a problem?

What pins are you talking about? Could you provide me with a link to the picture you're referring to?

> What should I check next?

See above :smile:

toindev, 2019-07-24:
> > I have just noticed that on your build picture of the right backside, not all ground pins are soldered. Could that be a problem?
>
> What pins are you talking about? Could you provide me with a link to the picture you're referring to?

[The two ground pins on the left side of the controller](https://github.com/mattdibi/redox-keyboard/blob/master/img/rgb-underglow2.jpg)

mattdibi, 2019-07-24:
Ah yes. Don't  worry about them. They're all connected togheter to the other GND pin. I used only one GND pin in that build because I desoldered that arduino from another project and couldn't remove the solder from that pins.

In your build you should connect all the pins of the arduino to the PCB.

toindev, 2019-08-02:
Hi,

I have spent some time properly testing, using the schematics, and am still puzzled at why the right hand can't send any key press:

* TRRS continuity is OK for all pins
* VCC to VCC has continuity
* SDA to SDA has continuity
* SCL to SCL has continuity
* Underglow, and underglow keys (from left hand) work
* Both half work when plugged directly

**The weirdest thing is that we are three people with a group order, and we all encounter the same problem.** I have tried mix and matching the halves and still could not manage to have any right half working over TRRS.

I'm not sure what I should try next, here are some of my ideas, if you have some suggestions, that would be really nice:
* A software problem: unlikely, since I used the version in this repository for tests, flashing the same on both sides.
* Remove the leds, solder the resistors and try ICC comm
* Change the soldering of the led data, and switch the master hand
* I've used pro micros ordered from an other vendor, they don't seem to have any problem, but maybe someone is aware of something that could explain our problem

Thanks in advance for any input you could have :)

mattdibi, 2019-08-04:
Hi,

This is really strange. Regarding the Pro Micro I'll copy-paste the warning I have in the BOM for the Redox.

>  :warning: Pay attention to the Pro Micro you use in this project. Online you can find the infamous Green Pro Micros which have the same pinout of the normal Pro Micro but use a different power circuitry. Being the Redox a split keyboard that relies on detecting which side is directly powered to find which side is the master, these clones are not suited for the task. A more detailed explaination [here](http://www.40percent.club/2017/09/green-pro-micro.html). Please note that they can come in different colors, not necessarily green.

Did you check this?

Another thing, are you using serial communication right? (If you're using the pre-compiled hex files you are.) Maybe double check that too. [Here](https://github.com/mattdibi/redox-keyboard/tree/master/redox#rgb-underglow-firmware)'s the firmware instructions.

toindev, 2019-08-08:
Hi,

Well, my pro-micros are blue, and seemed honest, but they may not be. I have tested all of them and all seem to have continuity between VCC and USB VCC, just has if their J1 was bridged. I have checked that this was the case using the TRRS and USB-A part of the cables plugged in every half I had on hand (5 of them).

I think this is **NOT** what we want.

So two questions for you:

* Am I right when I understand VCC and USB VCC should not be bridged?
* Is is possible to flash a custom firmware on each half as a workaround to force recognition of the slave half, or would we run into other problems? (Please say yes, we are not afraid of software, but it would really suck to have to unsolder 6 controllers 😢 )

mattdibi, 2019-08-08:
Hi,

could you send me a pic of those controllers?

Anyway during the weekend I'll try to come up with a solution. ;)

mattdibi, 2019-08-10:
Hi,

- You're right. VCC and USB VCC should not be shorted.
- A custom firmware will do just fine,  you'll need to change the `has_usb()` function to return always true for the plugged in half and always false for the other.

toindev, 2019-08-15:
Great news! I was starting to turn crazy with those :smile:

I'll send you a pic of the controller and will try a custom firmware next week and let you know how it goes.

Thanks a lot!

toindev, 2019-08-21:
Did not think about simply sending you the link, which has the best pictures you'll get:

https://www.amazon.fr/gp/product/B07FQBQ4Z6/ref=ppx_yo_dt_b_asin_title_o01_s00?ie=UTF8&psc=1

toindev, 2019-08-21:
Regarding the hardcoded firmware, I've had no luck yet:

Tried to flash with the following modifications:

```
bool is_keyboard_master(void)
{
  return true;
}
```

```
bool is_keyboard_master(void)
{
  return false;
}
```
 The master works, but not the slave, just the same.
The slave half works as a left hand when flashed with the master firware as well.

I will try with the other keyboard to make sure, and then maybe have a look at how to live debug (this could be interesting).

If you have other ideas, I'm open, else I'll follow up here.

mattdibi, 2019-08-22:
@toindev This is getting weird.

I took a look at the link you sent me: the Arduinos looks good, the power circuitry is correct. This means a software fix shouldn't be needed. Maybe J1 is shorted? (it shouldn't for the split SW to work)

Regarding the software you modified: could you list  the commands you used to compile and upload the firmware to the keyboard?

For live debugging take a look [here](https://beta.docs.qmk.fm/newbs/newbs_testing_debugging).

toindev, 2019-08-22:
https://github.com/toindev/qmk_firmware/tree/hardcoded_master_slave

There's only the last commit with my modifications:

- copied the default keymap as a slave keymap
- modified the dockerfile to build both keymaps
- modified split_common to return true or false depending on a macro being set in config.h

Commands for build (powershell syntax for the Docker volume):

```
docker build --rm -f "Dockerfile" -t redox-builder .
mkdir output
cd output
docker run -i --rm -v ${PWD}:/artifacts redox-builder
```

yoution, 2019-12-14:
Hi, I have the same problem If I use two usb cables, they work well, but If I use one trss cable and one usb cable, the slave half not work, I want to test the D0, but how to test D0?can you tell me how to test D0?

mattdibi, 2019-12-14:
Hi @yoution,

First thing first, I have to tell you that the soldering job on the Arduino Pro Micro is really poor. Don't worry, it's easy to fix. I suggest you to take a look at [this](https://www.youtube.com/watch?v=fYz5nIHH0iY) tutorial and just do a new pass on all those pins (you don't need flux, just look at his final result for reference). That can be enough to fix the problem.

Another check I suggest you to do is the continuity on the cable. Put the multimeter in continuity mode and check that every ring of the 1.5mm jack is connected with the other 1.5mm jack.

Then check the continuity on Pro Micros. While the TRRS cable is connected check that PD0 on the master side is connected to PD0 of the slave side. Arduino Pro Micro pinout:
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

yoution, 2019-12-14:
@mattdibi  thank you.It's ok now, I just resoldered some pins  of Pro Micros

toindev, 2020-04-13:
Hello! It's been a while. Just for reference, my initial issue really was all about defective controllers. I finally got the time to dive into it, and mercilessly cut the controller out with a Dremel (Just the slave one). BTW, you should insist a lot more on the advantages of socketed controllers!

Thanks again for your design and your help!

-- Written with my Redox :D

Closed 2019-12-14.

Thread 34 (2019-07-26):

proton-c compatibility?

danielo515, 2019-07-26:
Hello and congratulations for this great project.
I was looking for a wireless alternative to my ergodox, and this looks quite awesome.
However, now that I'm going to make an "upgrade" I would love to get rid of space limitations I currently have. Proton-c is an arduino pro micro alternative that has way more space for the firmware, and it should be a drop-in replacement.
I think it still has some problems with split keyboards, but since here we only have one keyboard maybe it is not that "split" at the end.
Do you think it will be compatible?

mattdibi, 2019-07-26:
Hi,
I assume you're talking about the Redox Wireless.
Footprint-wise for sure. The code doesn't use the split functionalities so I think it should work.
I don't know of anybody who actually tried this though. You'll be the lucky beta tester if you proceed with this experiment :D

danielo515, 2019-07-27:
Yes, I was talking about the redox wireless 😄
So physically it should fit. I don't see a reason why it should not work on the software level. I mean, I'm not an expert but proton-c uses the same firmware with probably just some tweaks on the settings.

By the way, do you have any picture where I can see the receiver with the arduino attached? All the pictures I found are only showing the wireless part

mattdibi, 2019-07-27:
Here's some pics. Usually I add some female header pins to the receiver to be able to remove the Arduino in case I need it.
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

In case you're wondering without those female header pins the arduino + receiver assembly should look somethink like this.

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

Maybe a little thicker because there's the voltage regulator on the back of the receiver board.

Hope this helps.

danielo515, 2019-07-27:
Wow, that is quite a big receiver! But I like the idea of the female pins.
Thank you very much for the pics, they helped me to get an idea about how it looks like.

Closed 2019-09-07.

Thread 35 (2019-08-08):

No key presses working

termhn, 2019-08-08:
Hi!
I've (in theory) just finished soldering and flashing firmware for my Redox, however no keys are working on either side. I believe my flashing went well since when I plug in either side now, it is displayed as a Generic Keyboard device in windows Device Manager rather than as an Arduino Pro Micro as it had before. However, like I said, none of the keys work on either side, neither when connected individually or together with the TRRS.

I don't see any obvious soldering issues. Any ideas? Here's a couple pictures of the backs of the boards, dunno how much good that will do :p https://imgur.com/a/Duoo4bg

termhn, 2019-08-08:
Okay, I'm very perplexed. I further was debugging this issue and went thru with my multimeter and was getting the proper voltage on both sides of the switch both when open and close when they were plugged in.

Long story short, after a reboot of my computer... it magically works :)

mattdibi, 2019-08-08:
Maybe it was a driver issue? Anyway glad you fixed it!

Closed 2019-08-08.

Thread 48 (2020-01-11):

Single row on left hand not working, how to troubleshoot?

harshitgoel96, 2020-01-11:
Hello.

The entire keyboard is working fine except one single row. I do not see any issue on MCU soldering as all pins are visible joined. Please let me know how can I trouble shoot this issue.

mattdibi, 2020-01-12:
Hello.

Double check soldering. Visual inspection is not sufficient to determine good soldering. Use a multimeter in continuity mode.

Double check PCB trace for an interrupted line (highly unlikely).

harshitgoel96, 2020-01-12:
@mattdibi i was able to get the work with reflowing the solder. it has resolved the issue for me. however i have some issue with  the dongle range. does the board to be in line of site? i some times see the issue with slow/dropped key registers. moving the keyboard a bit solves  the issue.

mattdibi, 2020-01-12:
@harshitgoel96 Happy to hear that!

Range depends heavily on environmental factors: an environment with crowded 2.4GHz band (a lot of wireless devices) can be a contributor. Aluminium case can negatively impact the range. Ensure you're using the latest version of the Redox firmware for the [latest range/stability fixes](https://github.com/mattdibi/redox-w-firmware/pull/7).

Closed 2020-01-12.

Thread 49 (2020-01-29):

right RGB lights not working

solidgriever, 2020-01-29:
Hi, I build a rev1 redox with RGB and right side RGB does not work.
It is already soldered and it will be a pain to desolder the micros and the switches. Hope someone has solved this issue.
(all switches work OK see 3) and all RGB leds turn on see 2) )
what I tried:
1) flashed redox_rev1_default_RGB.hex(precompiled mattdibi/redox-keyboard):
       -left side: OK both keystroke detection and RGB
       -right side: no keystroke detection no RGB
2) flashed redox_rev1_default.hex (precompiled  mattdibi/redox-keyboard)
       -left side: OK detecting heystrokes and OK RGB
       -right side: no keystroke detection but OK RGB
3) compiled and flashed from source default keymap(make redox/rev1:default)
        -left side: OK keystroke detection & OK RGB
        -right side: OK keystork detection & no RGB   (sometimes i get the 1st led on set to green)

if i try to set comunication to I2C i get very slow reaction on both RGB and keystorkes

mattdibi, 2020-01-30:
Hi,

I would double check the wiring of the RGB strip, is it correctly wired as seen [here](https://github.com/mattdibi/redox-keyboard/tree/master/redox#rgb-underglow)?

solidgriever, 2020-01-30:
thx for the replay. I think the wiering is ok because if i flash your precompiled default.hex the rgb strips behave as I expect: I can toggle both and
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
change mode from the left side.

mattdibi, 2020-02-01:
Hi,

I've noticed you soldered the 4.7k resistors near the PJ-320A connectors, which is wrong. The resistors are needed for the I2C connection. The RGB underglow works by occupying one wire of the TRRS connection for transmitting the data between the two halves, thus preventing us to use the I2C connection (which uses two wires).

So:
- Remove the two resistors.
- Be sure to use the **serial** communication instead of I2C (see [here](https://github.com/mattdibi/redox-keyboard/tree/master/redox#rgb-underglow-firmware))
- Be sure to define the correct **master hand** (see [here](https://github.com/mattdibi/redox-keyboard/tree/master/redox#rgb-underglow-firmware)) .

Hope this helps.

solidgriever, 2020-02-01:
Yes i soldered the resistors as a test just before i took the picture and it did make no difference.
Anyway, i managed to make it run as intended.
I think the problem is the right PJ-320A jack.
What i did was insert the cable only ~80% in the jack.

Closed 2020-02-01.

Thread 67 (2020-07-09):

test the Arduino

DickThomas, 2020-07-09:
Hello,

I'm looking to build this keyboard for my birthday later on this month.
I keep reading the section regarding the 5v Arduino and to be honest it has me worried.
I'm not quite a total n00b to soldering, but I am at de soldering as it's something I've never done before.

Is there anyway I can test them preinstallation?

sorry for asking such a noobish question I know it's possibly not the right forum for this type of Q.

mattdibi, 2020-07-12:
Hi,

I think you're referring to the Pro Micro used in the Redox wired version. **Usually a simple visual inspection is sufficient to find out if the Pro Micro doesn't use the correct power cirtcuitry** (for example the wrong pro micro misses the J1 jumper).

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

More info [here](http://www.40percent.club/2017/09/green-pro-micro.html).

If you're referring to the 3.3V/5V, [you just need to change the CPU frequency parameter](https://github.com/qmk/qmk_firmware/tree/master/keyboards/lets_split#notes-on-using-pro-micro-33v).

DickThomas, 2020-07-16:
thank you so much
mine has a open J1 not a closed j1 as pictured, I was also worried about 3.3V/5V :+1:

I've also found this supplier for this https://mechboards.co.uk/shop/components/24-pin-pro-micro-sockets/  that should solve the issue incase of a faulty board.

it's similar to the part you list but I was able to get it shipped to the UK for a reasonable price.

Closed 2020-07-16.

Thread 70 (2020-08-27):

Problem with CAD files

TheWeirdDodo, 2020-08-27:
Hi,

I'm right now in the process of building a redox keyboard and I wanted to model my own case and print it myself. It was very useful to have all the CAD files including the drawing of the PCB and the witch positions before hand to start modeling the case.
So after designing a model I was happy with I printed it and put it together to see if it works out. Now after recieving my redox PCBs from falba I was very dissapointed when seeing that the holes for the switches on the top of the Keyboard don't align with the position on the PCB. Looking at my model and tryiung to find my error i found that the Error sits actualy within the dxf file found under the redox/case section. Sadly the dimensions of this drawing doesnt match the actual PCB from falba.
I am really dissapointed by this after investing so much time into the design to find it isn't fitting. I dont know how to fix this problem, since i dont know the exact dimensions and offsets of the parts. I hope I can get some help here.

You can see what my problem is in the Image posted below. Marked in red you can see the position of the contacts where the switch will be soldered and in orange you can see the mounting position of the switches. Toward he left you can see that the position of both, the connections and the mounting holes align nicely centered, but toward the right you can see the position is shifted away from the center. I am 100% certain this error doesn't originate from bad 3D modelling but from wrong dimensions of the drawing and the actual PCB since i directly used the files from this repository to design this case.

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

I am hoping for a quick response, since this is changing my whole plan of building a nice keyboard using these PCBs.

mattdibi, 2020-08-29:
Hi,

sorry to hear you encountered these problems.

Unfortunately I haven't much to say about this. The method I recommend for designing new cases, and that worked until now for a lot of people, is to extract the position of the switches from the PCB in the .dxf format using KiCAD and starting from there with the design. Is this how you proceeded?

mattdibi, 2020-08-29:
Furthermore, did you try and install the switches (without soldering) to see if there's enough mechanical clearance for the case to work anyway? From the pic you posted the align doesn't seem to be as dramatic as you say. Might be a parallax error though.

TheWeirdDodo, 2020-09-03:
Hi,

sorry for the long wait. So i worked it out and it all fits, a little bit tight on the top right side of the board but it fits. I’m not completely sure what caused the problem. I just printed the same file again and now it works.

Thanks for the help tho!

Closed 2020-09-04.

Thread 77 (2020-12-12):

Arduino turns off when TRRS cable is connected

nicola-sorace, 2020-12-12:
Hello

I've assembled a non-rgb keyboard according to the instructions, and flashed the firmware on each half. Each individual keyboard half works perfectly on its own, but when I connect them with the TRRS cable the Arduino LEDs turn off and nothing happens when I type. This happens even if I plug in a cable into only one side and **leave the other end unconnected**.

I've tried a different cable, double-checked all connections are as they should be, but nothing seems to work. If I pull out one side of the cable ever so slightly, the LEDs on both Arduinos turn on, but only the side that's connected actually works. If I use two separate micro USB cables to connect both sides independently, everything works great.

Any ideas what has gone wrong?

mattdibi, 2020-12-12:
Hi,
this sounds like a short to ground or a faulty connection caused by the TRRS connector. Double check with a multimeter in continuity mode that the TRRS connector does what it should and there's no shorts in its pins.

nicola-sorace, 2020-12-12:
Hi, thank you very much for the fast reply!

I've checked everything I can think of with a multimeter. The TRRS connector seems to be wired up like this:

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

If that looks right then it seems like everything is wired up like in the PCB schematic (I'm no expert though). Only weird thing is that the resistance across the resistors is about 4.56kOhms instead of 4.7kOhms? Other than that everything seems in order. When I connect the cable the matching TRRS pins on both keyboard halves are fully connected.

Just tried connecting the TRRS cable before plugging in the micro USB. No keys do anything. As soon as I unplug the TRRS the half that's plugged in works fine.

nicola-sorace, 2020-12-12:
ok so, it looks like when a jack is plugged into a socket, the pins I labelled "ground" and "VCC" in the image are shorted. I tested this on a loose socket and the same thing happened.

Did I buy the wrong type of connector? It's this one here: https://www.amazon.co.uk/sourcing-Connector-Female-Socket-PJ-320A-Black/dp/B07KYCC7RN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

Surely the circuit board can't be wrong, and I don't see how I could have soldered in a way that switches pins around (and in the same way on both sides)! What's going on?

nicola-sorace, 2020-12-13:
...so it turns out I was using a T**R**S cable instead of a T**RR**S cable. The other cable I have *is* a TRRS cable, but for some reason *one* of its sides has this same effect of shorting out VCC and ground.

So it looks like my problem might have been *two* faulty cables! 🤦
I'll order a new one and see if that solves the problem

mattdibi, 2020-12-13:
My next move would have been to suggest you to check the cable, nice catch!

Closing this. Feel free to re-open this if changing the cable doesn't solve the problem.

nicola-sorace, 2020-12-15:
Confirming that was the problem, new cable works great.
Thanks for the help! This keyboard is awesome!

Closed 2020-12-13.

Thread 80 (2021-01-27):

Question about RGB and i2c

renkam, 2021-01-27:
If I understand everything correctly when LED underglow is not used, then both sides communicate over i2c. If underglow is used then serial connection is used instead i2c.

On schematic pdf (https://github.com/mattdibi/redox-keyboard/blob/master/redox/pcb/Redox-schematic.pdf) there is rgb_data output. Is this output uses i2c? Is it possible to use oled display with rgb underglow in this configuration?

mattdibi, 2021-01-30:
Hi,

A clarification. QMK [allows for two type](https://beta.docs.qmk.fm/using-qmk/hardware-features/feature_split_keyboard) of communication for split keyboards: serial and I2C. I2C needs **two** data wires (SDA, SCL) to work while serial only **one**. To drive the LEDs we need that extra wire and thus if you use the I2C communication you can't connect the LED underglow.

The `rgb_data` output is a single data output and thus cannot be configured to drive I2C-based OLED displays (because again they need 2 data lines).

Hope this helps.

renkam, 2021-01-31:
This helps.
If I understand correctly (again :smile:), I can [use RX1/PD2 for serial](https://user-images.githubusercontent.com/2170248/92296490-2d15cb00-ef70-11ea-801f-5ace313013e6.JPG) and then I have 2/PD1 and 3/PD0 free to use for OLED display. Also I have still free 5/PC6 and A3/PF4 for rotary encoder.

Please correct me if I am wrong.

mattdibi, 2021-01-31:
Technically yes. But you would need to modify the Redox PCBs as these pins are already used (PD1 and PD0 are routed to the TRRS connector).

renkam, 2021-02-02:
Understood. Thanks!

Closed 2021-02-02.

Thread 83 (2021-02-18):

weird random key combinations

MrPelucaa, 2021-02-18:
So just finished the wirign, everything is ok but when flashing my board, in seems in sends random combinations of keyes. After re checking everything now it seems it has some keys stuck. Im pretty sure the problem is in the flashing process but I dont really understand it.

Platform: windows
Board: Pro Micro Clone

 Connecting to programmer: .
    Found programmer: Id = "CATERIN"; type = S
        Software Version = 1.0; No Hardware Version given.
    Programmer supports auto addr increment.
    Programmer supports buffered memory access with buffersize=128 bytes.

    Programmer supports the following devices:
        Device code: 0x44

    avrdude.exe: AVR device initialized and ready to accept instructions

    Reading | ################################################## | 100% 0.00s

    avrdude.exe: Device signature = 0x1e9587 (probably m32u4)
    avrdude.exe: NOTE: "flash" memory has been specified, an erase cycle will be performed
                 To disable this feature, specify the -D option.
    avrdude.exe: erasing chip
    avrdude.exe: reading input file "C:\Users\diego\Downloads\redox_rev1_default_4ac56f60.hex"
    avrdude.exe: writing flash (24400 bytes):

    Writing | ################################################## | 100% 1.80s

    avrdude.exe: 24400 bytes of flash written
    avrdude.exe: verifying flash memory against C:\Users\diego\Downloads\redox_rev1_default_4ac56f60.hex:
    avrdude.exe: load data flash data from input file C:\Users\diego\Downloads\redox_rev1_default_4ac56f60.hex:
    avrdude.exe: input file C:\Users\diego\Downloads\redox_rev1_default_4ac56f60.hex contains 24400 bytes
    avrdude.exe: reading on-chip flash data:

    Reading | ################################################## | 100% 0.17s

    avrdude.exe: verifying ...
    avrdude.exe: 24400 bytes of flash verified

    avrdude.exe done.  Thank you.

mattdibi, 2021-02-19:
Hi,

from experience I can tell you that these kind of problem almost always come from some hardware issues. Double check soldering for shorts and whatnot. Double check diodes orientation.

The stuck keys are all on the same column? All on the same row? That can be a hint on where the problem can lie.

I don't see any problem in the firmware upload process.

MrPelucaa, 2021-02-19:
After checking the connections it seems the arduino has continuity (?) between the pins a2 and 3. Also im not sure it means continuity, the multimeter shows numbers over 1000 and no beep, like when testing a diode. That has to be the problem, because when I tested in the keyboard that means a full column is constantly being pressed. Not sure if the arduino is faulty or my soldering. Is there a way to remap the pins in QMK ?

MrPelucaa, 2021-02-19:
just switched to another arduino, works fine. Guess it was bad luck with that board.

Closed 2021-02-19.

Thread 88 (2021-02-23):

Falba PCB rev 13-01-2021: pad overlap question

raymaclabs, 2021-02-23:
I recently received my boards from Falbatech and noticed an issue with an overlap of a hotswap pad, a diode smd pad and the associated diode through hole.  It looks like it was scratched through the copper layer on the "left" side to try and correct the issue.  Has anyone that has built with this board had any issues?  I am doing through hole and not hot swap, so I am not overly concerned but wanted to validate.  Looking at the other post here with this board revision I can see the same scratch mark.  Attached are photos of both boards with the same scratch on the "left" as well as the flip side of the board with properly spaced pads on the "right" side of the board.

Thanks for a great design and offering the PCBs at a reasonable cost compared to a lot of other kits.

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

mattdibi, 2021-02-23:
Hi,

with the premise that, as emerged from [here](https://github.com/mattdibi/redox-keyboard/issues/86), I've just learned about the existence of this particular board. It looks like there was a misfortunate placement of the pads that was later fixed by cutting the trace after the fact.

I think that, if you're not planning to use the hot swap socket, you should be good but I cannot be 100% sure.

To be extra sure you can grab the multimeter and make a few continuity checks using the schematic available [here](https://github.com/mattdibi/redox-keyboard/blob/master/redox/pcb/Redox-schematic.pdf).

Spamm3r, 2021-02-23:
Okay, about this "scratches", I have exactly the same in same exact places but board is functioning properly. I have even checked for continuity and everything was alright. If you are planning installing LED's then you should read my post.

raymaclabs, 2021-02-23:
Thanks @mattdibi and @Spamm3r for the comments.  I haven't done the continuity check but will do that tonight and validate.  Good to hear its working fine for you Spamm3r.

Matt since I haven't done the install yet do you want me to take photos of the build process so you can add it to your documentation with this updated board?

Spamm3r, 2021-02-23:
I think that there is no need to update everything. the most important parts are that hot swap mod is supported and LEDs lanes are inverted. But decision is up to Matt.

@raymaclabs how long have you wait for your order?

raymaclabs, 2021-02-24:
@Spamm3r it didn't seem unusually long.  It was 4 days from order to shipping and then less than a week to arrive in the USA.

Spamm3r, 2021-02-24:
Oh really? I was waiting month or even more. I have ordered case, cables and pcb.

Spamm3r, 2021-02-25:
@mattdibi I may have problem with one key (pad is overlapped) (key is ]/} - I have default keymap). I have checked for continuity when I have pressed key and there is connection between pads. I have replaced diode and different positions but no success (you never know if falba changed something). So is there an way to simulate an key press by shorting some pads on pro micro? If traces are damaged I will just short wire connection to key.

mattdibi, 2021-02-25:
Great! Thank for the informations. I'll wait for the documentation from Falbatech then.

Spamm3r, 2021-02-25:
I have no clue how long you will have to wait etc. Maybe if you will call him you will get more answers then me.

raymaclabs, 2021-02-25:
@Spamm3r is this the spot with the scratched pads or a different one?  I want to ensure i jump the same spot when soldering mine up also.  Thanks!

Spamm3r, 2021-02-25:
Yea with scratched pads. The funny thing is that on my one half everything is alright but on second one is not. I can guess that he did "disconnecting" of pads by hand and in my case he damaged trace.

raymaclabs, 2021-02-25:
I see what you're talking about, the trace for that last column that is close to those pads.

Pastitas, 2021-02-26:
Did you guys buy these as B-Stock units for a lower price, or are they the standard option?

raymaclabs, 2021-02-26:
I bought these as the standard option from this link. https://falba.tech/product/ergodox-pcb-electrical-boards-set-of-2/

mattdibi, 2021-02-27:
@raymaclabs But... those are Ergodox PCBs not Redox PCBs.

Spamm3r, 2021-02-27:
I have bought mine as normal PCB's. So dunno.

raymaclabs, 2021-03-01:
Sorry bad cut and paste on my end. It was the redox ones here. There is no
listing for a b-stock pcb of redox.

https://falba.tech/product/redox-pcb-electrical-boards-set-of-2/

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

Closed 2021-02-25.

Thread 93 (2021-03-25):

Redox Wireless receiver LEDs not lighting up

Goldielocks, 2021-03-25:
I'm having an issue with the receiver: I can program it by header, but when I connect it to the Arduino Pro Micro, no lights appear. I've assembled several units at this point, since I ordered some redundant parts, and they all have the same behavior. If pin  validated the continuity (testing for shorts as well) but the lights still do not turn on.

I record a voltage drop over the LED/resistor as well, so it seems odd that nothing is visible. Do you have any thoughts?

Goldielocks, 2021-03-25:
https://photos.app.goo.gl/ZBaQ3kaNugr6mHov6
https://photos.app.goo.gl/jb4UTSCqM7cQC6G86

I've confirmed with Falba that their PCB's are behaving correctly. The above pictures are of one of the assembled boards.

Goldielocks, 2021-03-25:
Testing the voltage on my pins, it's becoming clear that none of them are reaching a sufficient low for current to pass. They seem to be floating. It's possible that the arduinos are no good. At least one of the ones I was testing with turned out to be the 3.3V Pro Micro

mattdibi, 2021-03-25:
> It's possible that the arduinos are no good. At least one of the ones I was testing with turned out to be the 3.3V Pro Micro

Yup. You should use 5V Pro Micros.

Goldielocks, 2021-03-25:
Sorry, this is not closed. The 5V Pro Micro has not solved my issue

mattdibi, 2021-03-26:
From #94

>  I think I've confirmed that the problem is on the Arduino/QMK side of things. It's an arduino micro clone, but it's still using an Mega32U4-MU. Arduino IDE identifies it as a leondardo, which I understand is fairly common for micro clones.

Did you pinpoint the issue? What resistor values did you use for the LEDs? Does the receiver works (i.e. keystrokes are registered?) Does this happen for all the LEDs?

Goldielocks, 2021-03-26:
The issue hasn't been pinpointed, but at least one receiver is working. Only the first one appears to have been bricked, which led me down a bit of a goose chase. In fact I'm writing on it now.

I'm referring to the LEDs on the receiver board. Now that it's transmitting, it appears that the bottom LEDs do function. I'm using the default configuration for the LED/resistor pairs. Red, Blue, Green, White in that order top to bottom. 330, 220, 330, 220.

mattdibi, 2021-03-27:
> I'm referring to the LEDs on the receiver board. Now that it's transmitting, it appears that the bottom LEDs do function. I'm using the default configuration for the LED/resistor pairs. Red, Blue, Green, White in that order top to bottom. 330, 220, 330, 220.

The LEDs light up when the layer is switched. To trigger a layer switch you need to press the following keys in the default keymap:

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

Refer to [the default keymap ](https://github.com/qmk/qmk_firmware/blob/master/keyboards/redox_w/keymaps/default/keymap.c)for details.

Please note that the fourth LEDs is not mapped to any function in the default keymap and thus won't light up.

>  I'm using the default configuration for the LED/resistor pairs. Red, Blue, Green, White in that order top to bottom. 330, 220, 330, 220.

You should be good then.

TheCatster, 2021-04-05:
I am having similar issues, I am using the SparkFun Pro Micro. However, I do not have any LEDs lighting even after following this issue. I have checked the leads and all seems proper, and my reset button works, but the LEDs do nothing. Any ideas for that (or should I make a new issue)?

mattdibi, 2021-04-05:
@TheCatster At this point I’m suspecting something broke in QMK. If you burn the pre compiled QMK hex files available [here](https://github.com/mattdibi/redox-keyboard/tree/master/redox-w/firmware) do the LEDs light up? That file (`qmk_redox_w_default.hex`) was built using an older version of QMK and should work.

TheCatster, 2021-04-05:
I'll try it out as soon as I'm done flashing the left hand here. To add to your possible suspicion, I haven't actually tried your QMK file yet, I have only compiled my own keymaps!

mattdibi, 2021-04-06:
Just tested it with the latest version of QMK firmware. Everything is working fine.

@TheCatster If you can't connect the transmitters to the receiver the LEDs won't light up as they're triggered by key presses. You won't get keypresses until the firmware for the trasmitters MCUs, the firmware for the receiver MCU and the QMK firmware for the Arduino are all burned on their MCUs as described [here](https://github.com/mattdibi/redox-keyboard/tree/master/redox-w#firmware). If you still have issues, please open a new issue.

@Goldielocks Since I didn't receive any update I'm closing this. Feel free to reopen this if you still have issues.

tterrag1098, 2022-03-20:
Hi, I'm currently running into this issue. I can only get the LEDs to work if I use the default firmware from the redox repository. If I try to compile it myself (using 0.15.25 due to https://github.com/qmk/qmk_firmware/issues/16553) everything seems to work fine *except* the LEDs on the arduino. Is there anything in QMK that could have changed to break this? Or a setting that needs to be changed from default?

tterrag1098, 2022-03-20:
Just to sanity check, I tried with the version of QMK that would have been latest at the time of your last comment, 0.12.32, and found the same behavior.

tterrag1098, 2022-03-20:
Okay, sorry for the triple post here, but I wanted to update you to say I found the solution.

The root cause is definitely that I am a noob, but I think there is a serious lack information here. It took me many hours to find that the LED behavior is implemented [in the keymap](https://github.com/qmk/qmk_firmware/blob/master/keyboards/redox_w/keymaps/default/keymap.c#L91-L109) at the very bottom. The very limited information about this I can find online never mentions this, and in fact seems to imply that it's built into the firmware.

All the guides to first time users creating their first firmware suggests to use the online configurator, which of course creates a keymap file from scratch, and won't have the above code in it. Is there no way this could be implemented into the keyboard-specific firmware code in QMK, rather than the keymap?

Again, sorry for all the comments about this, but I wanted to get all this info out there for others in the future, and in the hope it might be improved. Thank you for all your work on this keyboard, it really is great to use. This issue is minor in the grand scheme, after all.

TheCatster, 2022-03-21:
That's quite interesting. I actually gave up on the LED, thinking it was something I had done wrong (I guess in a way it was). This would be nice to get in the firmware, but as @tterrag1098 said it's a minor issue overall.

Closed 2021-04-06.

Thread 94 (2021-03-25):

Redox W Receiver Shows No Status Lights

Goldielocks, 2021-03-25:
Copied from the original issue:

I'm having an issue with the receiver: I can program it by header, but when I connect it to the Arduino Pro Micro, no lights appear. I've assembled several units at this point, since I ordered some redundant parts, and they all have the same behavior. If pin validated the continuity (testing for shorts as well) but the lights still do not turn on.

I record a voltage drop over the LED/resistor as well, so it seems odd that nothing is visible. Do you have any thoughts?

https://photos.app.goo.gl/ZBaQ3kaNugr6mHov6
https://photos.app.goo.gl/jb4UTSCqM7cQC6G86

I've confirmed with Falba that their PCB's are behaving correctly. The above pictures are of one of the assembled boards.

Goldielocks commented 3 hours ago
Testing the voltage on my pins, it's becoming clear that none of them are reaching a sufficient low for current to pass. They seem to be floating. It's possible that the arduinos are no good. At least one of the ones I was testing with turned out to be the 3.3V Pro Micro. Using a 5V micro does not solve this problem, but I notice that all 4 pins are sitting fairly high. If I ground any one of them, the respective light turns on.

Goldielocks, 2021-03-25:
I think I've confirmed that the problem is on the Arduino/QMK side of things. It's an arduino micro clone, but it's still using an Mega32U4-MU. Arduino IDE identifies it as a leondardo, which I understand is fairly common for micro clones.

mattdibi, 2021-03-26:
Closed as duplicate of #93 . Please continue on the original issue.

FYI you should have the permission to re-open an issue if it isn't solved.

Closed 2021-03-26.

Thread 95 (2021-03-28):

One column in the left side of the keyboard is malfunctioning

cyanindya, 2021-03-28:
Hello, apologies for opening another issue, but I'd like to hear your thoughts before going through the drastic measure of replacing the Pro Micro, since I'm not quite sure yet whether the fault lies in the Pro Micro itself or soldering on the PCB board.

So since this morning, one column in the left half of my Redox (5, t, g, b, thumb cluster button assigned to "left shift on hold and space on tap") started malfunctioning. Specifically, it suddenly became dead, and when I tried to re-plug the keyboard, the keyboard ended up inputting the whole column when I tried to press random key outside of that column (e.g. "a"), sometimes continuously until I somehow managed to stop it. The column stays dead, and it also affected another key in the other side (the outer-most 1.5u thumb key in the right half - I assigned it to "backspace", but it ended up inputting left shift as if the key was being hold down).

**EDIT:** Apparently, it also ended up screwing with the left shift input of the left half of the keyboard for some reasons... I leave layer 1 (the one directly above the QWERTY layer) for the shifted symbols for the left half, and when I am using that layer, the output are the numbers instead of the shifted symbols.

So far, for the hardware check, I already tried checking the diodes on the specified column and the pins connected to the keys in said column. I hadn't encountered problems possibly caused by improper soldering and such on the PCB so far - all diodes show the proper measurement when I tried using multimeter, and the row and column pins' connection seem to behave as expected (i.e. in that the targeted row and column pins are connected when I pressed the key switch down, but not the others). Because of this, I suspect the problem lies in the Pro Micro of the left half.

The thing is... I also tried crude method to figure out the problem, such as using jumper to directly short the targeted row and column pins, and doing the connectivity test on said pins using multimeter while the keyboard is plugged to the PC. For whatever reason, after trying this, the dead column problem will suddenly fix itself temporarily. The keyboard will work normally again for some time (10-20 minutes) before the dead column suddenly occurred again, again preceded by character input from the whole column even though I wasn't pressing any keys on that column.

What are your thoughts on this, and is it possible I may have missed something?

Thank you!

mattdibi, 2021-03-28:
Hi,

the problem you describe looks awfully like a cold joint.

These are particularly annoying to deal with because are hard to detect. In the past I had to deal with a cold joint on my job, it went unnoticed until some component stopped working all of a sudden (it was on an I2C connection). Poking around with a multimeter didn't show anything because the act of pushing the probes on the joint closed the circuit thus solving the problem. We found out because the I2C connection came back up when pushing on the PCB with a finger.

I suggest you to double check the solder joint of the affected column and the related pins on the Pro Micro. Look more closely on the Pro Micro side of things.

Hope this helps.

cyanindya, 2021-03-28:
Thank you for your input! It didn't occur to me that the cold joint may be the root of the problem.

As of now, I fixed the problem by replacing the Pro Micro with a new one since the unprompted input of the column persisted even when I took the switches of the column off and reflowing the Pro Micro pins didn't seem to have any effect (hence I suspected something might have gone off inside it), but I shall keep close eye on the solder joints of the affected parts as you said just in case.

Thank you again! I will close the issue for now.

Closed 2021-03-28.

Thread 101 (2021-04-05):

Cannot flash hex to either side of board (Redox-w v1.0)

TheCatster, 2021-04-05:
Hello! I was happily building my Redox wireless until about early March. Since then, I have been attempting to flash the hex firmware (even going to compile it myself) with no avail. I use Arch Linux on my main workstation and laptop, and have tried installing Ubuntu to better follow the guide on another laptop. I can connect with OpenOCD and telnet to the nrf52s, and "seem" to have a response, but no action. I use an official StLink v2. An example is here:
```
Open On-Chip Debugger 0.11.0
Licensed under GNU GPL v2
For bug reports, read
	http://openocd.org/doc/doxygen/bugs.html
WARNING: interface/stlink-v2.cfg is deprecated, please switch to interface/stlink.cfg
Info : auto-selecting first available session transport "hla_swd". To override use 'transport select <transport>'.
Info : The selected transport took over low-level target control. The results might differ compared to plain JTAG/SWD
Info : Listening on port 6666 for tcl connections
Info : Listening on port 4444 for telnet connections
Info : clock speed 1000 kHz
Info : STLINK V2J29S7 (API v2) VID:PID 0483:3748
Info : Target voltage: 3.221053
Info : nrf51.cpu: hardware has 4 breakpoints, 2 watchpoints
Info : starting gdb server for nrf51.cpu on 3333
Info : Listening on port 3333 for gdb connections
Info : accepting 'telnet' connection on tcp/4444
Info : dropped 'telnet' connection
Info : accepting 'telnet' connection on tcp/4444
Info : dropped 'telnet' connection
Info : accepting 'telnet' connection on tcp/4444
Info : dropped 'telnet' connection
```
And that's it. I get no response that it's resetting, one that's it's uploading, and nothing seems to be happening. Everything I echo is just accepted and then dropped. What could be the cause of this?

Thank you in advance.

mattdibi, 2021-04-05:
Hi,
can you show me the commands issued by the other terminal (the `echo` ones)?

In any case I recently updated the [redox firmware repository](https://github.com/mattdibi/redox-w-firmware) and it’s now possible to upload the firmware using Docker containers. You can give that a try.

TheCatster, 2021-04-05:
Sure, the commands issued were:
- `echo reset halt | telnet localhost 4444`
- `echo nrf51 mass_erase | telnet localhost 4444`
- `echo reset halt | telnet 127.0.0.1 4444`
All returned the same responses as the pictures on your documentation.

I will attempt the docker solution right now, and update you on that!

TheCatster, 2021-04-05:
Here is the Docker output for programming the right hand side. Correct me if I'm wrong, but that looks like it succeeded!
```
============================= PROGRAMMING =============================
Trying ::1...
Trying 127.0.0.1...
Connected to localhost.
Escape character is '^]'.
Open On-Chip Debugger
> reset halt
target state: halted
target halted due to debug-request, current mode: Thread
xPSR: 0xc1000000 pc: 0x00000dac msp: 0x20004000
> flash write_image erase /usr/src/nRF5_SDK_11/redox-w-firmware/redox-w-keyboard-basic/custom/armgcc/_build/nrf51822_xxac-keyboard-right.hex
auto erase enabled
Unknown device (HWID 0x000000d1)
using fast async flash loader. This is currently supported
only with ST-Link and CMSIS-DAP. If you have issues, add
"set WORKAREASIZE 0" before sourcing nrf51.cfg to disable it
target state: halted
target halted due to breakpoint, current mode: Thread
xPSR: 0x61000000 pc: 0x2000001e msp: 0x20004000
wrote 16384 bytes from file /usr/src/nRF5_SDK_11/redox-w-firmware/redox-w-keyboard-basic/custom/armgcc/_build/nrf51822_xxac-keyboard-right.hex in 0.698408s (22.909 KiB/s)
> reset
> Connection closed by foreign host.

============================== FINISHED ===============================
```

mattdibi, 2021-04-05:
For documentation purpose, the expected output of any of the

```
docker exec -it redox-w-firmware_toolchain_1 ./redox-w-firmware/redox-w-keyboard-*/program*.sh
```

is

```
============================= PROGRAMMING =============================
Trying 127.0.0.1...
Connected to localhost.
Escape character is '^]'.
Open On-Chip Debugger
> reset halt
target state: halted
target halted due to debug-request, current mode: Thread
xPSR: 0xc1000000 pc: 0x00000ba8 msp: 0x20004000
> flash write_image erase /usr/src/nRF5_SDK_11/redox-w-firmware/redox-w-keyboard-basic/custom/armgcc/_build/nrf51822_xxac-keyboard-right.hex
auto erase enabled
Unknown device (HWID 0x000000d1)
using fast async flash loader. This is currently supported
only with ST-Link and CMSIS-DAP. If you have issues, add
"set WORKAREASIZE 0" before sourcing nrf51.cfg to disable it
target state: halted
target halted due to breakpoint, current mode: Thread
xPSR: 0x61000000 pc: 0x2000001e msp: 0x20004000
wrote 16384 bytes from file /usr/src/nRF5_SDK_11/redox-w-firmware/redox-w-keyboard-basic/custom/armgcc/_build/nrf51822_xxac-keyboard-right.hex in 0.782274s (20.453 KiB/s)
> reset
> Connection closed by foreign host.

============================== FINISHED ===============================
```

while on the server side you should see:

```
openocd_1    | Open On-Chip Debugger 0.9.0 (2018-01-24-01:05)
openocd_1    | Licensed under GNU GPL v2
openocd_1    | For bug reports, read
openocd_1    | 	http://openocd.org/doc/doxygen/bugs.html
openocd_1    | WARNING: target/nrf51_stlink.cfg is deprecated, please switch to target/nrf51.cfg
openocd_1    | Info : auto-selecting first available session transport "hla_swd". To override use 'transport select <transport>'.
openocd_1    | Info : The selected transport took over low-level target control. The results might differ compared to plain JTAG/SWD
openocd_1    | adapter speed: 1000 kHz
openocd_1    | Info : Unable to match requested speed 1000 kHz, using 950 kHz
openocd_1    | Info : Unable to match requested speed 1000 kHz, using 950 kHz
openocd_1    | Info : clock speed 950 kHz
openocd_1    | Info : STLINK v2 JTAG v17 API v2 SWIM v4 VID 0x0483 PID 0x3748
openocd_1    | Info : using stlink api v2
openocd_1    | Info : Target voltage: 3.274320
openocd_1    | Info : nrf51.cpu: hardware has 4 breakpoints, 2 watchpoints
openocd_1    | Info : accepting 'telnet' connection on tcp/4444
openocd_1    | target state: halted
openocd_1    | target halted due to debug-request, current mode: Thread
openocd_1    | xPSR: 0xc1000000 pc: 0x00000ba8 msp: 0x20004000
openocd_1    | auto erase enabled
openocd_1    | Warn : Unknown device (HWID 0x000000d1)
openocd_1    | Warn : using fast async flash loader. This is currently supported
openocd_1    | Warn : only with ST-Link and CMSIS-DAP. If you have issues, add
openocd_1    | Warn : "set WORKAREASIZE 0" before sourcing nrf51.cfg to disable it
openocd_1    | target state: halted
openocd_1    | target halted due to breakpoint, current mode: Thread
openocd_1    | xPSR: 0x61000000 pc: 0x2000001e msp: 0x20004000
openocd_1    | wrote 16384 bytes from file /usr/src/nRF5_SDK_11/redox-w-firmware/redox-w-keyboard-basic/custom/armgcc/_build/nrf51822_xxac-keyboard-right.hex in 0.782274s (20.453 KiB/s)
openocd_1    | Info : dropped 'telnet' connection
```

You can see the OpenOCD server output by issuing:

```
docker-compose logs openocd
```

or by launching docker compose in foreground mode (without the `-d` in the launch command). The important line here is:
```
openocd_1    | wrote 16384 bytes from file /usr/src/nRF5_SDK_11/redox-w-firmware/redox-w-keyboard-basic/custom/armgcc/_build/nrf51822_xxac-keyboard-right.hex in 0.782274s (20.453 KiB/s)
```

By the look of it you should be good.

mattdibi, 2021-04-05:
For documentation purpose, the expected output of any of the

```
docker exec -it redox-w-firmware_toolchain_1 ./redox-w-firmware/redox-w-keyboard-*/program*.sh
```

is

```
============================= PROGRAMMING =============================
Trying 127.0.0.1...
Connected to localhost.
Escape character is '^]'.
Open On-Chip Debugger
> reset halt
target state: halted
target halted due to debug-request, current mode: Thread
xPSR: 0xc1000000 pc: 0x00000ba8 msp: 0x20004000
> flash write_image erase /usr/src/nRF5_SDK_11/redox-w-firmware/redox-w-keyboard-basic/custom/armgcc/_build/nrf51822_xxac-keyboard-right.hex
auto erase enabled
Unknown device (HWID 0x000000d1)
using fast async flash loader. This is currently supported
only with ST-Link and CMSIS-DAP. If you have issues, add
"set WORKAREASIZE 0" before sourcing nrf51.cfg to disable it
target state: halted
target halted due to breakpoint, current mode: Thread
xPSR: 0x61000000 pc: 0x2000001e msp: 0x20004000
wrote 16384 bytes from file /usr/src/nRF5_SDK_11/redox-w-firmware/redox-w-keyboard-basic/custom/armgcc/_build/nrf51822_xxac-keyboard-right.hex in 0.782274s (20.453 KiB/s)
> reset
> Connection closed by foreign host.

============================== FINISHED ===============================
```

while on the server side you should see:

```
openocd_1    | Open On-Chip Debugger 0.9.0 (2018-01-24-01:05)
openocd_1    | Licensed under GNU GPL v2
openocd_1    | For bug reports, read
openocd_1    | 	http://openocd.org/doc/doxygen/bugs.html
openocd_1    | WARNING: target/nrf51_stlink.cfg is deprecated, please switch to target/nrf51.cfg
openocd_1    | Info : auto-selecting first available session transport "hla_swd". To override use 'transport select <transport>'.
openocd_1    | Info : The selected transport took over low-level target control. The results might differ compared to plain JTAG/SWD
openocd_1    | adapter speed: 1000 kHz
openocd_1    | Info : Unable to match requested speed 1000 kHz, using 950 kHz
openocd_1    | Info : Unable to match requested speed 1000 kHz, using 950 kHz
openocd_1    | Info : clock speed 950 kHz
openocd_1    | Info : STLINK v2 JTAG v17 API v2 SWIM v4 VID 0x0483 PID 0x3748
openocd_1    | Info : using stlink api v2
openocd_1    | Info : Target voltage: 3.274320
openocd_1    | Info : nrf51.cpu: hardware has 4 breakpoints, 2 watchpoints
openocd_1    | Info : accepting 'telnet' connection on tcp/4444
openocd_1    | target state: halted
openocd_1    | target halted due to debug-request, current mode: Thread
openocd_1    | xPSR: 0xc1000000 pc: 0x00000ba8 msp: 0x20004000
openocd_1    | auto erase enabled
openocd_1    | Warn : Unknown device (HWID 0x000000d1)
openocd_1    | Warn : using fast async flash loader. This is currently supported
openocd_1    | Warn : only with ST-Link and CMSIS-DAP. If you have issues, add
openocd_1    | Warn : "set WORKAREASIZE 0" before sourcing nrf51.cfg to disable it
openocd_1    | target state: halted
openocd_1    | target halted due to breakpoint, current mode: Thread
openocd_1    | xPSR: 0x61000000 pc: 0x2000001e msp: 0x20004000
openocd_1    | wrote 16384 bytes from file /usr/src/nRF5_SDK_11/redox-w-firmware/redox-w-keyboard-basic/custom/armgcc/_build/nrf51822_xxac-keyboard-right.hex in 0.782274s (20.453 KiB/s)
openocd_1    | Info : dropped 'telnet' connection
```
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
TheCatster, 2021-04-05:
Yup, that was it for the hands. Just my two cents, but I honestly think the docker method should be the one described in the docs, it's well done. Although this confirms I have an issue with my Arduino or wiring of the receiver, since I still cannot connect to it. I might swap it with a 100% official one to make sure that the issue isn't a knock off. Thank you for your help with this issue!

mattdibi, 2021-04-05:
> Just my two cents, but I honestly think the docker method should be the one described in the docs

Yeah, I was debating this with myself just today. Thanks for the feedback ;)

> Although this confirms I have an issue with my Arduino or wiring of the receiver, since I still cannot connect to it.

If you still have issues open a new issue dedicated to it.

mattdibi, 2021-04-05:
@TheCatster BTW just double checking: did you burn the firmware on the receiver’s YJ14015 ?

TheCatster, 2021-04-06:
I cannot, that was my major issue right now. I got busy with some other things, but am trying to desolder my Arduino Pro Micro and swap it, I did have an illegitimate one.

Closed 2021-04-05.

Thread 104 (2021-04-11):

Hotswap Compatibility with Wireless PCB

TrapTrancer, 2021-04-11:
Hello, I have 3 questions about the wireless PCBs:
1) Does the kailh hotswap socket on the version 2 pcb have to specifically be the one mentioned in the BoM?
2) Can I use other hotswap options like copper rivets?
3) will https://www.aliexpress.com/item/4000333694486.html work on the receiver?

Thanks for the help as I am pretty new to keyboards still.

mattdibi, 2021-04-11:
Hi,

1. PCB Rev2.0WHS accepts Kailh Hot-Swap sockets (CPG151101S11), other types of hot swap sockets (like K4 Gaterons) were not tested at the time of this writing.
2. Copper rivets (a.k.a. Holtite sockets, a.k.a. Mill-Max sockets) are not compatible with Rev2.0WHS. They might be compatible with Rev.1.0W but I haven't tested them nor I intend to do so (I designed Rev2.0WHS to this exact purpose). The Holtite sockets mod is documented [here](https://github.com/mattdibi/redox-keyboard/tree/master/redox#hot-swappable-switches) for the non-wireless Redox.
3. Nope.

Hope this helps.

TrapTrancer, 2021-04-11:
Thanks for the help, I think I'll try the rev1 pcb with the copper rivets then.
I know this next question is a lot to ask, but do you know of a cheap (preferably $10 or lower) microcontroller that won't have the USB port ripped off?

Closed 2021-04-16.

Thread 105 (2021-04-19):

Only one side works

SirRonBird, 2021-04-19:
Greetings.
First of all i wanna say thank you for this awesome project. It was much fun to build this keyboard.

until now everthing works fine but after i flashes the boards, with the default firmware, the rightside of the keyboard dont work. I use a TRRS-Cable. (triple checked).I also checked the connection with a multimeter and it seems fine. I am a little bit confused, cause I dont know wether i have to solder the resistors, even if I dont use the rgb lights. (I´ve soldered them on). Could this be the Issue?

Do the config.h file have to say I2C or Serial-Connection ? I tried both none worked... iam a little bit desperate

mattdibi, 2021-04-20:
Hi,

first of all, do they work independently? (i.e. if you plug in the right side, does it work?) Did you burn the firmware also on the right side? Did you check continuity on the TRRS plugs to the Arduino? Did you check the other already opened issues? ( #97 #77 #71 )

SirRonBird, 2021-04-20:
Hi. Yes they work independently. If I plug either side to the Computer both work. Just the otherone dont.
Yes i burned the firmware on both (both have the same firmware !?)
Yes i checked the TRRS Plugs. I could messure a through put from the plug from the one side to the pin of the other side.
Yes. In the other issues they had an other Problem.

mattdibi, 2021-04-21:
If they work independently there must be something wrong with the link between the two halves.

> Yes i burned the firmware on both (both have the same firmware !?)

Yes, they both have the same firmware. Each side scans the matrix but only the plugged side send the key codes.

> I could messure a through put from the plug from the one side to the pin of the other side.

If you soldered the 4.7k resistor you should use the I2C communication. Did you enable it? Otherwise you can remove the resistor and use the serial communication (the default configuration). Keep in mind that I2C uses two wires for data, did you check continuity on both?

SirRonBird, 2021-04-22:
What exactly you mean with two wires? I have the TRRS-Cable plugged in and tested all poles in it.

I already tried with i2c enabled...

mattdibi, 2021-04-22:
> What exactly you mean with two wires? I have the TRRS-Cable plugged in and tested all poles in it.

Every pole carries a wire. An I2C connection used 4 wires or connections: VCC, GND (aka power), SDA, SCL (aka data).
Did you check that SDA, SCL are correctly wired through the two halves by the TRRS connector?

Follow this thread for more informations: https://github.com/mattdibi/redox-keyboard/issues/33

Ensure that, when the TRRS cable is connected, the PD0 pin of the left Arduino is connected to the PD0 pin of the right Arduino. The same goes for the PD1 pin.

Also: does the right hand Arduino lights up when connected to the left hand?

SirRonBird, 2021-04-22:
Ok. I checked the cable again and it seems that the tips of both ends are not connected. I will buy a new cable and try it again
The other side lights up...

mattdibi, 2021-04-22:
> Do you have a tip were i can get a custom TRRS Cable?

There are a few vendors around. Here's a short and (surely) incomplete list.
- [Coolcables](https://www.coolcable.co.uk/gb/trrs-cables/61-10630-custom-audio-cable.html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) (UK)
- [ZapCables](https://zapcables.com/diy-trrs-cable-kit/) (USA)
- [Kriscables](https://kriscables.com/product/trrs-cables/) (EU)

I used Coolcables in the past but they're out of stock in the TRRS department right now unfortunately

SirRonBird, 2021-04-23:
I just got the new cable hooked up and it still not working... I´ve checked the cable and the continuity between PD0 Pins and between PD1 Still only one side is working.... I down know why...

SirRonBird, 2021-05-10:
Hello. Ive rechecked everything and its still not working. The new cable is fine and the Pins SDA and SCL are connected. Does anyone have an other idea what the problem can be ?

SirRonBird, 2021-05-20:
So I worked a littlebit on the keyboard and it turns out, that something was wrong with the pcb. I build the right side again and now everything works.

Closed 2021-05-20.

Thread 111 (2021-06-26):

Keyboard stopped working after a short while

Andrea-Perin, 2021-06-26:
Hi
I have built two Redox keyboards, but one of them is having major issues.

Issue description: after I flashed it with QMK toolbox's auto flash, the keyboard worked properly.
However, after some 5 minutes or so, it stopped working. The LEDs were on, but the keyboard wasn't being detected.
After some hours I tried it again, and this time it worked. However, the next day, it alternated between working and not being detected, in bursts of some minutes.
I can not re-flash it, as it is not being detected by the computer, so I am stuck with no apparent reason for this behavior.

Preliminary checks: I checked all the soldering points, and there are no obvious issues there. Both Pro Micros should be fine (or at least, they were at the time of the first flashing). The cables I am using are also working with the other Redox.

Do you have any ideas about what could be causing this?

Btw, thank you for the project!

mattdibi, 2021-06-27:
Ciao Andrea,

this is a new one.

Did you try plugging in the USB in the other half? If so, the behaviour is the same for both halves? Did you check the USB cable? Have you tried pluggin the two halves independently (i.e. without the TRRS cable)?

> The LEDs were on, but the keyboard wasn't being detected.

Are we talking about Pro Micro's LEDs or backlighing LEDs?

Andrea-Perin, 2021-06-27:
Ciao,
thank you for the prompt reply. To answer your questions:

- When it does not work, plugging either half makes no difference, it is simply not detected (if it can be of any help, I did not set any value for the master hand flag in the header file, so if I am not mistaken, the left should be the master).
- The USB cables I am using are both working with no issues with the other Redox I built; they are USB cables that came with a phone, so I would assume they are fine.
- As for plugging them separately, I did not try that.
- I was referring to the Pro Micro's LEDs, there are no backlighting LEDs.

As a matter of fact, I wrote half this reply with the Redox itself, but I am ending it with the laptop's keyboard, as the Redox stopped being detected halfway through.

I ran `lsusb` while it was working, and `Falbatech The Redox Keyboard` appeared among the outputs. Right now, instead, it's either not detected at all, or `Arduino SA Leonardo Bootloader' comes up.

mattdibi, 2021-06-27:
> it's either not detected at all, or Arduino SA Leonardo Bootloader comes up.

Interesting. Looks almost like the Arduino puts itself into programming mode by its own. Could there be a short in the RST (reset) pin area? Could you be sending the reset code via software by any chance?

> As for plugging them separately, I did not try that

Give that a try to rule out the cable or one of the Arduinos. By plugging in the slave half by itself it should output the mirrored matrix IIRC.

Also at this point it seems to be reproducible: after being plugged in it works for some time then it’s puts itself into programming mode. I would try to reflash the firmware just in case, but it seems to me that there might be a problem with the master half Pro Micro.

Andrea-Perin, 2021-06-27:
Ok, so I tried the two halves separately: it seems that the right one works fine (as you said, it mirrors what is supposed to be one the master side), and the left one is the problematic one.
I tried removing the reset button on the left half, hoping it was defective and thus causing all the problems, but no luck there. Still the exact same problems.
As for sending a reset code via software, there is no reset key in my mapping, so unless there is something doing it without me knowing, I would rule that out.

I was wondering, could it be due to bad soldering? Like, maybe some overheating due to imperfections in the way it was soldered. I say this because once it stops working, there is no guarantee that it works if you plug it back right away. So maybe there is something more "physical" about it?

Either way, I will try reflashing it when I have time, and see if that helps. Thank you so much for now, I will get back to you with the updates.

mattdibi, 2021-06-27:
> So maybe there is something more "physical" about it?

Yeah, by the looks of it I would say that this is a hardware issue with the left hand Arduino.

Try giving another pass to the Arduino soldering joint, maybe adding some more solder, just to be sure.

Andrea-Perin, 2021-08-01:
Hi again, I am back with some good news! I finally got my hands on a working soldering iron yesterday, so I tried re-soldering the left hand side Arduino. Interestingly, most of the soldering points "fizzled", as if some air bubbles were trapped inside them. When I plugged the keyboard back in, it worked. I have been using it for the past 2 days and I have yet to notice any problems.

Most likely, it was a matter of bad soldering joints, as you suggested. I will close the issue, since now everything seems fine.
Thank you so much!

Closed 2021-08-01.

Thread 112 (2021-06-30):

Odd rollover issue

JamesYeoman, 2021-06-30:
After going through hell attempting the handwire version, I finally decided to buy some PCBs. I've finally gotten to a firmware flash for the left hand, and everything seems to be working great. However, there's some weird rollover that I've noticed.

When holding D down and pressing A, it rolls over correctly. So far so good.
When holding F and pressing S, it rolls over to S, and then rolls over to D for some strange reason. And it's the entire column that it happens on. The rollover has to occur on the same row (it doesn't freak out when R is held and S gets pressed). Holding 4 and pressing 2 results in a 2->3 rollover.
V+X => X->C
B+C => C->V
And so on.
[+F doesn't result in F->G, however.

It's the columnar nature that makes me _fairly confident_ that it's not a soldering issue. It wouldn't be that consistent of results if it were simply a soldering issue. And if it was the column pins being shorted, then it wouldn't matter whether the beginning key was on the same row as the rollover key.

As a sanity check, I did a quick sweep of the pcb and couldn't find anything out of the ordinary...

It's a weird one, this is...

mattdibi, 2021-07-01:
> It's the columnar nature that makes me fairly confident that it's not a soldering issue.

Actually, the columnar nature of the issue is a clear indication that might be a soldering issue.
I'll borrow the troubleshooting guide from the Corne build guide:

> A full row/column of keys not working
If a full row or column of keys is not working, then the culprit is most likely the connection between the PCB and the ProMicro. Check your soldering and make sure there's a proper connection and that you have soldered the ProMicro in the right set of holes. If soldering looks okay, then your ProMicro might be damaged. You can exclude the possibility of problems with the PCB, paths and diodes by short circuiting the pins on the ProMicro directly, using a bit of wire. Connecting one row pin with one column pin should result in the corresponding key. Some PCBs have silkscreen print indicating which pin is which row or column, to make this process easier.

JamesYeoman, 2021-07-01:
Ah. Thanks. I'll have a look after work and give you an update

JamesYeoman, 2021-07-05:
I've had some issues with the desoldering, which has meant the destruction of the pro micro. It was the only one I had, too. I'm going to have to close this issue for now because I can't afford any pro micros until payday.

Closed 2021-07-05.

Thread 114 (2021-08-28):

Requesting Kicad files for rev 2.0WHS

Bombergames, 2021-08-28:
It looks like the rev 1 kicad files were updated with the 2.0 commit, but it doesn't have the actual updated files for the rev 2.0 board.

jesper1266, 2021-09-20:
Hi, I second that :-)
I would like to help.
It would for example be nice tha the pinheader for uploading the firmware is the same for both the board and reciever.

Cheers
Jesper

mattdibi, 2021-09-26:
Hi guys,

unfortunately I'm having issues with recovering the files: my Windows installation decided to brick itself after an update and cannot access it anymore. I'll try and upload the files when/if I recover them.

PhiBabin, 2021-11-21:
Hi guys,
I rebuilded the KiCad of rev 2 by using the rev 1 as a starting point and using the gerber files of the rev 2 as reference. I included some of the modified footprints its own library.

KiCad project file: [redox_rev2_recovery_kicad.zip](https://github.com/mattdibi/redox-keyboard/files/7575625/redox_rev2_recovery_kicad.zip)
Gerber file from rebuild: [redox_rev2_recovery.zip](https://github.com/mattdibi/redox-keyboard/files/7575623/redox_rev2_recovery.zip)

Original gerber top layer:

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

Rebuild gerber top layer:
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

Original gerber bot layer:
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

Rebuild gerber bot layer:
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

This is my first time using KiCad, so use this at your risk and peril.

KeyTamer, 2021-12-17:
First thanks, a lot for the KiCad file!
A other think. Did you test it all ready?

PhiBabin, 2021-12-21:
Yeah, I send it to AllPCB and they worked fine. I'm typing on it right now.
The only issues I had are :
 - The diode direction is not visible because the pads are too close to the marking. However, from looking at the image of the original, it seems that it has the same issue. This doesn't really matter, since the guide said that you just have to oriented the diode toward the square pad. It should be super to fix that in a future version.
 - The holes for the hotswap are not circular, they are skew (see last picture). This mean that when you insert each hotswap you get a very satisfying *click*. It also mean that your fingers are going to hurt after putting 70 hotswaps. I don't think the kidcad project is the cause of this, this is probably an issue with how I exported the Gerber or with AllPCB or a normal issue when doing overlapping hole like this. Anyway, it really doesn't matter and it's a very minor issue.

Note : The version that I printed is different from the KiCad project files shared above, I added the option of putting a rotary encoder at the location used by key K16. I want to finish the QMK+firmware changes before sharing it.
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

widget-, 2022-04-24:
@PhiBabin I'm interested in trying this out and probably opening a pull request into this repo assuming it goes well. Can you confirm that you're releasing it under the same [MIT license](https://github.com/mattdibi/redox-keyboard/blob/master/LICENSE) as the original project?

PhiBabin, 2022-04-26:
Yes, I'm  releasing it under MIT license.
Sorry forgot to upload them a fork.

l4u, 2022-07-02:
@PhiBabin Do you have a forked version or a pull request please? I'd like to make modifications based on your version with proper git history.

PhiBabin, 2022-07-24:
@l4u  sorry for the delays... https://github.com/mattdibi/redox-keyboard/pull/151

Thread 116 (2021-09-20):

Problems flashing the arduino

jesper1266, 2021-09-20:
When i try to flash the arduino I have the following issues.
The board that i have (blue 24 pin micro pro) does not have a reset button onboard.
I've tryed unplugging and replugging the board. This results in this feedback from the programmer:

make redox_w:default:avrdude
QMK Firmware 0.14.16
Making redox_w with keymap default and target avrdude

avr-gcc (GCC) 5.4.0
Copyright (C) 2015 Free Software Foundation, Inc.
This is free software; see the source for copying conditions.  There is NO
warranty; not even for MERCHANTABILITY or FITNESS FOR A PARTICULAR PURPOSE.

Size before:
   text	   data	    bss	    dec	    hex	filename
      0	  22572	      0	  22572	   582c	.build/redox_w_default.hex

Compiling: quantum/command.c                                                                        [OK]
Linking: .build/redox_w_default.elf                                                                 [OK]
Creating load file for flashing: .build/redox_w_default.hex                                         [OK]
Copying redox_w_default.hex to qmk_firmware folder                                                  [OK]
Checking file size of redox_w_default.hex                                                           [OK]
 * The firmware size is fine - 22572/28672 (78%, 6100 bytes free)
Waiting for USB serial port - reset your controller now (Ctrl+C to cancel)............. (HERE I REPLUG THE PCB)
Device /dev/ttyACM0 has appeared; assuming it is the controller.
Waiting for /dev/ttyACM0 to become writable.

Connecting to programmer: .avrdude: butterfly_recv(): programmer is not responding

avrdude: butterfly_recv(): programmer is not responding
avrdude: butterfly_recv(): programmer is not responding
avrdude: butterfly_recv(): programmer is not responding
avrdude: butterfly_recv(): programmer is not responding
avrdude: butterfly_recv(): programmer is not responding
Found programmer: Id = "�"; type = p
    Software Version = �.!; Hardware Version = �.
avrdude: butterfly_recv(): programmer is not responding
avrdude: butterfly_recv(): programmer is not responding
avrdude: error: buffered memory access not supported. Maybe it isn't
a butterfly/AVR109 but a AVR910 device?
avrdude: initialization failed, rc=-1
         Double check connections and try again, or use -F to override
         this check.

avrdude: butterfly_recv(): programmer is not responding
avrdude: error: programmer did not respond to command: leave prog mode
avrdude: butterfly_recv(): programmer is not responding
avrdude: error: programmer did not respond to command: exit bootloader

avrdude done.  Thank you.

make[1]: *** [platforms/avr/flash.mk:119: avrdude] Error 1
Make finished with errors
make: *** [Makefile:539: redox_w:default:avrdude] Error 1

Does anybody know what s going on?

jesper1266, 2021-09-20:
Turns out one just need to short the reset pin to ground

Closed 2021-09-20.

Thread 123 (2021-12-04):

keyboard stops working after some time.

BartStikkers, 2021-12-04:
See title. Unplugging the USB and plugging in again fixes it, but it happens often enough that the keyboard isn't usable. When it happens seems to have no connection to how long it's been plugged in or when it's last been used. It sometimes happens in the middle of typing.

mattdibi, 2021-12-06:
What type of Redox are you using? Wired or wireless?

BartStikkers, 2021-12-06:
Wired, the rev1 with the PCBs from Falba.

mattdibi, 2021-12-06:
Mh... this is really unexpected.

My first suspect would be hardware:
- Double check all solder joints for any kind of short, especially on MCU pins
- Could be a bad Pro Micro. Try using one half at a time and check whether the issue appears on only one half. This could also pinpoint where the (eventual) short could be

BartStikkers, 2021-12-06:
That was my first thought as well, but I can't find any shorts. I wouldn't be surprised if there was something wrong with these Arduinos though, they were really cheap. I've reflashed them just to rule out any issues from the first time and the problem hasn't reoccured. The only thing I think I'd changed though is the communication between the halves from serial to i2c, maybe I did something wrong there that caused it? I'll try using it tomorrow, see if the problem reoccurs.

BartStikkers, 2021-12-07:
Problem appears solved, so I guess I screwed something up when I was messing with the config files. Thanks for thinking along!

imalexlab, 2022-01-11:
I'm having the same issue, also i2c, do you remember what did you change in the files @BartStikkers ?

BartStikkers, 2022-01-15:
iirc:  qmk_firmware/keyboards/redox/keymaps/default/config.h I swapped the lines for USE_SERIAL and USE_I2C, commenting one and uncommenting the other.

Closed 2021-12-07.

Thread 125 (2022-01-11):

Sourcing Parts

buddylindsey, 2022-01-11:
There is still a lot I do not understand on what particular parts I need. I am just taking what is listed in the Wireless parts and buying them.

I am left with the resistors, LEDs, headers, and momentary switch. Being surface mount and not understanding what some of the stuff is. I put together a chart where I am trying to source parts from to make sure if I order them I am ordering the correct.

Can someone double check me please? I don't want to order everything and waste time and money because I am being stupid and order something wrong.

Here is my table of parts and links:

|item|link|
|-|-|
|330 Ohm 0805(2012 metric) SMD resistors|https://www.digikey.com/en/products/detail/ERJ-6ENF3300V/P330CCT-ND/1746851?itemSeq=386817440|
|220 Ohm 0805(2012 metric) SMD resistors|https://www.digikey.com/product-detail/en/RCS0805220RJNEA/541-2862-1-ND/5867155?itemSeq=386817758|
|1.5k Ohm 0805(2012 metric) SMD resistors|https://www.digikey.com/product-detail/en/ESR10EZPF1501/RHM1.50KAECT-ND/1983817?itemSeq=386818029|
|Red 0805(2012 metric) SMD standard LED|https://www.digikey.com/en/products/detail/lumex-opto-components-inc/SML-LX0805IC-TR/515787|
|Blue 0805(2012 metric) SMD standard LED|https://www.digikey.com/en/products/detail/dialight/5990191007F/9385414|
|Green 0805(2012 metric) SMD standard LED|https://www.digikey.com/en/products/detail/sunled/XZMG54W-1/4745961|
|White 0805(2012 metric) SMD standard LED|https://www.digikey.com/en/products/detail/qt-brightek-qtb/QBLP631-IW/4814683|
|Through hole momentary switch|https://www.mouser.com/ProductDetail/CK/PTS645SK43JSMTR92-LFS?qs=TiOZkKH1s2TgjwNoJW7SNA%3D%3D|
|Right angle 0.1" header (1x4pin)|https://www.pololu.com/product/2704|
|Straight 0.1" header (1x6pin)|https://www.pololu.com/product/1016|

mattdibi, 2022-01-11:
Hi @buddylindsey,

from what I see everything looks in order.

A couple of notes:
- All the materials for the Redox Wireless are meant to be easily found on ebay for (usually) a cheaper price than Digikey/Mouse etc. Did you try and take a look there? Like you can get an assortment of leds (like I did) [here](https://www.ebay.com/itm/192211418194?hash=item2cc0b17c52:g:SnIAAOSwLsBZOUYA). The same goes for the resistors.
- I noticed that all your headers pin are female. Is this correct? Do you have the necessary jumpers for plugging everything into the ST-Link programmer?
- The LEDs (and related resistors) are not strictly required for the keyboard to work, you only _need_ R1, R2 and R3 resistors.

buddylindsey, 2022-01-12:
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

I did not realize that. I will check ebay out for sure.

> * I noticed that all your headers pin are female. Is this correct? Do you have the necessary jumpers for plugging everything into the ST-Link programmer?

I don't have an ST-Link programmer yet. I hadn't gotten that far in the purchasing process. I kind of am just copy/pasting and searching for what you have listed trying to find parts. So TBH not sure what all I need in the end.

> * The LEDs (and related resistors) are not strictly required for the keyboard to work, you only _need_ R1, R2 and R3 resistors.

I like the idea of the LEDs so I wanted to use them.

mattdibi, 2022-01-14:
> I think I have the male ends of the headers already. Is this what I need? If so I have them.

They're the one I was referring to.

> I don't have an ST-Link programmer yet. I hadn't gotten that far in the purchasing process. I kind of am just copy/pasting and searching for what you have listed trying to find parts. So TBH not sure what all I need in the end.

The ST-Link programmer is needed to upload the firmware to the YJ-14015 MCUs. See [firmware guide](https://github.com/mattdibi/redox-keyboard/tree/master/redox-w#firmware) for details.

buddylindsey, 2022-01-14:
Awesome thank you. I have a programmer on order and should be here today, hopefully. Now to wait on the rest of the stuff. Interestingly the pub boards from pcbway has proven to be one of the fastest things to come in.

Thank you for this it is going to be awesome.

buddylindsey, 2022-02-19:
Okay I am going to close this as I am pretty sure all of the parts have come in now. Hopefully I can start on this thing soon, we as soon as I get a new tool to arrive, heh.

Will also post up another question later I have on cases, and which cases to print.

Closed 2022-02-19.

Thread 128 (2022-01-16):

Falbatech PCB case compatibility

Decappi, 2022-01-16:
Hi,

The Wireless Rev2 case is not compatible with the latest Falbatech's PCB, as the moved diode positions do not nicely align with the bottom plate.
Right now I'm printing the Rev1 version.
Falba's updated PCB is based on the revision 1 with some of the hardpoints rotated, the bottom row moved up + Hot swap pads.
Would you be so kind to generate the Rev2 STLs for this one as well? I've tried to do this myself, but I failed miserably in blender, so here I am, asking you for help :)

I've attached some pics of the plate, I could also scan it if you'd like a less skewed look:
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

mattdibi, 2022-01-17:
Hi @Decappi,

are you referring to [this](https://github.com/mattdibi/redox-keyboard/tree/master/redox-w/rev2.0WHS/case) case?

This case was designed using the KiCAD PCB files as a starting point. Not having access to Falbatech's ones (or one of their PCBs) this gets really hard to replicate.

Have you considered using Fusion360 instead of Blender? It should be easier for you to modify the .STEP with that.

Decappi, 2022-01-17:
Hi @mattdibi,

yes, I was referring to this case.
I'll try to contact Falbas for access to those files. Worst case I can send you one of the physical PCBs, as I have 6 of them right now.

About the fusion thing - I'm a software engineer, not a real engineer, so neither do I have Fusion360 licence, nor the real understanding of how to do this even if I have the software.

mattdibi, 2022-01-18:
> Worst case I can send you one of the physical PCBs, as I have 6 of them right now.

Yeah, currently I don't have the time nor the will to work on this. Don't worry about that.

> About the fusion thing - I'm a software engineer, not a real engineer, so neither do I have Fusion360 licence, nor the real understanding of how to do this even if I have the software.

I too am a software engineer and Fusion360 is free for hobbyist. Give it a try!

Decappi, 2022-02-18:
I've tried using the Fusion360. That's been a pretty soul crushing experience to say the least, as it doesn't exist for Linux, the wine version is broken and the browser version is just so slow I can't finish anything before the heat death of the universe.

As of now, there are no freely available printable cases that are compatible with the falbatech PCBs, so I've created a PR with the updates to the Readme, so that the next builders will know that they need to buy the cases from Falba in order to use the PCBs.

Closed 2022-02-19.

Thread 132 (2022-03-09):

Battery Drain if soldered poorly

buddylindsey, 2022-03-09:
I just wanted to note an issue I ran into with the Rev2WHS. Might be worth adding a note to the docs somewhere, or close this and leave it here for if someone searches closed issues like I do.

I think I soldered the battery holder a bit too far back and the Hot Swap piece to far forward so that when I push the batter all the way in on one of my sides it touches the hot swap connector. I think this drained my batter in a matter of a few days because as soon as I swapped out the battery the keyboard worked just fine again.

Just wanted to bring it up as a problem that can happen if you aren't careful.

mattdibi, 2022-03-09:
Thank you for pointing this out. I would keep this issue here for documentation purposes as you suggested.

Zielak, 2022-06-04:
Same happened here, but that's how my PCB was printed. One fix is to just place some insulating tape over that hot-swap socket.

Closed 2022-03-09.

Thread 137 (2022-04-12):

Right half of Redox Handwire not recognized by VIA

wryman, 2022-04-12:
Hi!

I just finished wiring my redox (first handbuilt) and flashed both Pro Micro's with the default VIA firmware and cannot get the right half to be recognized when both halves are connected with the TRRS cable, both mc's power up when connected via TRRS just no keypresses are recognized on the right half.   Each half is recognized independently as a left hand module with all keys working when connected with USB.

I have wired the TRRS in the i2c configuration shown in the schematic with the 2-4.7k ohm pull ups located in the left hand module, I have tested continuity and resistance between all pins across the TRRS cable and everything checks out as expected. I have confirmed that my Pro Micro's both have the J1 jumper unbridged.  I have tried clearing EEPROM's, reflashing with the VIA hex and setting left/right handedness in EEPROM with QMK toolbox with no success.  I have also tried wiring the TRRS jacks in serial with the soft serial pin on the default pin2/pd0 to rule out issues with the pull-ups, but was met with the same result (right half not recognized).

Am I missing a step somewhere? The only thing I can think of is that the VIA fw is missing some crucial function, I see that pin 2/PD0 is the soft serial pin set in the config files and I have confirmed that my pinouts are correct so I'm at a bit of a loss.  I don't have much experience with compiling custom QMK firmwares so I figure I'm missing a setting somewhere.

FWIW, I do not have any RGB LEDs connected.

CameronWeller, 2022-04-12:
I have had the exact same issue ! I actually did a handwire build but the wiring is very similar, just with serial instead of I2C. What i ended up having to do was change the configuration to #define enable_split_usb_detect or something along that line. It seems the via build doesn't have the configuration right and its hard to change that because via is actually closed source. I am currently working on a vial (open source competitor) build. I can send you the relevant build if need be.

wryman, 2022-04-12:
Hey, Thanks! That'd be awesome if you could send the build.  At least that
way I can get it up and running and see what the differences between the
config.h files are and maybe try and work backwards from there.

On Tue, Apr 12, 2022 at 4:02 PM CameronWeller ***@***.***>
wrote:

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

CameronWeller, 2022-04-12:
totally, might be a while as there have been some hiccups in the setup as I am kind of a noob at the software side of things.

wryman, 2022-04-13:
>

No worries, thanks for replying.

wryman, 2022-04-13:
>

Bit of an update, I reflashed both halves with the default QMK keymap with the #define EE_HANDS parameter added to the config.h and am able to get each individual half working as the corresponding left/right when connected via USB separately.  However when I connect the TRRS cable and then plug the left half into USB, I now get no inputs whatsoever from either half.

wryman, 2022-04-13:
Well I figured it out! the Pro Micro clones I had purchased had the pads on J1 joined with a trace beneath the mask! I have some images that show the pads with and without the trace cut.  Cutting the trace between the J1 pads on the slave side fixed it for me!

[https://imgur.com/ayUx8Q3](url)
[https://imgur.com/OKROYgI](url)

Closed 2022-04-13.

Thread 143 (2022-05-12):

Right side don't work

brunooomelo, 2022-05-12:
hi, i followed the tutorial, the left side of the keyboard is correct but the right side is not detecting the keys

mattdibi, 2022-05-13:
Is it a wired keyboard? If so, did you check connectivity on the TRRS cable? Did you check soldering issues on the TRRS connector? On the Pro Micro? Did you try the pro micros before installing (especially the one that's not working)? Did you burn the firmware on both pro micros?

brunooomelo, 2022-05-14:
I did all the procedures, I installed it correctly, I checked the connectivity, I burned the firmware on both pro micro, only the right side doesn't work, it lights up the led but the keys don't work

mattdibi, 2022-05-14:
Are you using I2C or serial for connecting the two halves? On the latest builds of QMK there seems to be an issue with I2C.

In any case the most common type of issue is with the hardware. Please check for cold joints and/or soldering issues on the board especially around the TRRS connectors.

brunooomelo, 2022-05-14:
I tested the connection of the TRRS between the sides and it is normal

brunooomelo, 2022-05-16:
can I use serial instead of i2c without rgb?

mattdibi, 2022-05-16:
RGB only works with serial since one of the wires of the trrs cable is used to carry the data signal for RGB. This is explained [nere](https://github.com/mattdibi/redox-keyboard/tree/master/redox#rgb-underglow-firmware).

Closed 2022-07-27.

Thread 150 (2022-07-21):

Redox W 2.0 working intermittently

ChrisMcD1, 2022-07-21:
Hello,

I've been working on my Redox Wireless 2.0 for the past several months. It's certainly been a journey. I didn't want to make a Github issue if I could avoid it since most of them seem to be solved by somebody coming back and saying that they soldered it correctly.

Today I finally got my first keystrokes out of my redox after swapping out my arduino for a fresh one, but then it randomly stopped working! Since then I have had it successfully run on two machines, but then stop working once I power off the transmitter boards. Since this happened on the second machine, I have been unable to get any keystrokes out of the system. I've tried restarting my computer and even re-flashed the arduino and the 3 YJ-14105's.

The only other sign I have that something is wrong is that the battery life on my coin cell batteries has been surprisingly low. Earlier today a battery that I put in a month ago was practically dead and reading 2.3V. I've checked all of the adjacent pins on the YJ-14015's on the transmitter boards to check for shorts and I didn't find any. I'm thinking that it's possible that the transmitters spent a month constantly on trying to connect to the receiver board and never finding it, so that drained the battery faster than the estimated battery consumption? For the record, I am using the 3D printed case.

Has anyone ever seen behavior similar to this where the transmitters will not reconnect after being power off?

EDIT: I've attached some photos of my boards to see if they can provide any valuable information.
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

aweiland, 2023-07-29:
I'm having the same issue as well.  It randomly worked once, but it hasn't worked since.

Closed 2024-07-08.

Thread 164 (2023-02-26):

Only connected side is working

joe-batt, 2023-02-26:
So this is yet another "only one side working issues".

- I'm using the serial connection (without resistors)
- TRRS cable is working (tested on a Redox bought from Falbatech)
- TRRS Pad connections seem OK using a multimeter
- D0 Pin connection seems OK
- both Pro Micros light up
- when typing on the TRRS-connected half, every once in a while a character might actually be send
- I am using the 3D printed case

When mixing and matching with the Falbatech Redox (using the same firmware) the issue persists, only the connected half is detected. The full Falbatech one is working as expected. What would be the best course of action to debug the issue, preferably without having to desolder the pro micros and key switches?

joe-batt, 2023-02-27:
I did some further testing. I am pretty confident the solder joints should be ok. Every single Key is working and if I measure the resistance between D0 and D1 on both boards, in comes out to 1.5 Ohm. The Pro Micros are the USB C variant.

The new Keyboard uses the rev1 PCBs  from Github and is without underglow, the Falbatech one is prebuilt with underglow. Both are using the exact same firmware using `MASTER_LEFT`. If I connect one half of the Falbatech board as slave, the underglow stays off. It does not matter which half of the Falbatech I use as slave or which of the new boards I use as master. The Falbatech Board uses 4.7K Ohm resistors on the left side, while I have none at all.

What's bothering me is that on the slave side, I have only 2.7V between VCC and GND.

joe-batt, 2023-02-27:
The issue appears is definitely the the power transfer. When I force slave/master as described in [#33](https://github.com/mattdibi/redox-keyboard/issues/33#issuecomment-523488251) and power both sides, it's working as expected. In fact I am typing on the keyboard right now.

I'll still leave this open for now, as I am still open for advice how to rectify the original issue.

joe-batt, 2023-02-28:
Turns out the problem existed between keyboard and chair. The TRRS sockets are pretty firm, the plug appears to click into place, but there is still 1mm or so left before it actually clicks into place, so the tip had barely any connection.

Closed 2023-02-28.

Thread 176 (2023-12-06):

Help - Keys not registering

TheJltres, 2023-12-06:
Hi there!

This is my first keyboard and i have very little experience soldering, so I'm pretty sure I'm missing something or even doing something wrong, but I cant see what it is.
I started with the right keyboard, so I soldered all the diodes, the jack and the two resistors. I don't know i the two resistors are needed because I will not put any LED.

The black part of all the diodes is facing left (except 3 that is facing down because they are vertical)

Back
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

Front
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

Now i wanted to test the ProMicro USB-C that I've got, so i flashed and put it with the pins. I did not want to solder the ProMicro until i could test everything works.
So i put it like so, and "some" keykcaps on the other side. All keycaps are hotswapable, but they are not solded at the moment.
(The plastic is to tilt it a bit for the picture. I'm sure i doesn't work even when all the pins are full in the ProMicro)
I also tried to fllip the ProMicro and face it the other way
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

With all this, i plug it to the PC and it's picked up, but it's not registering any key on qmk configurator or PC :(
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

The ProMicro is workinig, if i short two pins, it shows a key on qmk, but it's not working if i click a key mounted on the pcb
I haven't soldered the Reset button, I plan to do it, but it's required?
Do i need to solder the ProMicro to test if it's working?
Do i need to solder all the Mill-max pins to see if it's working?
Did i something wrong? Do i need to do something different?

Thanks!

TheJltres, 2023-12-06:
It seems I needed to solder the ProMicro 😁

Closed 2023-12-06.

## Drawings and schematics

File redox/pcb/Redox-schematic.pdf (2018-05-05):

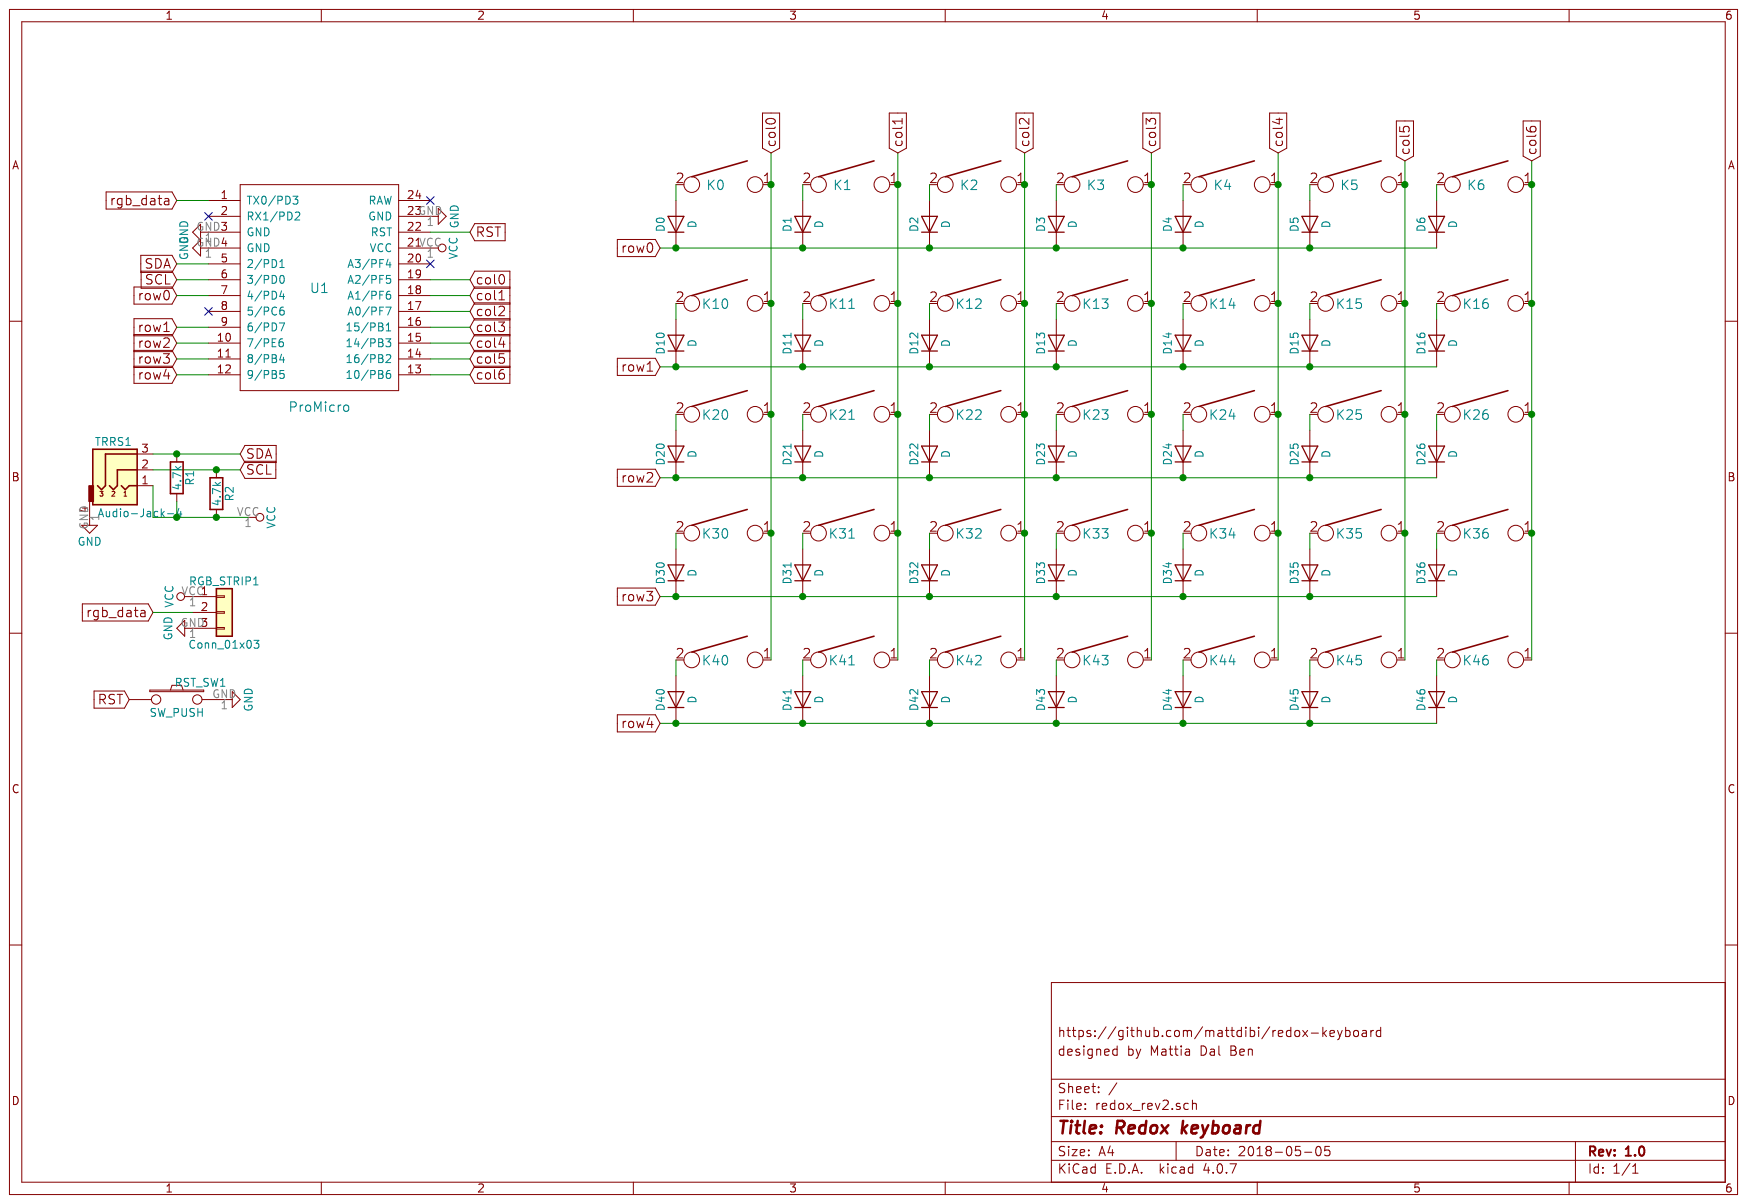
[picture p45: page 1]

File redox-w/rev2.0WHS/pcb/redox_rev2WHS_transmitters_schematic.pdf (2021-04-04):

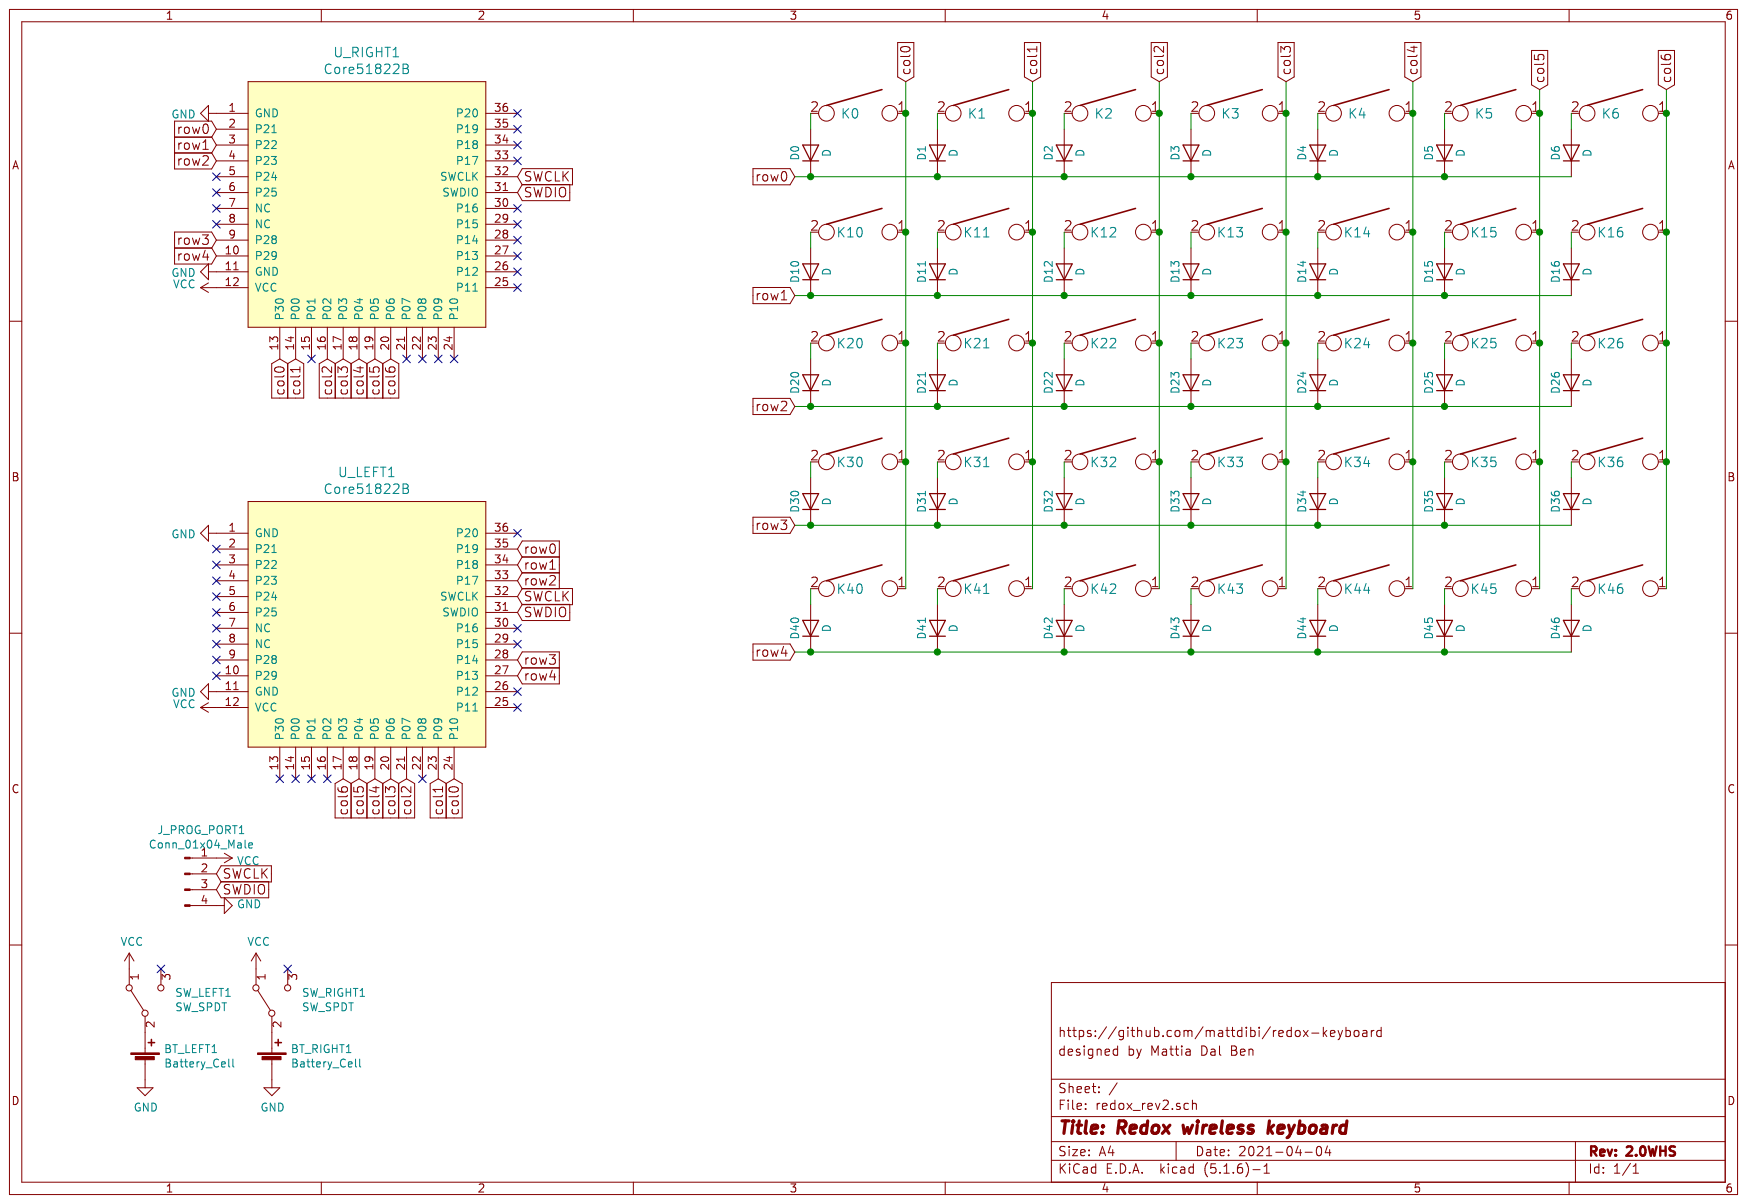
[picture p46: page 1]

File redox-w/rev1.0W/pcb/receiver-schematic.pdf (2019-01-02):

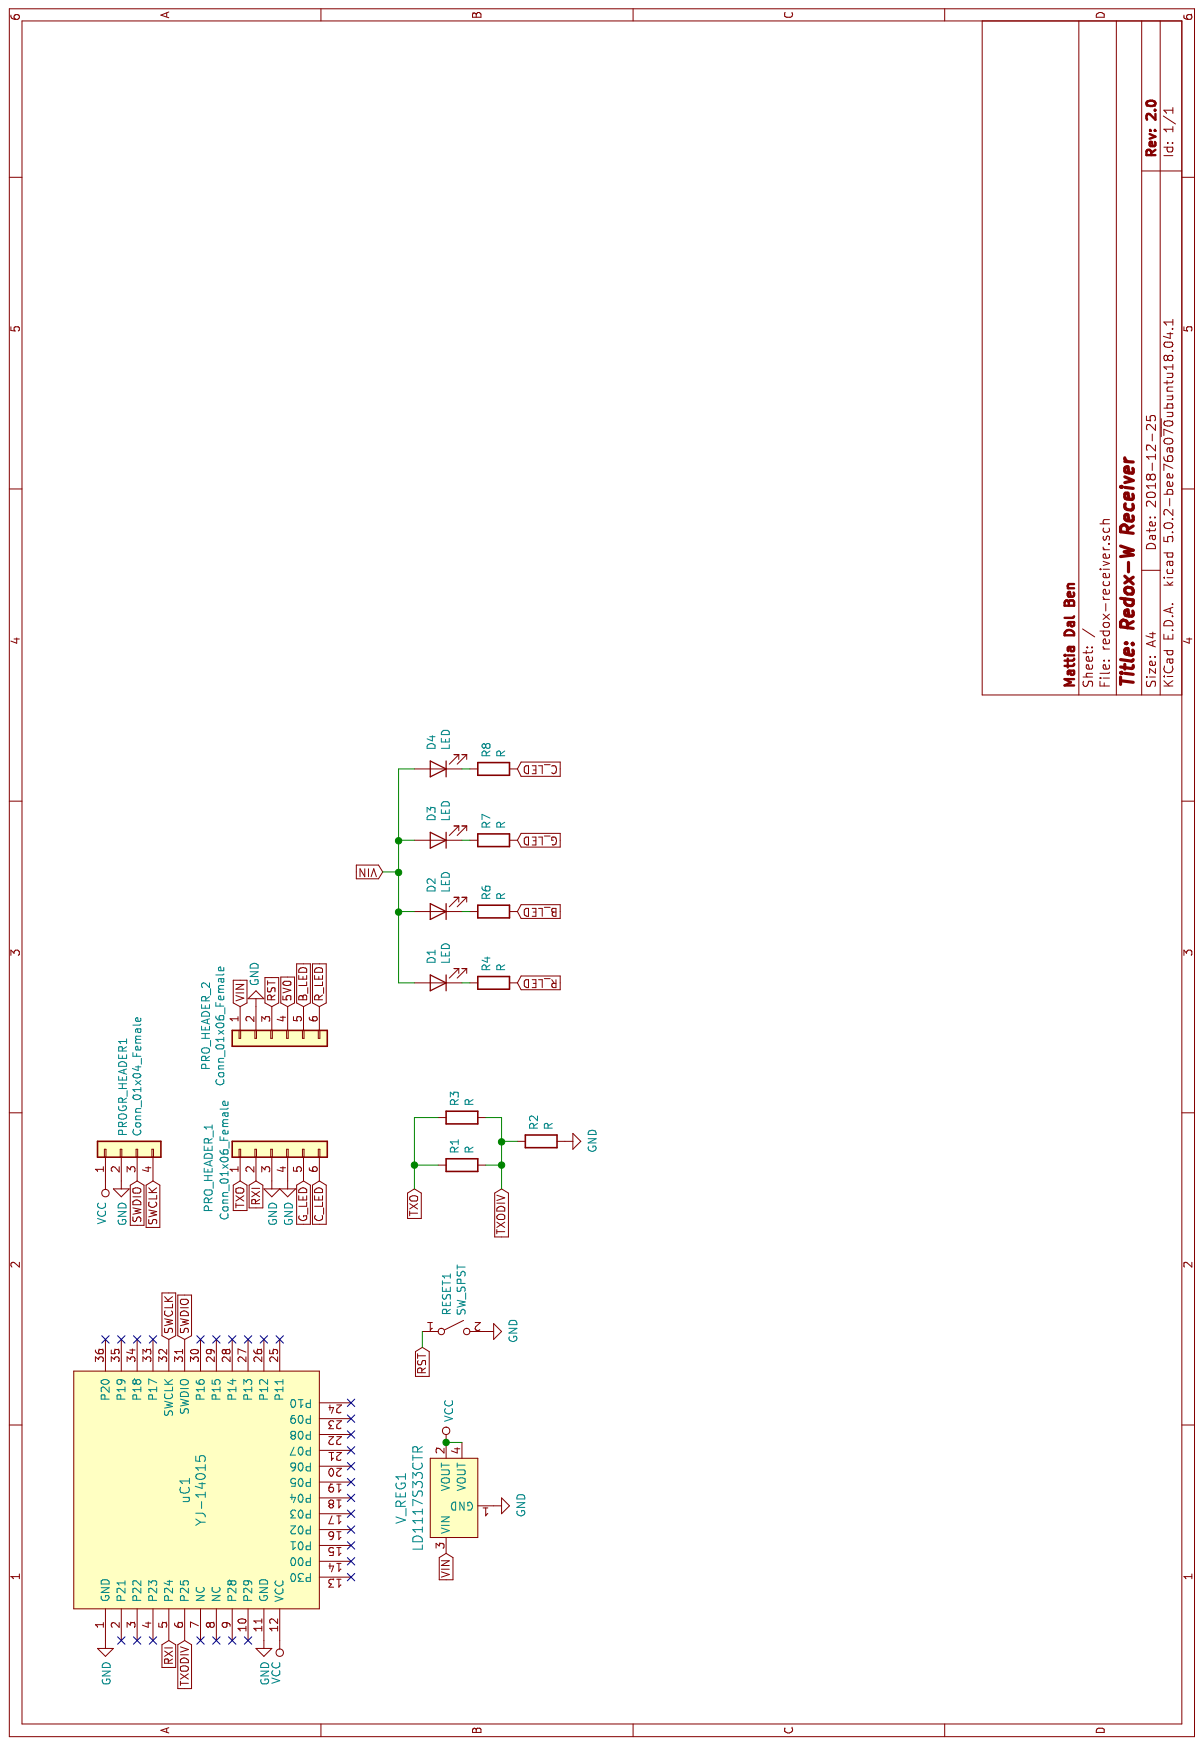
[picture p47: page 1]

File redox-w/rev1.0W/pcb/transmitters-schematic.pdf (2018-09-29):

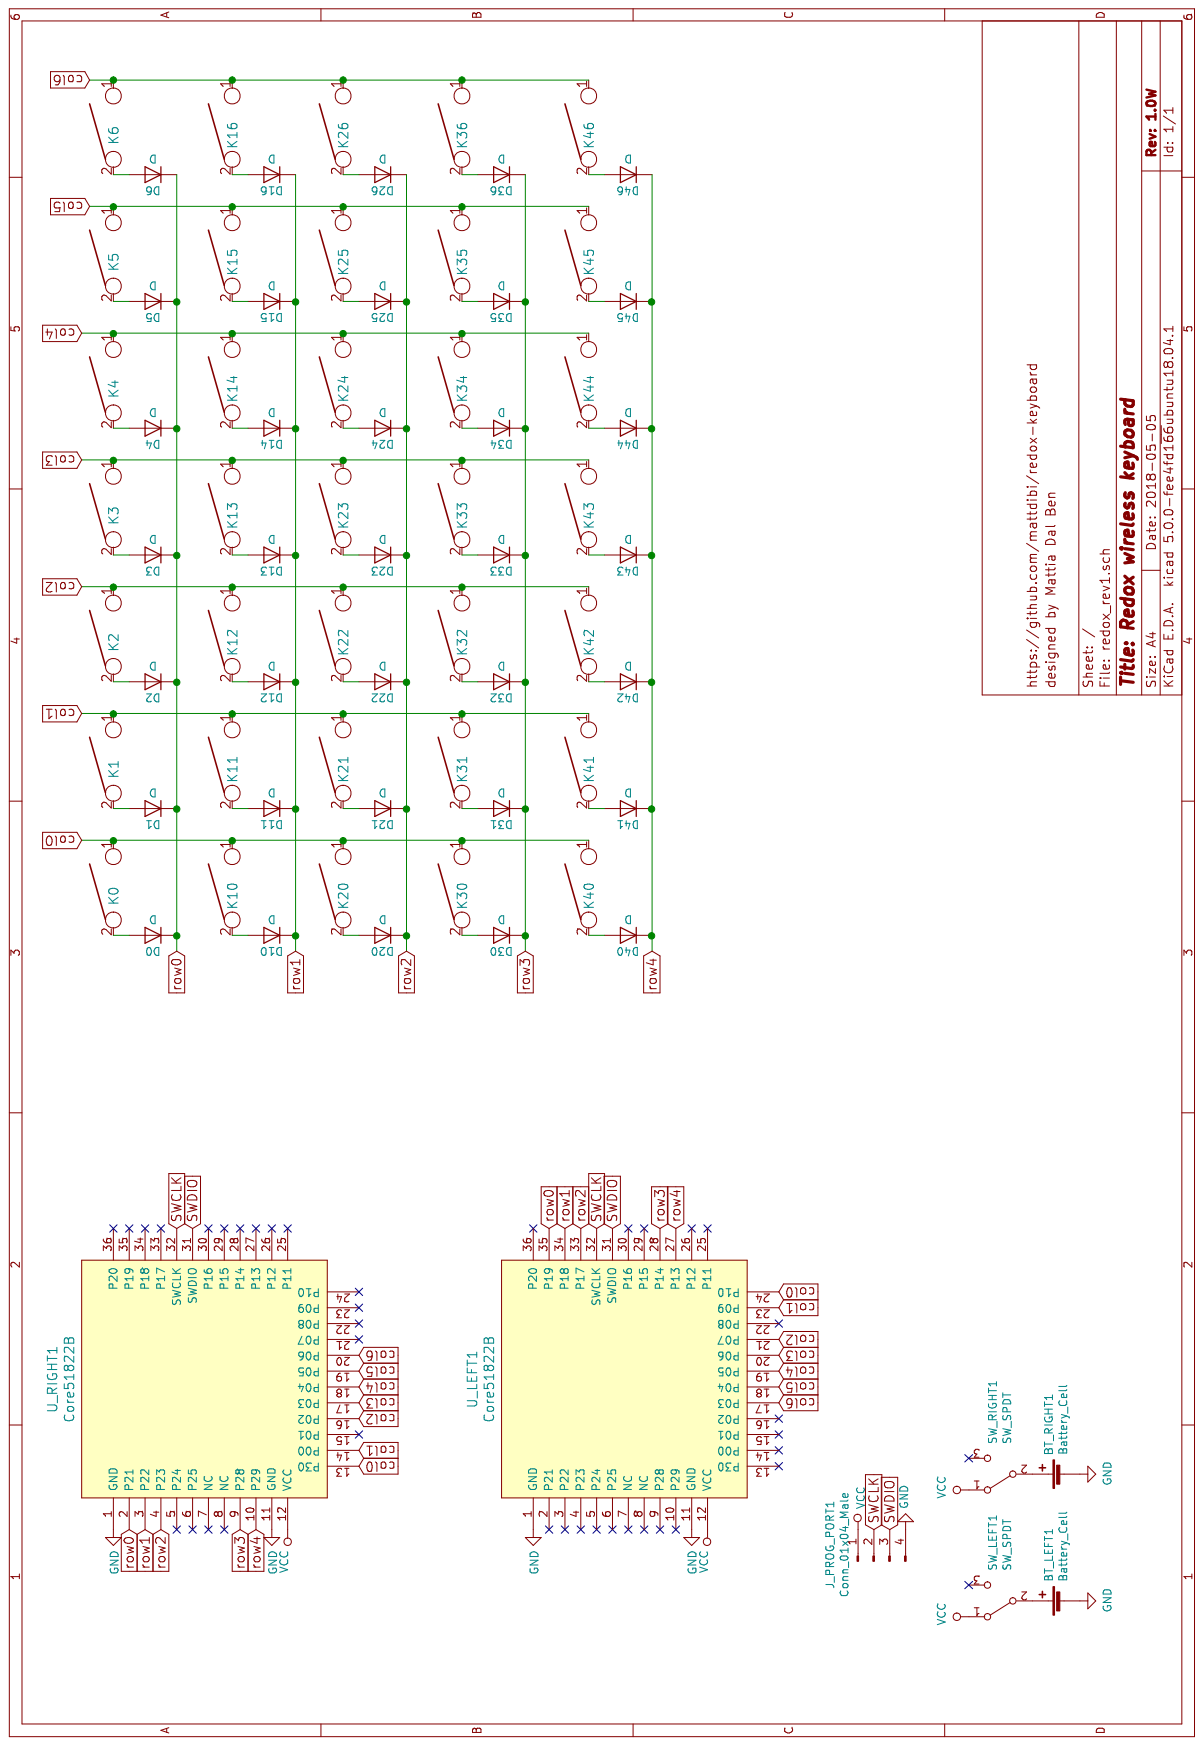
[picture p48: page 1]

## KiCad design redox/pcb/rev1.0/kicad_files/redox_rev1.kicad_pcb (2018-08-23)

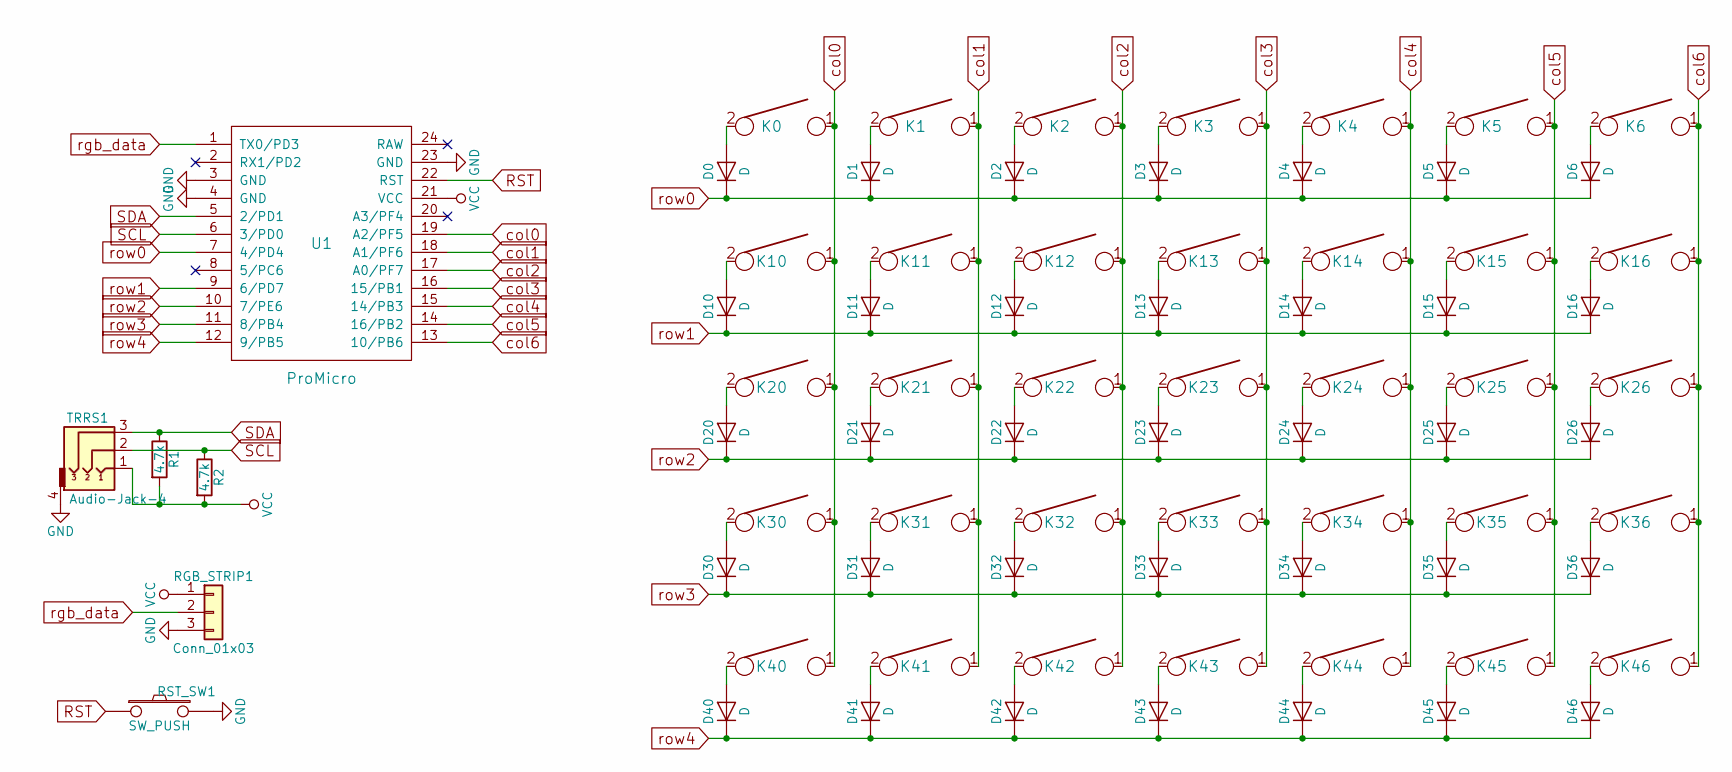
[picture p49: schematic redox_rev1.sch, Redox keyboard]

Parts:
D0, D1, D2, D3, D4, D5, D6, D10, D11, D12, D13, D14, D15, D16, D20, D21, D22, D23, D24, D25, D26, D30, D31, D32, D33, D34, D35, D36, D40, D41, D42, D43, D44, D45, D46: D; Diode-dual
K0, K1, K2, K3, K4, K5, K6, K10, K11, K12, K13, K14, K15, K16, K20, K21, K22, K23, K24, K25, K26, K30, K31, K32, K33, K34, K35, K36, K40, K41, K42, K43, K44, K45, K46: KEYSW; Hybrid_PCB_100H_Dual_hole-nosilk
R1, R2: 4.7k; Resistor-Compact
RGB_STRIP1: Conn_01x03; Pin_Header_Straight_1x03_Pitch2.54mm
RST_SW1: SW_PUSH; SW_PUSH_6mm_h4.3mm
TRRS1: Audio-Jack-4; TRRS-PJ-320A-dual
U1: ProMicro; ArduinoProMicro

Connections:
GND: RGB_STRIP1.3, RST_SW1.2, TRRS1.4, U1.3 (GND), U1.4 (GND), U1.23 (GND)
unnamed: D0.2 (A), K0.2
unnamed: D1.2 (A), K1.2
unnamed: D2.2 (A), K2.2
unnamed: D3.2 (A), K3.2
unnamed: D4.2 (A), K4.2
unnamed: D5.2 (A), K5.2
unnamed: D6.2 (A), K6.2
unnamed: D10.2 (A), K10.2
unnamed: D11.2 (A), K11.2
unnamed: D12.2 (A), K12.2
unnamed: D13.2 (A), K13.2
unnamed: D14.2 (A), K14.2
unnamed: D15.2 (A), K15.2
unnamed: D16.2 (A), K16.2
unnamed: D20.2 (A), K20.2
unnamed: D21.2 (A), K21.2
unnamed: D22.2 (A), K22.2
unnamed: D23.2 (A), K23.2
unnamed: D24.2 (A), K24.2
unnamed: D25.2 (A), K25.2
unnamed: D26.2 (A), K26.2
unnamed: D30.2 (A), K30.2
unnamed: D31.2 (A), K31.2
unnamed: D32.2 (A), K32.2
unnamed: D33.2 (A), K33.2
unnamed: D34.2 (A), K34.2
unnamed: D35.2 (A), K35.2
unnamed: D36.2 (A), K36.2
unnamed: D40.2 (A), K40.2
unnamed: D41.2 (A), K41.2
unnamed: D42.2 (A), K42.2
unnamed: D43.2 (A), K43.2
unnamed: D44.2 (A), K44.2
unnamed: D45.2 (A), K45.2
unnamed: D46.2 (A), K46.2
RST: RST_SW1.1, U1.22 (RST)
SCL: R2.1, TRRS1.2, U1.6 (3/PD0)
SDA: R1.1, TRRS1.3, U1.5 (2/PD1)
VCC: R1.2, R2.2, RGB_STRIP1.1, TRRS1.1, U1.21 (VCC)
col0: K0.1, K10.1, K20.1, K30.1, K40.1, U1.19 (A2/PF5)
col1: K1.1, K11.1, K21.1, K31.1, K41.1, U1.18 (A1/PF6)
col2: K2.1, K12.1, K22.1, K32.1, K42.1, U1.17 (A0/PF7)
col3: K3.1, K13.1, K23.1, K33.1, K43.1, U1.16 (15/PB1)
col4: K4.1, K14.1, K24.1, K34.1, K44.1, U1.15 (14/PB3)
col5: K5.1, K15.1, K25.1, K35.1, K45.1, U1.14 (16/PB2)
col6: K6.1, K16.1, K26.1, K36.1, K46.1, U1.13 (10/PB6)
rgb_data: RGB_STRIP1.2, U1.1 (TX0/PD3)
row0: D0.1 (K), D1.1 (K), D2.1 (K), D3.1 (K), D4.1 (K), D5.1 (K), D6.1 (K), U1.7 (4/PD4)
row1: D10.1 (K), D11.1 (K), D12.1 (K), D13.1 (K), D14.1 (K), D15.1 (K), D16.1 (K), U1.9 (6/PD7)
row2: D20.1 (K), D21.1 (K), D22.1 (K), D23.1 (K), D24.1 (K), D25.1 (K), D26.1 (K), U1.10 (7/PE6)
row3: D30.1 (K), D31.1 (K), D32.1 (K), D33.1 (K), D34.1 (K), D35.1 (K), D36.1 (K), U1.11 (8/PB4)
row4: D40.1 (K), D41.1 (K), D42.1 (K), D43.1 (K), D44.1 (K), D45.1 (K), D46.1 (K), U1.12 (9/PB5)

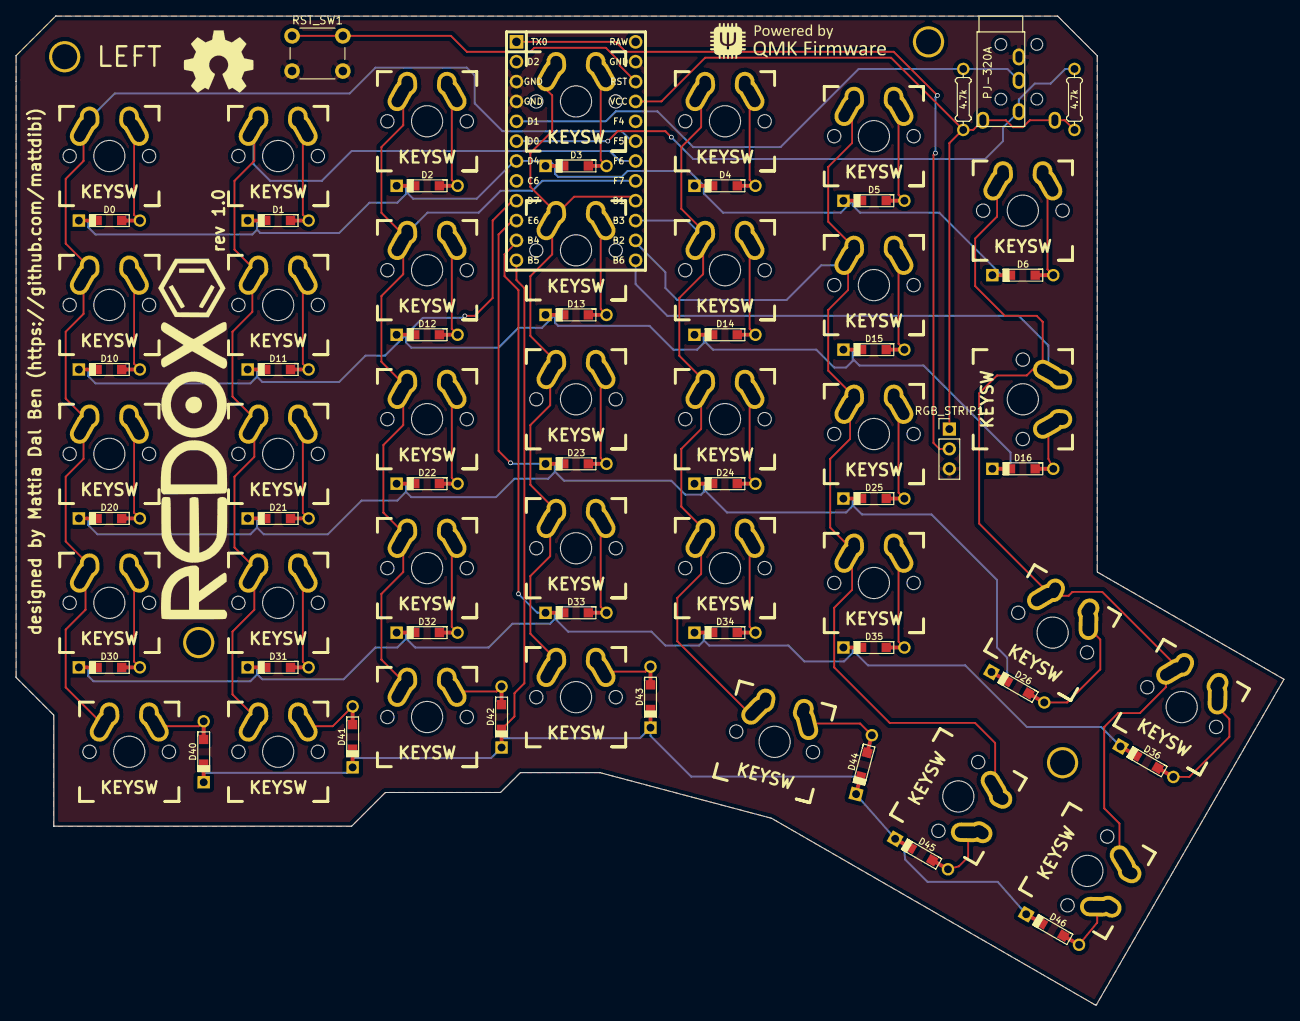
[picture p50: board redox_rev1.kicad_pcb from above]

Board: 2 copper layers, 162.2 x 126.5 mm, 80 parts (0 on the bottom side), 53 nets.

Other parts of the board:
HOLE_M3, HOLE_M3#2, HOLE_M3#3, HOLE_M3#4: VAL**; HOLE_M3

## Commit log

2018-03-24 Added assembly instructions
2018-03-24 Swtiched to table for BoM
2018-04-28 Updated assembly instructions
    Added right hand controller installation details plus pictures.
    Improved images of rgb-underglow installation.
2018-04-30 Added 3D printable case files
    [RedoxRev2BottomLeft.STL, RedoxRev2BottomRight.STL, RedoxRev2TopLeft.STL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]
2018-04-30 Renamed files
    [RedoxRev1BottomLeft.STL, RedoxRev1BottomRight.STL, RedoxRev1TopLeft.STL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]
2018-05-05 Added schematic
2018-05-05 Added switch location image
2018-05-19 Added .dxf and .svg files
    Added .dxf and .svg files to make it easier for people to create their own cases.
    [redox_rev2-brd.dxf]
2018-06-03 Added Falbatech's case instructions
2018-06-03 Added shameless donate button
2018-06-05 Added Lenbok's Iris-inspired Redox case
2018-06-30 Added daily driver pic
2018-08-23 Added PCB files
    [redox_rev1.kicad_pcb, redox_rev1.sch]
2018-08-25 Added software links for Redox wireless
2018-09-22 Moved redox instruction to redox/ folder
    [RedoxRev1BottomLeft.STL, RedoxRev1BottomRight.STL, RedoxRev1TopLeft.STL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]
2018-09-22 Added Redox Wireless schematic
2018-09-22 Added 3D printable plate files
    [RedoxWTopLeft.STL, RedoxWTopRight.STL]
2018-09-23 Added new case version
    [RedoxWTopLeft.STL, RedoxWTopRight.STL, RedoxWirelessRev1BottomLeft.STL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]
2018-09-29 Added Wireless Redox assembly instructions
2018-09-29 Added assembly images
2018-10-14 Added receiver assembly instructions
2018-10-14 Added receiver assembly notes
2018-10-20 Added gerber files
2018-10-20 Added KiCad project files
2018-11-10 Improved bottom case for Wireless Redox rev.1.0
    [RedoxWirelessRev1BottomLeft.STL, RedoxWirelessRev1BottomRight.STL, RedoxWirelessRev1TopLeft.STL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]
2018-11-10 Improved case for Redox rev.1.0
    [RedoxRev1BottomLeft.STL, RedoxRev1BottomRight.STL, RedoxRev1TopLeft.STL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]
2018-11-17 Added 3D printed case materials detail
2018-11-24 Added other assembly guides
2019-01-02 Redox receiver (#12)
    * Added redox-w receiver files.
    * Updated receiver BOM
    * Removed old instructions
    * Improved BOM. Added `Resistor values` `Default configuration` sections
    * Added receiver PCB images
    * Image resize.
    * Fixed wrong compilation instruction
    * Improved firmware instructions
    * Added Redox-W firmware diagram sources
    * Added battery usage section
    * Fixed broken image link
    * Added Receiver assembly instructions
    * Added Receiver assembly images
    * Added notes
    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
2019-02-16 Redox w firmware instructions (#16)
    * Added udev rules for ST-Link debugger
    * Added first draft of the instructions
    * Added some more screenshots
    * Added ST-Link debugger wiring pic
2019-02-18 Document the Mill-Max and Peel-A-Way hotswap mod (#17)
    * Added Redox rev. 1 hot swap mod instructions
    * Hot swap mod typo fixes
    * Corrected hot swap mod finished image
2019-05-05 Added link to Travel-friendly Redox Keyboard case by Fosk_LL
2019-05-05 Added links to new Falbatech's Redox wireless cases
2019-08-04 Updated Redox-Wireless precompiled hexes to new version
2019-08-25 Added Redox keyboard case (high profile) by Michele Ferri link
2020-06-10 feat: Added STL for switch (#62)
    Switch slots into hole in the front of case. It has a slot for the switch specified in the BOM and a pincer for a top mount switch.
    [RedoxWirelessSwitch.stl]
2020-06-20 Feature: CAD files (#64)
    * Added wireless case CAD files
    * Added wired CAD files
    [RedoxRev2.step, RedoxWirelessRev1.0Test.step]
2020-07-05 Feature: added tilt stand and receiver case STLs (#65)
    * feat: Added STL for switch
    * IO switched to correct way around
    Had them backward in first commit
    * Reciever made bigger to fit
    * Feat: Added a 3d printable stand
    Angles are 8 degrees of tilt and 8 degrees of roll. Comfy for me, but could add others.
    * Improved STL and removed keymaps
    Added nice snap fittings to the receiver case and made the angle stand a lot cleaner, and sections to put non-slip feet on
    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
    [RedoxWirelessRev1ReceiverBottom.stl, RedoxWirelessRev1ReceiverTop.stl, RedoxWirelessSwitch.stl]
2020-11-21 Add CAD file for tray-mounted plate (#76)
    [RedoxRev2Top_2d.dxf]
2021-01-02 Docs update (#79)
    * Added note about VIA compatibility
    * Updated shameless donate button
    * Added KLE layout image
    * Added keycaps section
    * Added pimpmykeyboard Redox keyset link
2021-02-20 Docs refactoring and update (#84)
    * Added Redox Neodox case links
    * Refactored README links
    * Renamed wireless link for consistency
    * Changed titles for consistency
    * Added brief description of the keyboards
    * Removed redundant description
2021-04-04 Feature: Redox rev.2.0WHS (#99)
    * Moved rev1.0W files in relative folder
    * Added rev2.0WHS PCB files in new folder
    * Added rev2.0WHS case files
    * Added docs
    * Fixed broken image urls
    * Fixed broken image urls
    * Updated summary
    * Added 3D printed case notes
    * Added 3d printed case image
    * Fixed screw length
    * Added transmitter installation instructions
    * Added some more images
    * Improved assembly instructions
    * Added 2.0WHS references to landing page
    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
    [BackplateL.stl, FrontplateL.stl, OpenBackplateL.stl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]
2021-04-05 Refactoring: Docs (#100)
    * Merged READMEs into a single one
    * Added note about battery usage
    * Removed unnecessary columns
    * Added link to case
    * Added details about Pro Micro installation
    * Fixed URL
    * Added link
2021-04-05 Added PCB manufacturing links
2021-04-06 DOCS: Fix typo in current consumption formula for redox-w (#102)
    * DOCS: Fix typo in current consumption formula for redox-w
    * Added missing change in units
2021-11-15 Update README.md (#120)
    Added warning to make sure that promicros is alright before start. Seriously, guys unsoldering them afterwards is painfull 😞
2022-01-16 Docs: ZMK update (#127)
    * Added info about ZMK wireless implementation
    * Fixed typo in url
    * Added redox wireless implementations comparison
    * Moved wireless implementations details into their own section
    * Fixed issues in markdown syntax
    * Fixed battery life section
2022-03-25 Updated 3D printable cases (#135)
2022-09-28 Add link to wooden case build (#155)
2023-02-03 Added remixed version of tilted case (#161)

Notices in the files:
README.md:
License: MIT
